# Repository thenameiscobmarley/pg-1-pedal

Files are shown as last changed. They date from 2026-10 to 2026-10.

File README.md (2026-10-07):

# PG-1 pedal

A DIY stereo audio pedal built around a **Daisy Seed3**, in a white Hammond 1590XX from Tayda. A 2.4" colour
touchscreen, four endless push-knobs, three footswitches and a chain of sound tools:

`in -> hum + hiss (with learn) -> input auto-level -> dynamic eq -> compressor -> multiband -> clarity + bass ->
saturation -> de-harsh -> stereo width -> takeback -> quiet loudness -> [bypass] -> ear + speaker safety -> out`

plus a visualizer, health checks (it tells you when something is wrong), 8 saved configs, a fair level-matched
A/B footswitch, and everything remembered over power-off.

The same core code runs on the pedal and in a **Carla / VST3 plugin** with a real-size 3D model of the pedal, so you
can try every screen and sound on a PC first.

## What's where

| Folder | |
|---|---|
| `PG-Pedal-1/01-Questions-and-Specs` | the spec |
| `PG-Pedal-1/02-Parts-and-Cart` | Tayda cart files + parts list (with the few parts Tayda doesn't sell) |
| `PG-Pedal-1/03-Drill-Template` | drill positions for drill.taydakits.com |
| `PG-Pedal-1/04-Top-Artwork` | the UV print (CMYK PDF for Tayda) and previews |
| `PG-Pedal-1/05-Wiring-and-Schematics` | **wiring-diagram.png** (every wire + both ground chains), layout drawings, WIRING.md |
| `PG-Pedal-1/06-Firmware-DaisySeed` | the firmware (`pg1/`) and its shared core (`pg1/core/`) |
| `PG-Pedal-1/10-Carla-Plugin` | the JUCE plugin with the 3D pedal |
| `PG-Pedal-1/11-Wiring-Bench` | `wiring-bench.html`: practise the wiring in a browser; a virtual pedal tells you what's wrong |
| `_Tools/pg_generate.py` | one script makes the drill table, artwork, drawings and the splash logo from the geometry at its top |
| `_Tools/tayda_upload.py` | uploads the drill + print designs to drill.taydakits.com (asks for your Tayda login) |
| `third_party/HardwareKit` | the 3D hardware UI module the plugin uses (Apache-2.0) |

## Building

Firmware (Linux):

```
git submodule update --init           # libDaisy v9.0.0 + DaisySP
cd PG-Pedal-1/06-Firmware-DaisySeed
(cd libDaisy && make -j"$(nproc)") && (cd DaisySP && make -j"$(nproc)")
cd pg1 && make -j"$(nproc)"           # build/pg1.bin (runs from the Daisy bootloader: see the firmware README)
```

Plugin: needs JUCE (https://juce.com, licensed separately).

```
cd PG-Pedal-1/10-Carla-Plugin
cmake -B build -DCMAKE_BUILD_TYPE=Release -DJUCE_PATH=/path/to/JUCE
cmake --build build -j"$(nproc)"
```

Artwork and drawings: `pip install fonttools`, then `python3 _Tools/pg_generate.py` (needs `rsvg-convert` and
ImageMagick for the PNG/PDF previews).

## Credits

- libDaisy and DaisySP by Electro-Smith (MIT), as git submodules
- Nunito font (SIL Open Font License, `_Tools/fonts/OFL.txt`)
- HardwareKit (Apache-2.0, `third_party/HardwareKit`)
- JUCE is not included; it has its own licence

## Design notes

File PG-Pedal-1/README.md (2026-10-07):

# PG-1: pg audio programmable stereo pedal (Daisy Seed3)

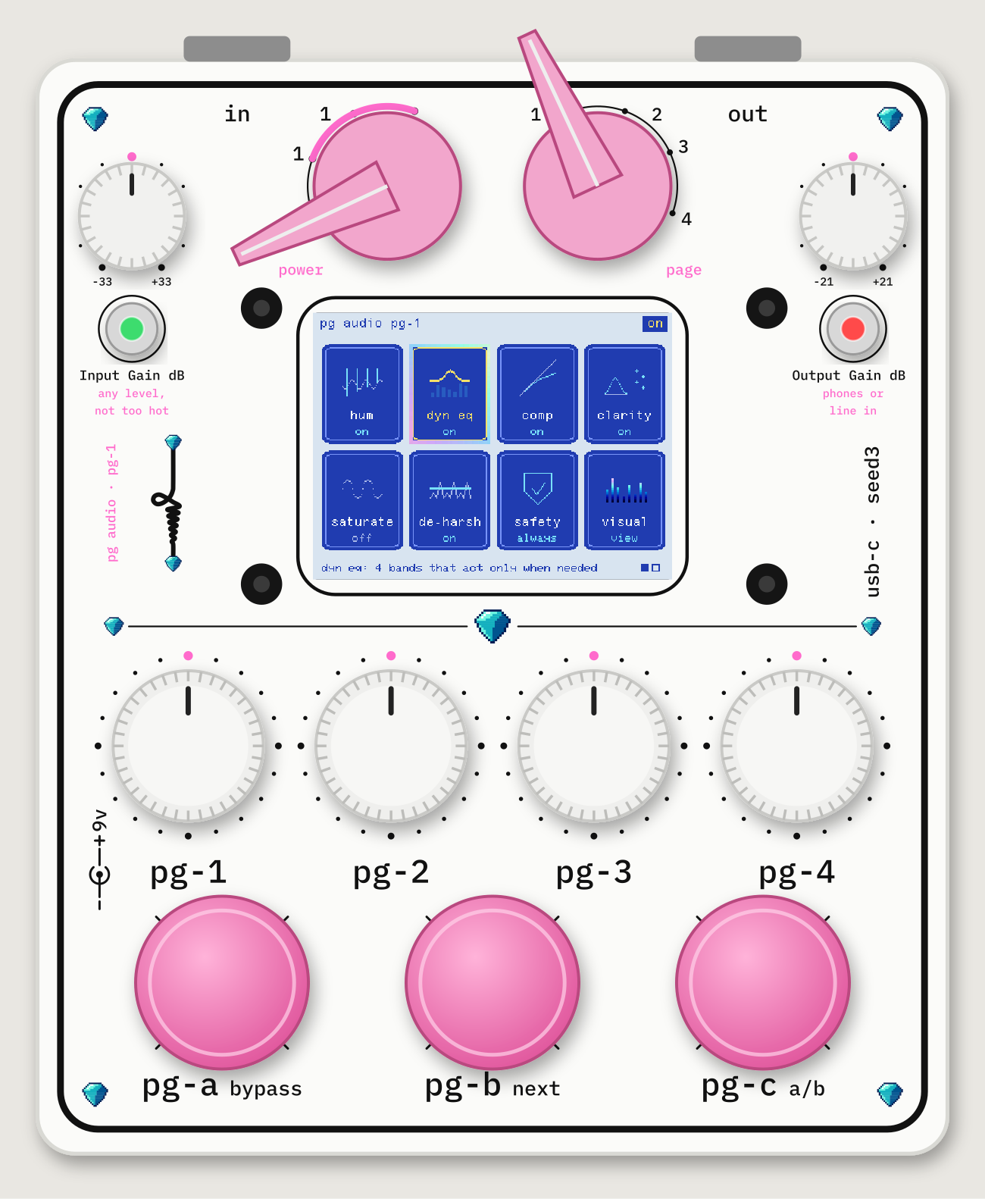
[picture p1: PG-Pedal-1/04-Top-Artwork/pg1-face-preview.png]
preview


## Order it (3 steps)
1. **Parts:** upload `02-Parts-and-Cart/tayda-cart-import.csv` on the Tayda cart page (Import → Add from file → Replace current cart).
   Buy the Seed3 (with headers), a 9V adapter and solder separately (`02-Parts-and-Cart/BOM.md`).
2. **Drilled box + printed top:** run `python3 ../_Tools/tayda_upload.py`. It logs in to your drill.taydakits.com account and creates
   the drill template (17 holes + screen window + Seed3 window) and the UV print template for you. Then check both previews on the dashboard and create the order there.
   (By hand instead: `03-Drill-Template/DRILL-ORDER.md` + `04-Top-Artwork/UV-PRINT.md`.)

## Build it
`05-Wiring-and-Schematics/WIRING.md` has one table: every wire from each part to its Seed3 socket pin. It also shows the plug-in Seed3 cartridge in the left wall and covers the first flash.
`06-Firmware-DaisySeed/pg1.bin` is ready to flash: a stereo delay with auto-leveling that uses every control.

Using it with your Fifine SC3 (line out → pedal → headset): `USING-WITH-FIFINE-SC3.md`.

## Try it on your PC first
`10-Carla-Plugin/` is the PG-1 as a VST3 for Carla (and a standalone app): a 3D pedal with the **same screen, knobs, touch and sound** as the real one, because both run the same core code. Installed at `~/.vst3/PG-1 Pedal.vst3`.

## Folders
| Folder | What's inside |
|---|---|
| 01-Questions-and-Specs | final spec + your answers |
| 02-Parts-and-Cart | Tayda import CSV, full BOM with prices |
| 03-Drill-Template | drill.taydakits.com entry sheet, CSV, 1:1 paper template |
| 04-Top-Artwork | UV print PDF, editable SVG, mockup |
| 05-Wiring-and-Schematics | wiring, interior layout, depth check, perfboard drill guide |
| 06-Firmware-DaisySeed | libDaisy project + libDaisy v9.0.0 + DaisySP |
| 07-Datasheets | Seed3, screen, encoder, footswitch, jack |
| 08-Build-Photos | for your photos |
| 09-Parts-Visualizer | Parts Bench page + 3D web model |
| 10-Carla-Plugin | the PG-1 as a VST3 for Carla + standalone app |

All drawings and the artwork are generated from one script (`../_Tools/pg_generate.py`), so the holes and the print always match.

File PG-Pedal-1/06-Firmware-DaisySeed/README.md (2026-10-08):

# PG-1 firmware

`pg1/` is a libDaisy project. The pin map lives in one block at the top of `src/main.cpp`; everything
else (screen, controls, DSP) is in `pg1/core`, the same code the Carla plugin runs.

## The tabs (in signal order)

Home page 1 has 8 tabs; page 2 (turn past the last tab, or tap the dots bottom-right) has **input**, **health**, **takeback**, **width**, **loudness**, **config**, **multiband** and **pid**.

`in -> hum -> input -> dyn eq -> comp -> multiband -> clarity -> saturate -> de-harsh -> width -> takeback -> loudness -> anti-duck -> [bypass] -> safety -> out`

**Will it fit on the Seed3?** Checked on an emulated Cortex-M7 with the firmware's own compiler flags (`_Tools/seed3-bench`:
`./build.sh && python3 seed3_load.py`, per tab: `python3 stages.py`). Worst case (every tab on, pid steering everything, clarity with
10 bands): ~5,900 instructions per sample = **~59 % of the audio time** at a typical 1 clock per instruction (~89 % if it were 1.5).
Default settings: ~51 %. The first version of these features measured 102-153 % (would not have run); fast exp/log, filters that
compute only the output they need, slower-rate detectors, a sliding-minimum limiter and skipping idle filters brought it down.
The plugin's cpu health check uses these numbers, so it warns when the pedal would.

**Anti-duck (always on, every stage):** nothing turns the whole track down because the bass got heavy.
- Every detector that can lower the whole sound (input auto-level, comp, de-harsh's comfort dip, loudness follow, the safety stage's ear meters and blast guard) listens through a steep 150 Hz high-pass, so bass doesn't count as "loud".
- The safety peak limiter splits at 120 Hz: a peak that comes from the bass is taken out of the bass alone (up to -12 dB); only what that can't fix lowers everything.
- A false "infrasonic out" mute on sudden loud bass notes is fixed (a slow wobble the limiter can leave is filtered out; that check now needs 1 s, not 0.3 s).
- A final guard compares the mids + highs coming out against going in. If they still dip while the bass is heavy, it lifts everything above 120 Hz back (at most +6 dB, before the safety limiter). Ordinary compression of loud parts is left alone, and it re-learns whenever you change a setting.
- Tested on a sudden heavy bass drop: the rest of the track used to dip 7-12 dB for a moment; now at most 0.3 dB. The *levels* view shows *bass lim* and *anti-duck* live.

| Tab | What it does | Knobs pg-1 / pg-2 / pg-3 / pg-4 |
|---|---|---|
| **input** (page 2) | Auto-level: brings any source to the same working level. Quiet ones go up (at most *boost*), hot ones down (at most *cut*). It moves slowly and holds still in silence, so it never pumps up noise. A yellow **in clip** chip shows in the title on every page when the source is hotter than the Seed3's input can take. Only turning the source down fixes that. | target / boost / cut / speed |
| **hum** | *auto / 50 / 60*: finds mains hum and notches it plus 5 harmonics, only as deep as the hum really is, and turns the top end down in quiet parts. ***learned***: set pg-1 to **learn** and push it (or tap **learn** on the screen) while **only the hum / hiss is playing**. In 3 s it learns every tone to the exact frequency (mains hum, monitor or charger whine) and the hiss level in 8 bands. Then it notches those tones all the way down and gates each band to silence whenever nothing louder than that noise plays. It tells you if music or talking spoiled the learning. Runs first, before the auto-level. | mode / hum depth / hiss cut / hiss threshold (learned: margin) |
| **dyn eq** | 4 bands, each moves when that band gets loud. | freq (hold + turn = q) / gain / thresh / range |
| **comp** | Smooth stereo compressor, soft knee, bass-safe sidechain, auto make-up, auto release. | thresh / ratio / attack / release (0 = auto) |
| **clarity** | Bass: *thump* (a short low lift on each kick), *detail* (the bass's own harmonics, so bass is heard on any speaker), *warmth* (a steady low lift). Clarity: **up to 10 bands that place themselves**. 20 detectors listen half an octave apart; where the sound bulges above its overall trend (a ringing note, a boxy spot) a band moves there and cuts, where it sags (a hollow) a band moves there and lifts. Each band glides its own frequency, width (q) and gain, so it follows the music. Bands stay between ~50 Hz and ~12 kHz. **Mode** (hold pg-1 + turn, or tap *mode*): *dynamic* (cuts and lifts), *add* (only lifts), *normalise* (stronger and slower). The graph shows each band as a dot with a bar as wide as its q (blue = lift, pink = cut). | thump (+dB per hit) / detail / clarity (most each band may cut or lift, dB; **hold pg-3 + turn = how many bands, 1-10**) / warmth (+dB lows) |
| **saturate** | Tape / tube curve, anti-aliased, level-matched. Off by default. | drive / even / tone / mix |
| **de-harsh** | After everything: finds harsh spots between 2 and 8.5 kHz and cuts just those, plus softens 3 kHz as it gets loud. | depth / sens / speed / comfort |
| **safety** | Always on, even in bypass: **only 20 Hz - 19.5 kHz can leave** (very steep filters at both ends; what's outside human hearing is removed, and if it ever reached the output anyway the pedal would mute and say so), woofer and tweeter power limits (coils stay cool), a long-term loudness cap for your ears, a blast guard for sudden jumps, a 1 ms look-ahead limiter and a hard ceiling. Broken numbers or a stuck DC level mute the output for 150 ms and reset every filter. | ceiling / ears / woofer / tweeter |
| **multiband** (page 2) | 4 bands (split at 120 Hz, 1 kHz, 6 kHz; the untouched bands add back to the original exactly). Each band holds back its own peaks, relative to its own recent level, so a boomy note, a muddy burst, a harsh hit or a sharp "s" gets tamed without touching the rest. | bass / low mids / high mids / highs (how firmly) |
| **takeback** (page 2) | Gives back what the processing took or buried, by comparing with the sound as it came in: the **punch** of hits the comp / limiter squashed, quiet **detail** (tails, room, breaths), top-end **air** that went missing, stereo **space** that shrank. Capped, so it restores rather than exaggerates. | punch / detail / air / space |
| **width** (page 2, off by default) | Wider or narrower stereo, bass kept in the middle (mono-safe), a little side air, and a guard that eases off if mono speakers would lose sound. | width / bass mono / air / guard |
| **loudness** (page 2, off by default) | At low volume ears lose bass and treble: this gives back about what they lose, more the quieter you listen (follow = quiet passages too). | listen / bass / treble / follow |
| **config** (page 2) | 8 saved configs (every sound setting + which stages are on). pg-1 picks, **push pg-1 = load**, **push pg-2 twice = save**. Theme: **pearl** (light, default) or classic **bios**. Knobs: normal / reverse. | config / save / theme / knobs |
| **visual** | Spectrum (in and out), waterfall, stereo (vectorscope + correlation + balance), levels (in / out + what each stage is taking off), **scope** (oscilloscope: the last 13 ms, triggered so a steady note stands still, auto-zoom), **bars** (31 bands with falling peak caps), **history** (in and out loudness over the last 15 s). Tap the screen for the next view. | view / fall / range / source |
| **pid** (page 2) | Listens to the processed sound and steers the settings of the groups you pick, on top of your own settings: **eq** (each band towards the target balance, ±6 dB), **comp** (threshold + ratio, towards a 12 dB peak-to-average, ±8 dB), **mband** (how firmly each band is held), **clarity** (thump / warmth + clarity, ±4 dB), **deharsh** (depth, ±6 dB), **width** (towards a correlation of 0.35, ±40 %). P reacts to how far off it is, I slowly clears what's left, D brakes fast swings; any of them can be 0.00 (all three 0.00 = no steering). In silence it holds still. Off by default (hold pg-b). The screen shows what it hears vs the target, and how far it is moving each group. | p / i / d / group (push = steer it or not; hold + turn = target tilt, dB per octave) |

The safety levels are dBFS at the pedal's output. They don't know how loud your amp is, so set them
once at a loud-but-comfortable volume: lower **ears** until it just starts easing down.

## Controls

| Control | Home | A page |
|---|---|---|
| turn a knob | move between tabs | the value in that knob's box (the boxes have the knob number in a cream chip) |
| hold a knob + turn | | fine steps (dyn eq pg-1: q) |
| push a knob | open the tab | flashes its box |
| **double-push** | | that value back to default |
| **long-push** (0.6 s) | | back to home |
| pg-a | whole-pedal bypass (safety stays on) | same |
| pg-b | next tab | dyn eq: next band. Other pages: next page |
| hold pg-b (0.6 s) | that tab's stage on / off | this page's stage on / off |
| touch | tap a tab to open it; tap "on" for bypass | tap "< home"; tap the on/off chip; tap a box = what it does; dyn eq: drag nodes, tap band chips, double-tap a node = gain 0; visual: tap = next view |
| pg-c | fair A/B: hear your untouched input at the same loudness (a cyan "a/b dry" chip shows); tap again to come back | same |
| touch d-pad (off by default) | turn it on in **config** (tap "touch d-pad", or hold pg-4 + turn), then **tap the title** to show it: arrows move between tabs, the middle opens | left / right pick a value box (yellow frame), up / down change it (hold to repeat), the middle = that knob's push (hold = home). Hides itself after 10 s |
| pg-a + pg-b held 2 s | USB flash mode | same |

## First power-up

After the logo, a short tour (4 cards, 3 s each) shows the basics: knobs, the 3 footswitches, page 2, the "!" chip. It only
ever runs once (any control skips it). The config tab's bottom line shows the model, firmware version and this pedal's ID.

## Saving

Everything (settings, the 8 configs, the learned hum / hiss) is saved to the Seed3's flash about 4 s after you stop changing
things, and comes back at power-on. The plugin keeps the same block in the DAW session.

Saves survive firmware and plugin updates: every setting is stored under a permanent name, so a new build that adds, removes
or reorders settings still loads your configs (new settings start at their defaults). When a setting's meaning changes, the
new build converts the old value. The pedal and the plugin use the same format.

## Start-up

On pitch black, the pg audio logo draws itself while slowly zooming out, "pg audio" fades in underneath, both fade away, and
the main screen fades up out of the black (about 4.5 s; any knob, switch or touch skips it). The logo is the exact curve on the
printed face (`core/PgLogo.h` is generated from `_Tools/pg_generate.py`).

## Health checks (page 2: **health**)

The pedal watches itself all the time. When something looks off, a **"! n"** chip shows in the title on every page (yellow =
warning, pink = fault; tap it to jump to the explanation), and on the home screen a one-line pop-up says what it is. The health page lists every check
with *what it thinks is wrong* and *what to try*. **sens** = relaxed / normal / **strict** (default: flags even a little weird);
**view** = now / how often since power-on.

It watches (19 checks): sound above or below hearing coming in (a quiet note: it's removed anyway), anything outside hearing reaching the output (muted), DC on the input, input clipping, one input side silent, inputs out of phase, no input,
the output limiter working hard, the ears guard acting, audio glitches (muted + reset), processor load, dropouts, a knob push stuck,
a knob turning by itself (loose wire), a footswitch stuck, the touchscreen stuck, and screen-link errors.

It **can't** see: the OUT jack wiring after the converter, the 9 V supply level, or a wire touching the box. Those are the one-time
multimeter checks in `USING-WITH-FIFINE-SC3.md`.

## Screen speed

The screen is driven over SPI at **48 MHz** ("fast", the default) with the Seed3 at 480 MHz: graphs and animations aim for
**60 fps** (the busiest pages use ~92% of the link, so expect about 55-60 fps there; the home screen and small changes are
a solid 60). A full-page change takes ~25 ms. If the picture ever shows wrong pixels or streaks (long or loose jumper
wires can do that at 48 MHz), set **config -> screen: safe** (24 MHz, 25 fps): hold pg-3 and turn, or tap it on the config
page. Keep the screen's SCK and SDI (MOSI) jumpers as short as you can. (48 MHz is above the ILI9341 datasheet's own
figure; these modules are commonly run at 40-80 MHz, and the display self-repair below re-sends everything anyway.)

## Display safety

- Every drawing call is clipped, and numbers that go bad (NaN) can't become screen coordinates, so nothing
  outside the 320 x 240 picture is ever sent.
- The panel's mode registers are re-sent every 2 s and every pixel once a minute. If static or a bad power
  moment scrambles the screen, it fixes itself. If SPI keeps failing, the panel is reset and redrawn.
- The backlight stays off until the first frame is drawn (no garbage flash at power-on). Before a reboot to flash mode the panel is put to sleep properly.
- **Display rest:** after 5 idle minutes the screen goes near-black with a small drifting "pg-1" (no static
  picture to burn in). After 20 minutes the backlight turns off. Any knob, footswitch or touch wakes it, and that first touch only wakes it (it doesn't change anything).
- Nothing sent over SPI can physically damage the ILI9341. The real risks are image retention and a
  scrambled panel, and the points above handle those.

## Memory: the Daisy bootloader

The program now runs from the Daisy bootloader. It is stored in the Seed3's 8 MB QSPI flash and copied into
480 KB of fast SRAM at power-on (same speed as before). All 8 tabs use 159 KB (33%) of it, so there is room
for a lot more. The screen picture (150 KB) lives in the 64 MB SDRAM. The old 128 KB internal flash would
have been full after one more tab: libDaisy alone takes ~80 KB of it.

The power-on wait is 2 s while the bootloader listens for USB, then the pedal starts.

## Setup (Linux)

```
# toolchain (once)
sudo pacman -S arm-none-eabi-gcc arm-none-eabi-newlib dfu-util make

# libraries are already cloned here: libDaisy (v9.0.0, adds Seed3 support) and DaisySP
cd libDaisy && make -j$(nproc) && cd ..
cd DaisySP  && make -j$(nproc) && cd ..

cd pg1
make -j$(nproc)          # builds build/pg1.bin (for the bootloader)
```

**Once:** install the Daisy bootloader. Hold BOOT, tap RESET (Seed3 is now in STM32 flash mode), then:
```
make program-boot        # writes the Daisy bootloader into the internal flash
```
**Every update:** within 2 s of power-on (or after pg-a + pg-b held 2 s, which waits forever):
```
make program-dfu         # writes build/pg1.bin to the QSPI flash through the bootloader
```
No tools? https://flash.daisy.audio can do both: "flash bootloader" first, then the program
(`../pg1.bin`).

Recovery is always possible: BOOT + RESET gets you the STM32's own flash mode, which nothing can overwrite.

Not yet confirmed: Electro-Smith's bootloader pages don't mention the Seed3. It uses the same STM32H750 and
also has an 8 MB QSPI flash, but I couldn't confirm the bootloader officially supports it. If the pedal
doesn't start after `make program-dfu`, do BOOT + RESET and `make program-boot` again, then tell me.

If the screen is upside down, set `kFlipScreen = true`. If touches land in the wrong place, change `kTouchSwapXY` / `kTouchFlipX` / `kTouchFlipY`. If a knob counts backwards, set `kReverseEncoder = true`.

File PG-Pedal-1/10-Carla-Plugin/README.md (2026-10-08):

# PG-1 Pedal (VST3 for Carla + standalone app)

Your PG-1 as a plugin: a real-size 3D pedal with the **same screen, knobs, touch gestures and sound
as the Seed3** (16 tabs over two home pages). Both run `06-Firmware-DaisySeed/pg1/core` (PgCore), so whatever you build or change
in the core shows up identically on the PC and on the pedal.

## Runs exactly like the Seed3
- The core always runs at **48 kHz in 48-sample blocks**, the same as the pedal (`main.cpp`: `SAI_48KHZ`, `SetAudioBlockSize(48)`),
  whatever rate and block size the host uses. Other host rates are resampled to 48 kHz and back; at 48 kHz samples pass through untouched.
  The plugin reports its delay to the host (96 samples at 48 kHz: one Seed3 block + the safety limiter's 1 ms look-ahead).
- The **health tab's cpu check shows the Seed3's load, not your PC's**: each tab's cost was measured on an emulated Cortex-M7 built
  with the firmware's own flags (`_Tools/seed3-bench`, table in `Source/Seed3Costs.h`), so the plugin warns exactly when the real pedal would.

## Use it in Carla
1. Build (below). The VST3 is copied to `~/.vst3/PG-1 Pedal.vst3` automatically.
2. In Carla: **Add Plugin → refresh → PG-1 Pedal**, connect your audio in and out.

## Controls (mouse)
| Do | On the pedal that's |
|---|---|
| drag a knob up/down | turn it (fast drag = big jumps, slow = fine) |
| shift-drag (or right-drag) a knob | hold it down while turning: fine (dyn eq pg-1: q) |
| click a knob / two quick clicks | push / double-push (reset to default) |
| mouse wheel on a knob | spin it |
| hold a knob click 0.6 s | long-push: back to home |
| click / hold a footswitch | pg-a bypass (safety stays on); pg-b next band / next page, hold = stage on/off |
| click / drag on the screen | touch: open tabs, drag eq nodes, tap a box = what it does, tap the on/off chip, tap the visualizer = next view |
| drag the background | look around |
| wheel on the background | zoom; double-click the background = reset view |

## Build
```
cd 10-Carla-Plugin
cmake -B build -DCMAKE_BUILD_TYPE=Release
cmake --build build -j"$(nproc)"
```
Needs `~/JUCE` and `third_party/HardwareKit` (the 3D hardware library). The standalone app is in
`build/PG1Pedal_artefacts/Release/Standalone/`.

## Changing the pedal
Edit `06-Firmware-DaisySeed/pg1/core/PgCore.cpp` (screen pages, parameters, gestures, DSP), rebuild
this plugin to try it, then rebuild the firmware (`make` in `pg1`) and flash it: same code, same result.

## The screen is the real resolution
The core draws into a 320 x 240 RGB565 framebuffer and pushes only the changed rectangles, exactly what goes
over SPI to the ILI9341. The plugin shows that buffer with no smoothing, so you see the same pixels (zoom
in with the wheel to read it, like leaning over the pedal).

## Latency
The safety stage's look-ahead limiter adds 1 ms; the plugin reports it to the host, which compensates.

## Display rest
Like the pedal: 5 idle minutes = near-black screen with a drifting mark, 20 = backlight off. Any control wakes it.

## Your settings stay
Like the pedal's flash, the plugin keeps everything (settings, the 8 configs, the learned hum / hiss) in
`~/.config/PG-1 Pedal/pedal-state.bin`: written about 4 s after you change something and when it closes, loaded when a
new PG-1 starts. A Carla project saved with its own PG-1 state still loads that state instead.

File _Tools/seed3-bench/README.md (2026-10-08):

# Seed3 load bench

Runs the pedal's real DSP core on an emulated Cortex-M7 (Unicorn) to see how much of the Seed3's time it needs.

    pip install unicorn pyelftools        # once
    ./build.sh                            # builds bench.elf with the firmware's flags (needs the Arm GNU toolchain)
    python3 seed3_load.py                 # worst case: audio load + a screen frame -> seed3-load.txt
    python3 stages.py                     # each tab's cost -> ../../PG-Pedal-1/10-Carla-Plugin/Source/Seed3Costs.h
    python3 profile.py [stage mask]       # where the time goes, by source line

The emulator counts instructions, not clock cycles (it has no timing model) and has no double-precision unit, so the maths
library's calls are costed with typical Cortex-M7 figures. Treat the result as an estimate (1.0 - 1.5 clocks per instruction);
the health tab on the real pedal measures the true load.

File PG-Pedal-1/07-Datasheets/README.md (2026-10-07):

# Datasheets

Not stored here (they belong to their makers). Get them from:

- Daisy Seed3: https://daisy.audio (Seed3 datasheet and pinout)
- Tayda parts (A-1091 footswitch, A-1121 jack, A-6331 encoder, A-8180 screen): each part's page on https://www.taydaelectronics.com
- SparkFun CAB-15455 USB-C panel cable: https://www.sparkfun.com

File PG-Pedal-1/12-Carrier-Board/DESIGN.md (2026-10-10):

# PG-1 carrier board (v3: isolated)

One board, made and fully assembled by JLCPCB (every part, the 2 jacks too) from the files in `jlcpcb/`. It hangs
from the nuts of the two 1/4" jacks on the top wall (no extra screws) and does all of the pedal's audio.

**One stereo input, one stereo output, both isolated:** nothing you plug in has a wire path into the pedal (or into
the other jack's gear through the pedal's power), not even ground. The audio crosses to the Seed3 as digital data.

```
            ISOLATED SIDE (its own power, ground IGND)                   |  PEDAL SIDE (9 V, ground GND)
in jack ─ TVS ─ 1k ─ 100 nF ─ 1M/1M ÷2 ─ TLV9062 buffer ─ pg-line stage (−33..0..+33 dB) ─ ÷3 ─► codec IN2 (fixed gain)
                                     TLV320AIC3204 codec ◄═ I2S ═╪═ ISO7741 ═╪═ Seed3 SAI2 (pins 32-35)
                                                         ◄═ I2C ═╪═ ISO1540 ═╪═ Seed3 I2C1 (pins 12, 13): set-up only
codec line out ─ 4.7k ─ [LDR to ground, lit by the leveller's LED] ─ TLV9062 follower ─ 4.7 µF ─ pg-hp stage (−21..0..+21 dB) ─ TPA6139A2 ×2 ─ 1 Ω ─ TVS ─ out jack
power: B0505S (isolated 5 V, across the barrier) ─ LP2985 3.3 V ─ codec / headphone amp; filtered 5 V ─ buffer
```

## What's hardware and what's software
- **Both levels are analog.** pg-line (input gain) and pg-hp (output gain) are centre-click dual LINEAR pots that set
  the gain of op-amp stages in the signal path: the pot sits between two end resistors in an inverting stage, so
  gain = (R_end + R_one side) / (R_end + R_other side). **Centre click = unity** ("whatever comes in goes out,
  processed"); left = less (to −33 / −21 dB), right = more (to +33 / +21 dB). The face print's dots show the dB.
- **Hardware only (no software can change it):** both levels, the isolation (ISO7741, ISO1540, B0505S and a no-copper
  strip across the board), the overvoltage clamps on both jacks, the 1 kΩ current limit on the input, the output ceiling
  (~1.1 V rms: the output chips run on 3.3 V), the headphone amp's short-circuit / thermal shutdown, the fuse,
  reverse-polarity and surge protection on 9 V.
- **The analog leveller (2026-10-09):** between the codec's line out and pg-hp. Per channel: 4.7 kΩ in series, then an
  LDR to ground (through 10 µF, so the codec's DC stays off it), then a TLV9062 follower (U16, 2 x 2 mm WSON: it fits
  under the DC jack). Each LDR is lit by its own red LED (OC1 / OC2: a 3 mm flat-top LED pressed on a 5 mm LDR in black
  heat shrink, on the lid side, the only parts you make). The two LEDs are in series from the isolated 5 V, so both
  channels get the same light; an MCP4725 DAC (U15, isolated I2C 0x60) sets their current through an NPN (Q1):
  I = (Vdac − 0.65 V) / 100 Ω, ~8 mA at most. The DAC powers up at 0 V: dark LDRs (megohms) = the sound untouched.
  The firmware (pg::AnalogLeveller) rides it 2:1 above −14 dBFS rms. Added to the routed board by add_leveller.py
  (+ place_extra.py / route_one.py for R81 / R86 and two links Freerouting gave up on).
  100 kΩ across each LDR (R81 / R86): the 10 µF charges in ~1 s; with the LDR alone (~1 MΩ dark) it took ~10 s and the
  first squeeze after power-up thumped (found by the simulation). The firmware also keeps it dark for 10 s.
- **fx loop (J22):** stays on the board but **open**: the leveller's followers drive its returns (r l, r r), so a
  bridge would short a follower's output to the codec's. Its 3v3 / gnd / scl / sda are still there for an add-on.
- **Software:** only the codec's one-time set-up (fixed gain, no auto-ranging), an add-on board's settings (if any) and the DSP. If the firmware hangs, a
  hardware watchdog resets the Seed3 in ~2 s and the codec mutes itself when the digital audio stops. If the input is
  too hot for where pg-line is, the screen's health page says "input clip": turn pg-line left.

## Checked by simulation (10-Carla-Plugin/Source/sim, the routed board's real netlist)
- Powers up to +9V 8.22, +5V 5.00, +3V3 3.30, iso 5V 5.05, iso 3V3 3.30, bias 1.65 V; ~197 mA from the 9 V.
- Input (centre click): flat 100 Hz - 20 kHz, clean up to ~2.2 V rms at the jack; pg-line -34 .. +29 dB.
- Output (centre click): 0 dB, flat, ~1.9 V rms / 115 mW into 32 ohm, ~2 V rms into a mixer, ~1 mV DC; pg-hp +-20 dB.
- **C31 / C41 are NOT fitted** (their pads stay empty): 100 pF on the input's 500 k bias divider made a 3.2 kHz
  low-pass (-13 dB at 10 kHz). Found by the simulation; radio is still kept out at the jack.

## Levels
- **In:** guitar (sees ~670 kΩ, like any pedal), a line output, a headphone output (up to ~2 V rms) or a mic (pg-line
  turned right). Mic quality is "works", not studio (the guitar-friendly input adds some hiss at full gain).
- **Out:** headphones (16-600 Ω) or a line input.
- **Pots:** dual 10k LINEAR, panel mount: Tayda **A-8618** (Alpha RD902F, 9 mm, 7.5 mm hole; no centre click, the middle = unity). (Before: Alps RK09L1240015 with a click; dropped with Mouser.) Or Bourns
  PTM902-125S-103B2. Both gangs used (left / right). Each header pin is labelled with the pot pin that goes on it: pot pin 3 (the clockwise end) on header pin 1, so turning right = more.

## Headers (male, 2.54 mm, right-angle: they point off the board's edge so the jumpers lie flat)
- **seed3 + 9v** (10, pedal side): dc +, dc − (from the panel DC jack), then vin → Seed3 39, gnd → 40, scl → 12,
  sda → 13, sck → 35, fs → 34, tx → 33, rx → 32.
- **pg-line** (6, isolated side, under the in jack): printed 3 l, 2 l, 1 l, 3 r, 2 r, 1 r = the pot pin for each header pin, left gang then right.
- **pg-hp** (6, isolated side, under the out jack): the same for pg-hp.
- **fx loop** (2 x 4 straight, isolated side): s l, r l, s r, r r, 3v3, gnd, scl, sda. Leave it open.
- **expansion** (4, pedal side, left of seed3 + 9v): 3v3, gnd, scl, sda (the Seed3's I2C) for a module in the
  expansion bay (a slot in the left wall with 4 glued jumper ends).

## The board
- **Two worlds:** the isolated side is the strip under the jacks (and the tongue above the dashed barrier line); the
  pedal side is the tongue below it. Only the three barrier parts cross the line. Each side has its own ground pour.
- **Jobs in boxes:** every part sits in its job's printed box (input, codec, fx loop, output, iso power, isolation, power),
  arrows show the signal's path, inputs on the left, output on the right (as you look at the pedal's face).
- **All parts on the top side** (with the jacks): JLCPCB assembles one side.

## Headers: soldered (the holes hold them straight first)
The 5 header footprints have **press-fit ("locking") holes**: every other hole sits 0.127 mm off the line, so a
plain 2.54 mm header strip grips by friction and stays straight and flat while you solder it. They're soldered (your
choice: the pedal gets moved and knocked around), not just pressed in.

## You solder the through-hole parts (big pins, easy)
JLCPCB fits every small part. You solder the 2 jacks (Neutrik NMJ6HFD2) and the B0505S-1WR3 power block (4 pins),
from the printed (top) side, the headers, and the leveller's 2 LED + LDR pairs (from the back). The
fx loop stays open. Leaving them off the order saves their per-part-type fees and the hand-soldering charges.

## Ordering at JLCPCB
Files in `jlcpcb/` (`python3 make_bom.py && python3 make_board.py && python3 make_jlc.py`). At https://cart.jlcpcb.com/quote:
1. "Add gerber file" -> `pg1-carrier-gerbers.zip`. Board settings as in the chat (2 layers, 1.6 mm, 5 pcs; black for looks).
2. **PCB Assembly**: Economic, **Top side**, PCBA qty: the lowest it allows, Confirm Parts Placement: Yes.
3. BOM -> `pg1-carrier-bom-jlc.csv`, CPL -> `pg1-carrier-cpl-jlc.csv`. Every part should show as matched.

## The jacks (Neutrik NMJ6HFD2: plastic nose)
- 1/4" stereo TRS. The **plastic** nose means the jack's sleeve never touches the metal box: that's what keeps the
  isolated ground isolated. Top-wall holes 11.2 mm (+ powder coat), same pins as the NMJ6HCD2 (KiCad footprint
  `Jack_6.35mm_Neutrik_NMJ6HFD2_Horizontal`), jack centre 8.14 mm above the board.
- Top wall: in -34, 9v -13 (panel DC jack, above the board), out +34 (clear of the box's corner lid-screw posts).

## Old versions
`carrier_v2.py` = the 4-jack analog board (line in, line out, no amp, phones), not isolated.

## Changed after the scenario simulations (2026-10-09, values only, no re-route)
- **R33 / R43 1M -> 470k** (C25790, preferred part): the input divider is x0.32, not x0.5; clean input up to ~3.4 V rms
  (was 2.1 V rms: a +10 dBu pre-amped source clipped).
- **R34 / R44 20k -> 4.7k**: x0.68 to the codec, not x1/3; the ADC's top 8 dB were never used (more hiss). Now
  pg-line's stage clips just before the ADC's full scale. Firmware kInGain = codec volts per jack volt = 0.1883.
- **D63 (1N4148WS, C2128) + R70 470k -> 1M**: with the power switch, off then quickly on left C73 charged and the
  headphone amp un-muted at once: a ~1 V thump. D63 empties C73 when the power goes; the jack now moves < 1 mV.
- Header holes re-centred in their pads (the press-fit offset is gone: the headers are soldered).

## Hard limits (2026-10-09, user: "if the DSP ever glitches it physically can't output that")
- **Bias centred: R6 10k -> 3.3k** (IBIAS 2.48 V, the middle of the op-amps' 5 V). Every stage swings the same both
  ways; the input buffer is clean to ~5.4 V rms at the jack.
- **Input clamp = R34 / R44 20k** (with R35 / R45 10k and the codec's 20k): whatever the pg-line op-amp does, even
  slammed rail to rail right after a long one-sided hit (the 1 uF in front of the pin remembers the hit), the codec's pin
  stays inside -0.02 .. +1.85 V (safe window -0.3 .. AVDD + 0.3 = 2.1), checked in ngspice over hits of 5-150 ms,
  +-12 / +-24 V, released or reversed, the isolated 5 V up to 5.3 V. (12k let it reach -0.42 / +2.26 V; Schottky
  clamps at the pins didn't fit.) The analog clips at about -7 dBFS of the ADC, so the Seed3 never gets an over.
- **Output ceiling**: the headphone amp runs on +-3.3 V (its own charge pump): the jack can never pass 3.0 V peak =
  2.1 V rms, whatever the DSP or a codec register does (86 mW into 50 ohm). The firmware also checks the codec's line
  out / DAC / PGA gains every second and puts them back (IsoCodec::Guard, PGA never above 20 dB).
- **The leveller can only cut** (an LDR shunt), its LED current tops out at ~11 mA (LEDs rated 20 mA).
- **Guitar**: R31 / R41 not fitted: the input is 1.46 Mohm, flat to 10 kHz (with them 595k, ~2.4 dB less sparkle).
- The 9 V jack moved to the left wall: nothing hangs over the board now (DC_ZONE empty).

## Headphone power cap (2026-10-10, user: "even if the user cranks both gains it can't destroy the headset")

R50 / R60 (the series resistors between the TPA6139A2 and the out jack) went from 1 ohm to **47 ohm** (C23182, 0603,
value change only: no re-route). The TPA6139A2 swings at most 3.0 V peak (2.12 V rms, its +-3.3 V charge pump) and
limits at 60 mA (TI datasheet). Worst case, both knobs full up, output clipping:

| load | V rms at the phones | sine | hard-clipped square |
|---|---|---|---|
| 16 ohm | 0.54 V | 18 mW | 36 mW |
| 32 ohm | 0.86 V | 23 mW | 46 mW |
| 50 ohm | 1.09 V | 24 mW | 48 mW |
| 300 ohm | 1.83 V | 11 mW | 22 mW |
| 600 ohm | 1.97 V | 6.4 mW | 13 mW |
| 10k (line in) | 2.11 V | - | - |

The most any load can take is at 47 ohm: 2.12^2 / (4 x 47) = 24 mW. Before (1 ohm) a 50 ohm headset could get 90 mW
(180 mW clipped). Cost: 47 ohm output impedance (IEC 61938 allows 120 ohm); 600 ohm phones lose 0.65 dB. A mono plug
(shorted ring) with everything cranked puts up to 85 mW (sine) / 170 mW (square) in the 0.1 W resistor: it may burn open,
the channel goes quiet, nothing else is harmed.

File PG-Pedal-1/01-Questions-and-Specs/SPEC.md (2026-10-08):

# PG-1 spec (decided 2026-10-06)

| Topic | Decision |
|---|---|
| Brain | Daisy Seed3 (STM32H750, 65MB, TAC5242 codec, USB-C), libDaisy v9+ |
| Enclosure | Tayda 1590XX **white** (A-5883), 145 × 121 × 39 mm, drilled + UV printed by Tayda |
| Controls | 4 endless push-encoders **pg-1 ... pg-4** (20 detents) |
| Footswitches | 3 soft-touch **momentary** A-1091 (pressed = on, released = off) **pg-a, pg-b, pg-c**, all programmable |
| Screen | 2.4" color **touch** TFT 240×320 ILI9341 + XPT2046 (A-8180), bolted with 4 M3 screws |
| Audio in | 1/4" **TRS stereo** straight into the Seed3 (line level, max ~1 Vrms). **Auto-leveling in firmware** (−12 to +40 dB, gated) |
| Audio out | 1/4" **TRS stereo** straight from the Seed3 (0 dBFS = 1 Vrms) |
| Power | 9V DC center-negative straight to the Seed3 VIN (reverse-protected on the Seed3) + USB-C. Screen powered from the Seed3's 3.3 V |
| USB-C | The Seed3's own USB-C, on the cartridge sticking out of the LEFT side (hold pg-a + pg-b for 2 s = flash mode; BOOT/RESET reachable too) |
| Layout | Screen at the top, then pg-1 · pg-2 · pg-3 · pg-4 in a row, then pg-a / pg-b. Jacks on the top edge, left to right: in · 9v · exp (spare) · out; USB-C on the left side |
| Look | All text lowercase in a rounded font (Nunito), everything black on white, smooth rounded border ring, one-line logo + "pg audio" |
| Mounting | Panel parts clamp with their own nuts; the screen uses 4 M3 screws. **Seed3 cartridge:** the Seed3 stands on its edge in a window in the left wall and plugs into 2 female headers on a small socket board screwed inside (swap = pull out, push in, no soldering). Every part is wired to that socket board. Nothing on the bottom edge |
| Build | **Seed3 only, no resistors, capacitors or chips**; every part wired to the Seed3 socket board |

## Answers from the question rounds
1. Size 1590XX · power: you weren't sure, so 9V jack + USB with protection · input: "anything" · USB: panel/cutout
2. Gain knob on top · screen 1.8" (later changed to 2.4" because the 1.8" can't be screwed down) · perfboard · black skirted knobs
3. Layout "screen top, knobs row" · footswitch labels pg-a/pg-b · a one-line logo + tagline "pg audio" · rounded font
4. 2.4" screen with holes · USB-C via a panel extension (no bottom-plate mods) · Seed3 + 9V adapter bought separately

5. Only the Seed3 board (no extra parts) · gain knob → pg-4 · auto-leveling · normal gear on the output · add a soldering iron · stands on end, so nothing on the bottom

8. No board/sheet: jumper wires straight onto the Seed3, Seed3 on its back, USB-C panel cable back, pinholes removed
7. Touch wired · BOOT/RESET pinholes in the top · dock super-glued to a removable plastic sheet
9. Seed3 as a cartridge in the left wall: socket board + 2 female headers, keyed by snipping pin 1; the USB-C panel cable and foam tape are gone
6. Screen higher, knobs lower · Seed3 socketed, sideways, USB-C out of the left side · bottom-plate tape mount · spare exp jack + expansion header · no USB MIDI · no headphone amp (HD 599 SE is fine)

## Limits to know
- Condenser mics need phantom power, which this pedal doesn't have. Dynamic mics are fine.
- A passive guitar plugged straight in sounds a bit duller (there's no 1 MΩ buffer). A buffered pedal in front fixes it.
- Dynamic mics work, but auto-leveling lifts some hiss with them.

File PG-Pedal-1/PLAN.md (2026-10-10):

# PG-1 plan (resume here)

Carla plugin + shared core (started 2026-10-06)
- [x] 1. Shared core: 06-Firmware-DaisySeed/pg1/core (PgCore.h/.cpp, Canvas.h) - knobs, touch, footswitch, screen, DSP; no libDaisy hardware
- [x] 2. Firmware main.cpp becomes a thin wrapper around the core; build passes
- [x] 3. Plugin project 10-Carla-Plugin (JUCE VST3 + HardwareKit), processor runs the core
- [x] 4. 3D view: shell, printed face, live screen texture, knobs, footswitches, jacks, desk
- [x] 5. Mouse: knob drag/click/wheel, footswitch press, touchscreen, camera orbit/zoom
- [x] 6. Build, install to ~/.vst3, screenshot check, docs

Dynamic EQ + BIOS/aurora UI (2026-10-06)
- [x] 7. Core rewritten: BIOS blue/grey, pearl aurora bleed (boot, tab open, page wipe, value change), 8-tab home
- [x] 8. 4-band dynamic EQ + 1024-pt FFT spectrum; core keeps its own 320x240 framebuffer, dirty-rect Blit
- [x] 9. Firmware + plugin on the new API, LCD texture NEAREST (true pixels), native frame test, docs
- [x] 10. All 8 tabs working: hum, dyn eq (+ q), comp, clarity (replaces delay), saturate, de-harsh, safety (replaces limit), visual (replaces meters); reverb + setup dropped for now

Room + safety (2026-10-07)
- [x] 11. Daisy bootloader (BOOT_SRAM): 159 KB of 480 KB; framebuffer in SDRAM
- [x] 12. Hard-edged white / cream / pearl outline animations (composited at push time, never in the picture)
- [x] 13. Display safety: clipping, NaN-proof coordinates, register refresh, repush, SPI fault reset, rest + backlight off
- [x] 14. Eq: q (hold pg-1), knob chips, live thresh meter + range bar, threshold line + range rail on the graph, help line
- [ ] 15. Try the bootloader on the real Seed3 (not confirmed for Seed3 yet)
- [x] 16. Second home page (dots bottom-right), first page-2 tab: input auto-level + in-clip warning
- [x] 17. Jacks swapped: in on the LEFT, out on the RIGHT (drill CSV, print, plugin texture, docs) - re-upload to Tayda
- [x] 18. fs-3 footswitch (right, pin D9) = fair A/B; row re-spaced to -36 / 0 / 36, y -50; usb-c label vertical, level with the socket
- [x] 19. Health checks tab (16 checks, title chip, pop-ups, explanations) + two ground chains (audio -> pin 20, main -> pin 40)
- [x] 20. Start-up logo animation (PgSplash.cpp + generated PgLogo.h)
- [x] 21. Hum learn mode (PgLearn.cpp): exact tones + 8-band hiss floor, notch + gate; plugin saves the profile
- [x] 22. Hearing range only: 8th-order 20 Hz HP + 16th-order 19.5 kHz LP; in/out detectors, mute on escape; 4 health checks
- [x] 23. Wiring diagram: two ground chains drawn step by step; screen box split around fs-3
- [x] 24. Pedal keeps settings / configs / learned profile over power-off (QSPI 7 MB, PersistentStorage; PgState.cpp)
- [x] 25. Clarity modes (dynamic / add / normalise), takeback, width, loudness, config tab (8 slots), pearl theme
- [x] 26. Polish: face (9v polarity mark, fs jobs, brand + model), firmware 1.0 on the splash, about line, first-power-up tour, page titles
- [x] 28. Wiring bench: 11-Wiring-Bench/wiring-bench.html (artifact https://claude.ai/artifact/67aSXRn4dnsirR5RoWpt1i), built from bench-template.html + the diagram
- [x] 29. Multiband dynamics (LR4 split 120 / 1k / 6k, per-band adaptive compressors)
- [x] 30. Public repo (made by _Tools/export_repo.py: scrubbed, brand 'pg audio', checks for personal info before finishing)
- [x] 31. Version-proof saves (format 2): settings/tabs stored by permanent name (PgState.cpp kRestKeys/kTabKeys), per-setting versions + Migrate(), format 1 still loads; state block 4 KB
- [x] 32. Touch d-pad mode (config, off by default; tap the title to show; no new parts - a physical d-pad didn't fit the 1590XX)
- [x] 33. Screen link 6 MHz -> 48 MHz (PLL1Q 192 MHz / 4, pins high speed, 480 MHz boost), UI paced at 60 fps, live numbers 15/s, config screen fast/safe
- [x] 35. Fixes: false 'infrasonic out' mute on loud sudden bass (output checks now need a sustained leak: 0.3 s / 0.1 s, detector 5 Hz); plugin keeps its state in ~/.config/PG-1 Pedal (configs survive reloading the plugin)
- [x] 36. Seed3 cartridge: stands on its edge in a 19 x 52 window in the left wall, plugs into a socket board (2 female headers, 2 M3 screws), keyed by snipping pin 1; USB-C panel cable + foam tape removed; drill/print/drawings/BOM/3D model updated
- [x] 37. PID tab (auto-adjust: steers eq / comp / mband / clarity / deharsh / width with user P, I, D; safe ranges; holds in silence) + visualizer scope, bars, history
- [x] 38. Clarity: up to 10 self-placing bands (own freq / q / gain, cut or lift, 20 detectors, detrended); anti-duck everywhere (bass-free detectors, bass-first safety limiter, false infrasonic mute fixed, final duck guard): onset dips 7-12 dB -> <= 0.3 dB
- [x] 39. Seed3 load checked on an emulated Cortex-M7 (_Tools/seed3-bench): was 102-153 % worst case, optimised to ~59 % (defaults ~51 %); plugin runs the core at 48 kHz / 48-sample blocks and reports the Seed3 load
- [ ] 40. (decide) carrier PCB: line/instrument input buffers, headphone amp, ESD/over-voltage protection, pin headers (PCBWay/JLCPCB assembly)
## v2 redesign (decided 2026-10-08, in progress) - resume here
Decisions from the user (question rounds):
- Carrier PCB, made + assembled by PCBWay from files we generate (Tayda doesn't make custom PCBs). Hangs from the top-wall jack nuts
  (PCB-mount 1/4" TRS jacks: Neutrik NMJ6HCD2, fitted by JLCPCB): no extra screws.
- Top edge jacks (all 1/4" TRS): line-in, line-out, headphones, no-amp, + 9V. The exp jack is dropped.
- no-amp = the processed sound at the same loudness that came in (unity gain), through a clean buffer that can drive a headset.
- Headphone amp: very low noise, drives 50 ohm now and 200 ohm later, max +12 dB over line (~4 V rms) -> needs more than a 9 V single
  supply (plan: charge-pump -9 V, filtered, OPA1622-class amp).
- Two small knobs LEFT of the screen: top = headphone volume (analog, silent .. +12 dB), below = line-out level (analog).
  They need the left wall free -> the Seed3 cartridge moves to the right wall.
- Footswitches renamed pg-a, pg-b, pg-c (every control starts with "pg-", from one naming rule); pink footswitch caps;
  the 4 knobs stay white knurled aluminium.
- Plain monospace, terminal-like lowercase font for some text (my choice where); keep the diamonds, don't overdo shapes / black ink,
  pink accents allowed if they don't look out of place.
- Screen: fancier, more spacious, touch-smart; tabs can have more than 4 settings: swipe the 4 boxes sideways as a page, with page dots
  (knobs always work the boxes you see).
Steps:
- [x] a. parts: A-6980 10k log dual pots, A-8567 14 mm white ripple knobs, Neutrik NMJ6HCD2 jacks (on the carrier board), A-2599 pink KN2310 caps (fit PBS-24)
- [x] b. layout: Seed3 window on the right wall (side E - CHECK in Tayda's preview), pg-hp / pg-line pots left of the screen, 5 top-edge holes; face print with IBM Plex Mono small words + pink accents (not uploaded to Tayda yet)
- [x] c. firmware/UI: names from one rule (ui::KnobName / FootName), 2nd settings page (swipe the boxes, tap the dots, slide animation), drag a box up/down to change it, rounded boxes / tiles / strip (more polish possible)
- [x] d. carrier PCB (budget version): circuit (12-Carrier-Board/DESIGN.md, carrier.py), board made by make_board.py
        (KiCad 10 + Freerouting: all parts on the bottom, fully routed, 0 DRC errors), PCBWay files in 12-Carrier-Board/pcbway/
        (Gerbers zip, BOM, CPL); ~$55-80 for 2 assembled boards. Next: user orders (jacks: send to PCBWay or fit later)
- [x] g. AUDIT + FIX before ordering (2026-10-08):
        DONE: JLCPCB CPL rewritten (make_jlc.py: from the board, Gerber coordinates, THT parts = centre of pins,
        rotation fixes from jlc_rotations.csv = JLCKicadTools table; BOM one line per LCSC part -> no "matched twice").
        Jack = NMJ6HFD2 official drawing: pins 4.35/10.7/17.05 mm from panel (was 16.7: fixed JACK_T), axis 8.29 mm.
        Hammond 1590XX drawing: corner lid-screw posts at +-51/+-63 -> jacks moved to +-34, 9v to -13 (pg_generate
        SIDE_B + plugin sideB), board top corners notched (POST_X 45, POST_Y 57). Passives -> 0402 (JLC basic).
        B0505S datasheet: body sits to ONE side of pins -> footprint courtyard both sides, U3 at x 21.
        Flat-only zone under the DC jack (DC_ZONE). Checked OK: AMS1117, PESD15VL2BT, SMAJ12A, LP2985, ISO7741,
        ISO1540, AIC3204, TPA6139A2, OPA1652 pinouts; encoder M7 (7.2 hole), screen holes/window, pots RK09L (M7, snap
        off the lug, female jumpers fit its pins).
        LAST ROUTE: 0 unconnected, isolation OK, but 2 courtyard overlaps: pot headers J20/J19 (row y 44.5) touch the
        jack courtyards (jacks moved in + JACK_T 17.05). Fix idea: header rows at y 44.2 and copper-edge clearance 0.3
        (make_board.py: m_CopperEdgeClearance + write_project min_copper_edge_clearance), then re-route.
        NEXT: check DRC (0.127 rules in .kicad_pro) + check_isolation.py; python3 make_bom.py && python3 make_jlc.py;
        Tayda upload (drill + UV: holes MOVED) via _Tools/tayda_upload.py with the saved ids; rebuild plugin;
        export_repo.py (PG_PY = venv with fonttools) + push; tell user: re-upload all 3 JLC files, Standard + Top side,
        Confirm Parts Placement yes, send screenshot of JLC placement preview to check rotations.
        MODULE BAY + ANALOG FX (user: "Connector + one analog effect", bay in the LEFT wall, filter + VCA) DONE in
        code: MCP4461 quad digipot U13 (0x2C, C638707; datasheet pins checked) = per side attenuator + rheostat into
        10 nF C0G (C22400107) low-pass, TLV9062 VSSOP buffer U15 (C398356), between codec LO and pg-hp. J21
        "expansion" 4-pin RA header (3v3 gnd scl sda, C32713263) left of J10 (J10 moved to x 3.5). Board: "analog fx"
        box right of iso power, output box only upper, codec narrower, isolation title bottom-right. Firmware
        AnalogFx (isoaudio.*): Init = unity/open (+ NV EEPROM), SetLevel / SetCutoff; builds. pg_generate: side C
        "expansion bay" 4.0 x 11.9 slot at Y 17 (Tayda CSV + drill SVG). Docs updated (DESIGN, WIRING).
        DONE 17:20: routed 100 %, check_isolation OK, DRC only 3 courtyard-MARGIN overlaps (J21/J10, J19/J2, J20/J1:
        real plastic gaps ~0.7 mm, accepted); jlcpcb/ files remade (38 kinds, 107 parts, all with LCSC codes); Tayda
        drill + UV templates updated; plugin rebuilt; repo exported (id regex fixed: no false hit on coordinates) +
        pushed. NEXT: user re-uploads the 3 JLC files and orders; Mouser pots.
        COST CUT (user: $50 max before shipping, must stay isolated + quiet + safe): analog fx REMOVED (firmware
        driver kept for an add-on); J22 "fx loop" 2x4 vertical header (LO -> FXR, jumper caps; iso 3v3/gnd/scl/sda)
        for add-on boards; PSM712 (basic C32677) for D2/D61/D62; C30/C40 -> 100nF 0402 basic; THT parts (J1 J2 J10
        J19 J20 J21 J22 U3) first skipped, then user said NO soldering: all fitted again (J22 = C32713277). Re-route + DRC, make_jlc, tell user (cheap shipping: Global Standard Direct Line, watch tariff).
        COST CUT 2 (user: ~$50 total incl. shipping, slight IEM hiss OK): OPA1652 x3 -> TLV9062IDR (C398355, same
        pinout, RRIO, CMOS input); LP2985 x2 -> XC6206P332MR (basic C5446, SOT-23: 1 GND 2 OUT 3 IN; bypass caps
        C5/C13 removed); THT parts SKIPPED again (user solders 8: jacks, headers, B0505S). Estimate ~$50 + $8.47.
        IL300 through-hole redesign was costed and dropped (~$65-70, hissier, may not fit).
- [x] f. v3 carrier = ISOLATED CODEC (decided 2026-10-08, replaces the 4-jack analog board; resume here).
        DONE: carrier.py netlist (87 parts, barrier check), PG1:DCDC_SIP4_B0505S footprint, firmware (src/isoaudio.*:
        codec + ADS1015 drivers, SAI2 + I2C1, pins moved, touch polled, auto-ranging + too-hot mute, health checks
        C_HOT / C_CODEC; builds), face print (in / 9v / out, pg-line = input gain -12..+24), WIRING.md v3 note,
        plugin 3D model (3 holes, black plastic jack noses; NOT rebuilt yet). make_board.py adapted (two domains,
        barrier keepout, per-domain pours, groups / flow arrows); placement run in progress.
        CHANGED (user wants safety analog, not software): pg-hp is now a REAL analog pot in the isolated output
        (codec LOL/LOR -> 4.7 uF -> pot -> TPA6139A2 x-2 -> jack; J19 6-pin header on the iso side under the in jack);
        firmware: IWDG watchdog (2 s), codec DAC auto-mute on DC, fixed unity digital output gain.
        CHANGED AGAIN (user): NO auto-ranging. Both knobs analog: inverting OPA1652 stages with centre-detent dual 10k
        LINEAR pots (Alps RK09L1240015, Mouser): pg-line -33..0..+33 dB (220R ends), pg-hp -21..0..+21 dB (1k ends);
        centre click = unity. ADS1015 + mic path removed; J20 (pg-line) + J19 (pg-hp) 6-pin headers on the iso side
        under the in / out jacks. Firmware: fixed gains (kInGain/kOutGain), no knob reading. Face: pink centre dot = unity.
        Board: groups have fixed areas (make_board.py GROUPS), barrier at y 29.5, all parts top side.
        DONE 2026-10-08: routed 100 %, DRC clean at JLCPCB limits (5 mil), check_isolation.py OK; jlcpcb/ files made;
        Tayda drill + UV templates uploaded; plugin rebuilt. NEXT: user orders (JLCPCB Standard, Top side) + Mouser pots.
        TODO: finish layout + route + DRC, make_jlc.py / make_bom.py for the new parts, DESIGN.md rewrite, Tayda
        upload (drill + UV), plugin rebuild, export + push, memory.
        - jacks: ONE stereo IN (left) + ONE stereo OUT (right), both isolated, Neutrik NMJ6HFD2 (plastic nose, C368491),
          plus the 9v panel jack. Top wall: in / 9v / out. Face print, drill, 3D model follow.
        - iso side: TLV320AIC3204 (C24109, QFN-32) does mic preamp (0..47.5 dB) / line / hot-amp input (2nd attenuated
          input path + clamps), headphone (16-600 ohm) or line output; own power: B0505S (C512048) -> LDO 3.3 V.
        - barrier: ISO7741 (C571196: BCLK, WCLK, DIN -> codec; DOUT <- codec) + ISO1540 (C179739, I2C).
        - pedal side: 5 V LDO for the B0505S, 3.3 V for the isolators, ADS1015-type I2C ADC reads the 2 pots
          (pg-hp = output level, pg-line = input gain; no audio through the pots).
        - Seed3 pins: SAI2 32 SD B (rx), 33 SD A (tx), 34 FS, 35 SCK; I2C1 12 SCL / 13 SDA; LCD_DC -> 37, LCD_RESET ->
          pin 1 (D0), T_DO -> 36, T_IRQ dropped (touch polled). Seed's own codec (16-19) unused.
        - firmware: SAI2 + codec init over I2C, auto-ranging input + safety (clip -> range switch + mute + warning),
          output level from pg-hp, input gain from pg-line.
        - board: groups in printed boxes + flow arrows (make_board.py GROUPS/FLOW, already written), small text,
          logo on the back corner, all parts on top, inputs left. Then JLCPCB files (make_jlc.py), Standard/Economic top side.
- [~] e. plugin 3D model done (Seed3 right, 5 jacks, small knobs, pink caps); docs + BOM/budget for the carrier board still to do

- [ ] 34. (after hardware test) SPI DMA so rendering overlaps sending: solid 60 on graph pages
- [ ] 27. Try it all on the real Seed3 (bootloader, flash saving, CPU load) and re-upload drill + print to Tayda
- [x] 41. Rounded aurora: pearl edge + outline animations follow the tiles' rounded corners (EdgeInset in PgCore.cpp;
      Outline.rad: tabs 6, param boxes 4, band chips 3, boot/tour square). Page open/close move is now LIQUID
      (Outline.kind 1 + LiquidField SDF: melt + drips, falling drops, gooey neck, springy settle; kWipeMs 800).
      Native frame test: scratchpad liq/t.cpp. Plugin + firmware rebuilt.
- [~] 42. BOARD SIMULATOR in the plugin (user chose FULL TRANSIENT). STATUS 2026-10-09:
      a. DONE: 12-Carrier-Board/board_export.py -> Source/sim/BoardData.h (real copper: islands, tracks, vias).
      b. IN PROGRESS: Source/sim/BoardSim.{h,cpp} (not in CMake yet). Netlist from BoardData + wiring (DefaultWiring =
         WIRING.md incl. pots pin3->header1). Slow solver = smooth models + Newton (numeric central-diff Jacobian,
         line search with uniform step scaling, pseudo-cap per node, chip enables read from step-start voltages Ven).
         Steady state WORKS and is fast (~1 ms per 30 ms tick): +9V 8.22, +5V 5.00, +3V3 3.30, ISO5V 5.05,
         ISO3V3 3.30, IBIAS 1.65, 197 mA, HP_ON 0.5 s unmute. PROBLEM: power-up from 0 V is slow (~15 s compute):
         operatingPoint() (pseudo-transient continuation) oscillates g 2 <-> 0.2. Ideas: gentler g schedule
         (x0.5, fail x3), or start from a hand-built guess (rails at nominal). Native tests: scratchpad simt/
         d2.cpp (timeline), d3.cpp (tick timing), t.cpp (gain + wrong-wiring cases). Debug env vars NDEBUG*.
         Then: fault check for op-amps should use rail proximity of V (not PWL st); fast audio islands untested
         since the slow-solver rewrite; then plugin integration (Seed3Runner hooks runInput/runOutput around
         core.Process, small-knob params, slow thread), board view, wiring editor.
      a. _Tools/board_export.py (pcbnew): 12-Carrier-Board -> 10-Carla-Plugin/Source/BoardData.h (parts, pads, nets,
         track/via geometry, copper islands per net from KiCad connectivity = opens/shorts from the REAL copper).
      b. Source/sim/: MNA engine (dense LU, trapezoidal companions, Newton for diodes / op-amp rails), auto-partitioned:
         power + slow nodes (rails, IBIAS) at ~2 kHz, audio islands (input + output analog per channel) at 48 kHz.
         Models: R, C, diode/TVS/PSM712, PTC (I^2t heating), AMS1117/XC6206 (dropout, current limit), B0505S
         (isolated, own ground), TLV9062 (GBW pole, rails, output R), TPA6139A2 (x-2, charge pump), codec ADC/DAC
         (needs power + I2C config; DAC = DSP output), ISO7741/ISO1540 (pass only if both sides powered), jacks, pots.
      c. Wiring: external jumpers (J10 <-> Seed3 pins, pots <-> J19/J20, DC jack, fx-loop bridges) as an editable map,
         default = WIRING.md; wrong wiring -> the sim shows it (no sound, wrong level, smoke).
      d. Board view (2D, in the plugin window): real copper, current-flow dots on traces, part heat, fault list.
      e. Audio: plugin audio goes jack -> simulated input stage -> codec ADC -> core DSP -> DAC -> simulated output.
- [x] 43. UI (finding things + navigation): home footer = what the focused tab is for (ui::kTabWhat); pg-b = "next": settings page 2 first, then the next tab; title shows 1/2 / 2/2.
- [x] 44. BUG FOUND (while modelling the pots): pot pin 3 = clockwise end, so "1 l" on header pin 1 made the knobs work
      BACKWARDS (right = less). Silk relabelled on the routed board (3 l, 2 l, 1 l, 3 r, 2 r, 1 r; make_board HEADER_PINS
      too), gerbers / renders / JLC files regenerated (no copper change), docs updated. User must re-upload the gerbers zip.
- [x] 45. Press-fit ("locking") header holes on J10 J19 J20 J21 J22: each other HOLE offset 0.127 mm (pad copper kept in
      place via pad offset, DRC clean), so header strips jam in without solder (+ hot glue). Gerbers regenerated.
      Backup of the unstaggered board: 12-Carrier-Board/build/pg1-carrier.before-lock.kicad_pcb.
- [x] 46. 2026-10-09 (buy day): silk labels with part names + U3 "PIN 1" (regen_outputs.py, no re-route); headers
      to be SOLDERED (press-fit holes still solder fine). AC analysis added to BoardSim (acResponse): found the
      C31/C41 3.2 kHz low-pass -> DNP (make_jlc / make_bom / BoardSim kNotFitted). Firmware kInGain 0.118 -> 0.0895
      (codec's 20k input loads the divider). Plugin face texture was stale (export only rebuilt the copy) ->
      pg_generate.py now writes 10-Carla-Plugin/assets/face-print.png; plugin rebuilt. Wrong-wiring battery:
      scratchpad simt/ww.cpp; bench: simt/ac.cpp.
- [x] 47. 2026-10-09: UI back to square edges, aurora 3 px in the strong middle of the pearl palette, liquid page move
      reverted (straight slide, kWipeMs 420, settings slide 150 ms). BUILD-GUIDE.md written (current wiring; WIRING.md
      had stale bits: Seed3 window is RIGHT wall, key with pin 16 not pin 1, no audio ground chain, no exp jack).
- [x] 48. 2026-10-09 face redesign: gain pots under the jacks (x +-48, y 52; "Input Gain dB / any level, not too hot",
      "Output Gain dB / phones or line in"), PAGE SELECTOR (A-8626 1P8T + pink A-6623 chicken head at (8, 50), print 1..8 +
      "page"): it picks the SETTINGS PAGE of whatever tab is open (closest page it has), NOT the tab (user's correction).
      Core: Core::PageSelector(pos) / OpenPage(); firmware: PCF8574 on the Seed I2C (expansion header J21), position k ->
      P(k-1), common -> GND. Logo + name sideways left of the screen, all diamonds pink. Plugin: draggable gain knobs and
      chicken head (click / drag / wheel). Tayda drill + UV re-uploaded (17 holes).
- [x] 49. Analog leveller ON THE CARRIER BOARD (user: "why a breadboard?", 2026-10-09): codec LO -> 4.7k (R80/R85) ->
      LDR || 100k (R81/R86) -> 10 uF (C80/C85) to IGND; TLV9062 WSON-8 2x2 (U16, under the DC jack) followers -> FXR;
      OC1/OC2 = home-made vactrols (3 mm flat-top LED A-8041 + LDR A-7629 in black heat shrink) on the LID side, pins
      under the DC jack (clip flush); LEDs in series from ISO5V_RAW, NPN Q1 + 100R, MCP4725 U15 (iso I2C 0x60).
      J22 stays OPEN now (sim flags bridges). Added to the routed board by add_leveller.py (+ place_extra.py,
      route_one.py), old tracks untouched; DRC clean (3 accepted courtyard overlaps). Sim: dark 0.04 dB loss,
      1.3 mA -12 dB, 7.8 mA -21 dB, DC at the jack < 5 mV. Firmware: pg::AnalogLeveller, V = 0.65 + 0.1 x mA, dark 10 s.
      JLC: +2 extended parts (C144198, C2058009) ~ +$6 fees + ~$5 parts. Tayda cart 21 lines (breadboard parts dropped).
- [ ] 50. Board simulator in the plugin (board view + wiring editor), fast power-up: see 42.
- [x] 51. 2026-10-09 evening: power switch = A-8233 (RS16 2P4T) + 2nd pink chicken head at face (-47, 2), "0 / 1",
      in the dc + wire (pos 1 off, 2-4 on); logo/name shrunk into y 17-33; Tayda re-uploaded (18 holes), cart 22 lines.
      Header holes re-centred (no press-fit offset), "pg-line"/"pg-hp" silk -> "in gain knob"/"out gain knob".
      Scenario sims (scratchpad simt/scen*.cpp) found 3 things, all value-only fixes + one new part:
      R33/R43 1M->470k (input clean to 3.4 V rms), R34/R44 20k->4.7k (ADC range used; kInGain 0.1883),
      D63 1N4148WS + R70 1M (quick off/on thump 1.1 V -> 2 mV). Sim: Newton stall tolerance 1e-8 -> 1e-11 (1e-8 let a
      0.25 V false DC through at 250 ohm; 1e-14 too slow). Tried R6 3.3k (bias 2.48 V): solver can't settle it -> kept 10k.
      make_jlc now checks every footprint against the routed board. Plugin: power knob (click = off: silence, dark).
- [x] 52. 2026-10-09 night: hard limits. Bias centred (R6 3.3k; the sim's start-up search now scales its pretend
      capacitors per node, which is what made this solvable), R34/R44 12k = the input clamp (codec pin +0.02..+1.98 V
      for any input; analog clips at -4 dBFS), R31/R41 DNP (1.46 Mohm for guitars), output ceiling 3.0 V peak (TPA rails),
      firmware IsoCodec::Guard (codec gains re-checked every second, PGA <= 20 dB), kInGain 0.1152.
      Face: measured the RS16 (45 deg clicks, 16 mm body) and the chicken heads: pink 32 mm can't work on a 4-click
      switch (sweeps over the screen) -> both switches A-8233 with black A-6741 (23.4 x 16.5) at (-16, 51.5) power and
      (16.4, 51.5) page 1..4; check_knob_sweeps proves 5.4 mm clearance over the whole travel. 9 V jack -> LEFT wall
      (side C, y -34) at the user's request. Tayda re-uploaded; cart 21 lines.
- [x] 53. Input clamp settled: ngspice (scratchpad spice/chain.cir: the isolated path, behavioural op-amps with rails)
      showed a long one-sided hit swings the codec pin past its window with R34 12k (-0.42 / +2.26 V: the 1 uF in front
      of the pin remembers the hit). Schottky clamps at the pins (BAS40W-04) didn't fit even with a local re-route.
      -> R34 / R44 20k: worst over 5-150 ms +-12/+-24 V hits, released or reversed, 5 V up to 5.3 V: -0.02 .. +1.85 V.
      kInGain 0.0807. The board simulator mis-solves sustained +-12 V DC at the input (output side goes to nonsense);
      ngspice shows the real output untouched (< 20 mV) - a known limit of our simulator, not the board.
- [x] 54. 2026-10-10: no Mouser. JLCPCB fits only U3 (B0505S, ~$8 with fees for the 2 boards = JLC's minimum PCBA qty,
      one design); the 2 Neutrik jacks from Amazon (B00FV23QH6), soldered by the user; gain pots Tayda A-8618.
      PINK chicken heads back (A-6623, 32 x 19.5): power (-14, 56) "0" at 205 deg, page (14, 54) pages 1-4 from 125 deg;
      1.8 mm apart at the closest along their whole travel, every label on the face, pointers up to 6 mm past the top
      edge (above the face; the jack plugs are below it). Tayda re-uploaded; cart 22 lines $56.69.
- [x] 55. 2026-10-10: knobs level (both y 56, x +-14; power "0" 205 deg, page 1 at 115 deg, 4.0 mm clear), thin arcs
      along each dial's travel on the print, labels kept under the border. LDR A-5800 out of stock -> A-7629 (LXD5528A,
      560 nm). XYG PCF8574 board out of stock -> any PCF8574 board (NOYITO / DEVMO / Comimark). Tayda re-uploaded.
- [x] 56. 2026-10-10: border pushed out (ART - 2 mm) so the gain dot rings clear it; check_corner_posts() audits every
      body behind the face against the 4 lid-screw posts (tightest: gain pots 0.8 mm, pins pointing down). Leveller light
      pairs made OPTIONAL (out of the cart: A-7629 / A-8041 / A-4918; pads stay). Comimark PCF8574 3-pack OK. Cart 19 lines.
- [x] 57. 2026-10-10: leveller light pairs back in the cart. Level lights: one 2-leg red/green LED (A-1076) per side in a
      chrome bezel (A-661, 5.7 mm hole, nut) at (+-48, 37) under the gain knobs (only spot with room: the right one is
      1.7 mm from the Seed3 block), driven by PCF8574 P4/P5, P6/P7 with 330R pull-ups. Firmware: P_LEV_ON / P_LIGHTS on
      the input tab's page 2 + GraphLeveller live view; plugin simulates both and lights its 3D LEDs. Full point-to-point
      wiring drawing (_Tools/pg_wiring.py -> wiring-diagram.svg/png/pdf + WIRE-LIST.md, 92 wires). Fixed: ground chain
      and J10 gnd both claimed socket 40 (chain now spliced onto that jumper); guide said JLC fits the jacks (it doesn't).
- [x] 58. 2026-10-10: Minecraft-style pixel gems (deep metallic sea blue CMYK, white glints left unprinted) replace
      every diamond; divider line full width both sides. UV PDF now has 2 layers: CMYK + RDG_GLOSS (copy of everything,
      Separation /RDG_GLOSS) -> Tayda template saved with gloss Varnish, no white. Docs dated / de-staled (8-way,
      exp jack, free pins). 3D wiring (_Tools/pg_wiring3d.py -> wiring-3d.pdf, 7 pages); flat drawing names the far end
      in words. Headphones: 2.1 V rms ceiling -> 600 ohm gets 7.5 mW.
- [x] 59. 2026-10-10: headphone power cap: R50/R60 1 -> 47 ohm (C23182, value only, JLC BOM regenerated, BoardData.h
      re-exported): any load gets <= 24 mW (48 mW clipped) with both knobs full up; 600 ohm still 1.97 V rms. Power dial:
      "0", then a pink ON arc over clicks 2-4 ("1" on 2 and 3; all three wired on). Wiring pictures
      (_Tools/pg_wiring_pics.py -> wiring-pictures.pdf, 10 pages: each part drawn as seen when soldering, RS16 lug layout
      from its datasheet, every wire to its exact lug, steps in words) replace the 3D pages.
- [x] 60. 2026-10-10: wiring pictures redone (user: still horrible): shaded parts (metal cans, ivory switch with moulded
      numbers, PCB headers with spacer bars, dupont ends), wires routed in lanes with rounded corners and never over
      parts, bare links on the power switch bent round the rim outside lugs 1 / 5. No order placed yet (47R is in the
      JLC files they'll upload).

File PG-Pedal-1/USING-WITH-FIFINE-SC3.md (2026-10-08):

# Using PG-1 with a Fifine SC3

```
SC3 LINE OUT (3.5 mm) ──[ground loop isolator]──[3.5 mm → 1/4" TRS stereo cable]──► pedal IN
pedal OUT ──[1/4" → 3.5 mm adapter]──► your headset
```

## Input: use the SC3's LINE OUT
- LINE OUT is a fixed, clean stereo level, the best match for the pedal. Auto-leveling handles the rest.
- The SC3 headphone/headset output also works. Set the SC3 volume to about half, because a full-volume headphone output can clip the Seed3 input (max about 1 V RMS).
- Cable: **3.5 mm male → 1/4" (6.35 mm) male, TRS stereo**. A mono (TS) cable loses the right channel.

## Output: straight to the headset
- **The Seed3 has no headphone amp.** Its outputs are line level (0 dBFS = 1 V rms); Electro-Smith's datasheet adds a headphone amp
  chip (TPA6110A2, its "Figure 3.9") for headphones. A sensitive gaming headset may still get loud enough straight from the line out,
  so treat it as "test it". If it's too quiet or thin, the fix is that amp chip (it's what the planned carrier board would add).
- **The pedal has no volume knob of its own.** The safety tab caps the level (peak *ceiling*, long-term *ears*), and the input auto-level keeps it steady,
  but how loud that is in your ears depends on the headset. Hold the headset near your ears (not on) the first time.
- **The auto-level undoes the SC3 volume knob** (it brings any level back to its target). So set loudness with the **input** tab's
  **target** (pg-1, -30 to -10 dB). Or switch the input tab off (hold pg-b on it) and use the SC3 volume as usual.
- **Headset with a mic on one plug (4-contact TRRS)**: a plain 1/4" TRS adapter can leave the headphone ground unconnected, which sounds thin, hollow or one-sided.
  Use the headset's separate headphone plug if it has one, or a TRRS splitter (headphone + mic) and plug in the headphone branch.
- If it's too quiet or distorts: tell me. The fix is either a tiny headphone amp (one chip, like Electro-Smith's design)
  or sending the pedal OUT into the SC3's **LINE IN** so you keep listening on the SC3.
  If you try LINE IN, start with the SC3 volume low: if the SC3 also sends LINE IN back out of LINE OUT, it will loop and howl.

## Protecting the SC3 and the PC
A **3.5 mm ground loop isolator** (~$10) between the SC3 and the pedal IN. It's two small audio transformers in a plug:
sound passes through as a magnetic field, and **no wire connects the two sides**. No DC voltage, no 9V, no ground current can
reach the SC3 (and the PC behind it) from the pedal, whatever happens inside the pedal. It also stops ground-loop hum.

Before the first connection, with a multimeter (DC volts) and the pedal powered:
1. **IN jack:** tip to sleeve, ring to sleeve. Write down what you read (expect about 0 V, maybe up to ~1.5 V if the Seed3 input is DC-biased).
   With the isolator in place this can't reach the SC3 either way. **Anything near 9 V = a wiring mistake: stop.**
2. **OUT jack:** tip to sleeve, ring to sleeve: should be about 0 V (below 0.05 V) before a headset goes on.
3. **9V jack:** sleeve lug to the enclosure (bare metal, e.g. a scraped screw hole): must NOT beep / must read open.

Also:
- Use only a **9 V, center-negative, regulated** pedal adapter (a Boss PSA-style one). Not 12 V, not 18 V, not an unregulated wall wart.
- When the pedal's USB-C is plugged into the PC (flashing), unplug the audio cable from the SC3. Two ground paths to the same PC
  only cause hum, not damage, but there's no reason to have both.

## Before plugging in the headset the first time
With the pedal powered, measure DC volts between the OUT jack's tip and sleeve. It should be about 0 V. If it isn't, don't plug the headset in; tell me.

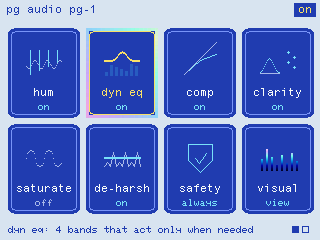
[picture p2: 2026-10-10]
PG-Pedal-1/04-Top-Artwork/screen-home.png

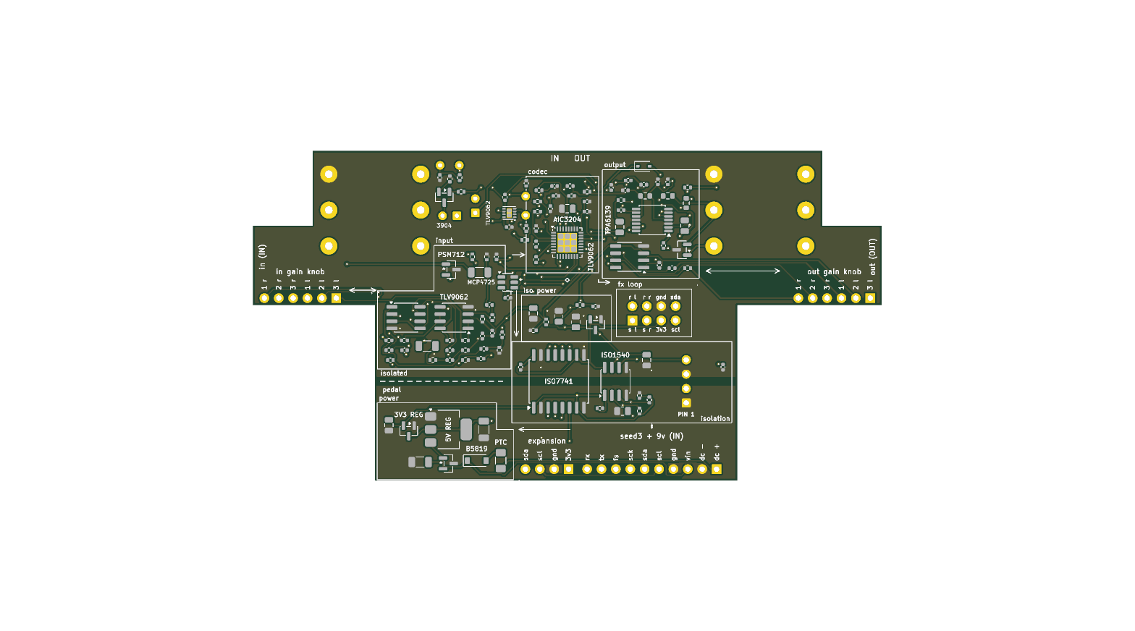
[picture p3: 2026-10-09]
PG-Pedal-1/12-Carrier-Board/jlcpcb/pg1-carrier-top.png

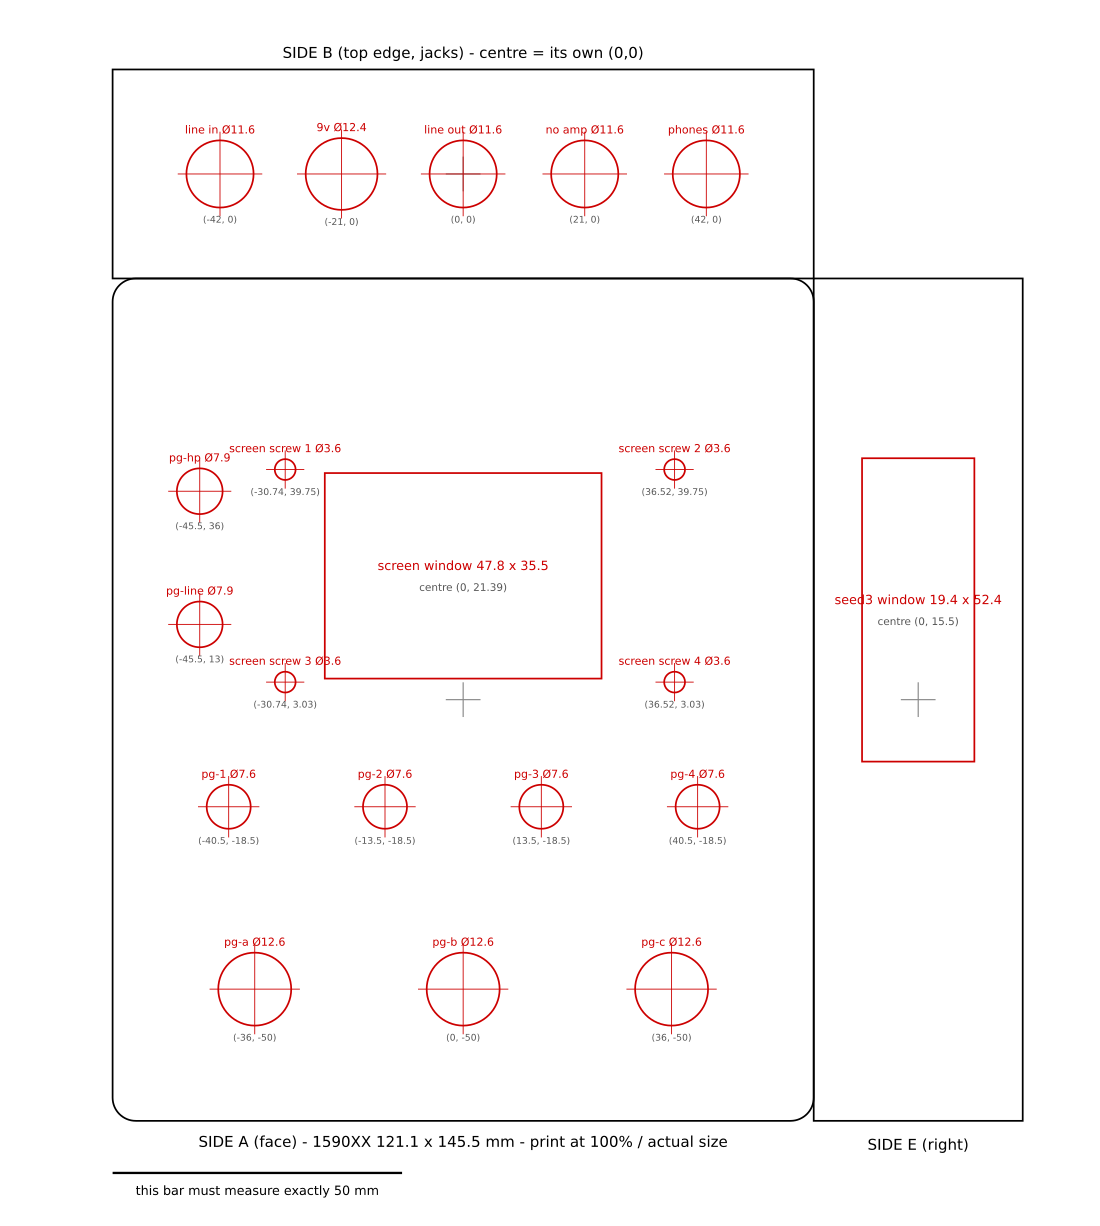
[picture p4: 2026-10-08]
PG-Pedal-1/03-Drill-Template/pg1-drill-template-1to1.png

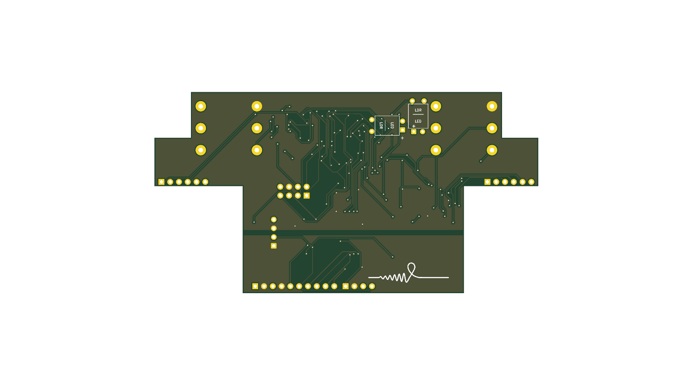
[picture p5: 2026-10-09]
PG-Pedal-1/12-Carrier-Board/pcbway/pg1-carrier-bottom.png

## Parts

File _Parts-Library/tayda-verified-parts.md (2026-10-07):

# Tayda parts checked for Daisy pedals (2026-10-06)

| SKU | Part | Hole (+0.4 powder coat) |
|---|---|---|
| A-5883 | 1590XX white enclosure | — |
| A-6331 | Alpha RE111F encoder 20 detents + push, D shaft, M7 | 7.6 |
| A-1091 | Soft-touch momentary footswitch SPST-NO PBS24B4, M12 (2300+ stock) | 12.6 |
| A-8663 | Same switch, long PCB lugs (low stock) | 12.6 |
| A-1121 | 6.35mm TRS enclosed jack, 3/8"-32 | 9.9 |
| A-2237 | 2.1mm DC jack, enclosed | 12.4 |
| A-1920 | Alpha 100KA dual pot, solder lugs, M7 | 7.9 |
| A-8180 | 2.4" ILI9341 SPI TFT with 4 M3 holes (MSP2402) | M3 → 3.6 |
| A-7402 | 1.8" ST7735 TFT (no mounting holes!) | — |
| A-2850 | Knurled aluminium knob white 20 mm, 6 mm set screw (fits encoders) | — |
| A-8463 / A-4559 | Davies 1900H black knob, D shaft / set screw | — |
| A-8500 / A-8506 | nylon M3 standoff 5 mm / 20 mm | — |
| A-6397 / A-6393 | black M3x20 / M3x8 socket screws | — |

Seed3 socket: 2x A-1310 (20-pin female). Not at Tayda: Daisy Seed3, VHB tape, plastic sheet, a panel-mount USB-C with data (rectangular: SparkFun CAB-15455, 2x M3 @ 18 mm; round: Adafruit #6069), 9V adapters (out of stock).
Tayda's quick-order CSV format is `sku,qty`. Drilling/UV printing is ordered on drill.taydakits.com (holes + rectangles, max 40 each).

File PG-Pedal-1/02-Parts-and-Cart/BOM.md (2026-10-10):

# PG-1 parts

## Tayda cart upload
- **Cart page → Import → Add from file:** `tayda-cart-import.csv` → **Replace current cart**
- (Quick Order page instead: `tayda-cart.csv`)

You should end up with **26 lines**, exact quantities. The Seed3 is a **cartridge**: it plugs into a socket in the left wall (a glued block of jumper ends). The soldered socket board (way 2 in WIRING.md) is a later upgrade: its parts aren't in the cart.

| SKU | Qty | Each | Line | Part | Used for |
|---|---:|---:|---:|---|---|
| A-5883 | 1 | $12.99 | $12.99 | 1590XX Aluminum Diecast Enclosure WHITE | the box (drilled + printed via drill.taydakits.com) |
| A-8180 | 1 | $7.20 | $7.20 | 2.4in SPI touch TFT 240x320 ILI9341 + XPT2046, 4 M3 holes | color touchscreen |
| A-6331 | 4 | $1.59 | $6.36 | Rotary encoder 20 detents + push switch, D shaft (Alpha RE111F) | pg-1, pg-2, pg-3, pg-4 |
| A-2850 | 4 | $1.29 | $5.16 | Knurled aluminium knob, white, 20 mm, 6 mm set screw | 4 knobs (your pick) |
| A-1091 | 3 | $1.97 | $5.91 | Soft-touch momentary footswitch SPST-NO (PBS24B4) | pg-a, pg-b, pg-c (your pick) |
| A-8618 | 2 | $1.49 | $2.98 | 10K linear DUAL pot, 9 mm, 6 mm D shaft, 7.5 mm hole (Alpha RD902F) | pg-line (input gain) and pg-hp (output gain): no centre click, the middle of their turn = unity |
| A-8567 | 2 | $0.69 | $1.38 | White ripple knob 14 mm | the two small knobs |
| A-2599 | 3 | $1.20 | $3.60 | KN2310 pink aluminium footswitch cap 23 mm (for PBS-24) | pink caps on pg-a, pg-b, pg-c |
| A-2237 | 1 | $0.13 | $0.13 | DC power jack 2.1mm enclosed (12mm) | 9V in |
| A-3482 | 2 | $2.30 | $4.60 | Jumper wires female/female 200mm, pack of 40 | 34 for the Seed3 pins (their ends form the glued socket) + screen GND, 12 for the 2 pots to the carrier board, spares |
| A-8500 | 4 | $0.02 | $0.08 | Nylon standoff M3 x 5mm | screen spacers |
| A-6395 | 4 | $0.11 | $0.44 | M3 x 12mm black socket screw | screen screws through the face |
| A-1247 | 4 | $0.02 | $0.08 | M3 nut | screen nuts |
| A-8519 | 3 | $0.11 | $0.33 | AWG22 stranded wire BLACK 1ft | the ground chain between parts |
| A-7409 | 1 | $0.49 | $0.49 | Black cable ties 3x100mm (100pcs) | tidy the wire bundles |
| A-199 | 1 | $0.17 | $0.17 | 40 pin 2.54mm right-angle single-row male pin header | carrier board: snap into 10 + 6 + 6 + 4 (J10, J20, J19, J21) |
| A-198 | 1 | $0.21 | $0.21 | 2x40 pin 2.54mm double-row male pin header strip | carrier board: snap off a 2 x 4 (fx loop J22) |
| A-6623 | 2 | $0.49 | $0.98 | Chicken head knob, PINK, 32 x 19.5 mm, set screw (1.5 mm key) | on the power switch and the page selector |
| A-8233 | 2 | $1.09 | $2.18 | Mini rotary switch 2 pole 4 position RS16 (9 mm hole, 6 mm spline shaft, 16 V 0.3 A, 45 degree clicks) | the power switch (0 = off, 1 = on) and the page selector (pages 1-4) |
| A-7629 | 4 | $0.25 | $1.00 | LDR 10-15k (5 mm, 560 nm, LXD5528A) | analog leveller: the light sensors, OC1 / OC2 on the board's lid side (2 spare) |
| A-8041 | 4 | $0.04 | $0.16 | LED 3 mm red, flat top (3.85 mm head) | analog leveller: one pressed on each LDR (2 spare) |
| A-4918 | 1 | $0.14 | $0.14 | Black heat shrink 6 mm, 20 cm | analog leveller: a 15 mm light-tight sleeve over each LED + LDR pair |
| A-1076 | 3 | $0.04 | $0.12 | Bi-color LED red/green 3 mm, 2 legs (KENTO 3ARG4HWC) | the 2 level lights under the gain knobs (1 spare) |
| A-661 | 2 | $0.08 | $0.16 | 3 mm chrome bezel LED holder with nut (5.7 mm hole) | holds each level light in the face: no glue |
| A-7116 | 2 | $0.03 | $0.06 | Plastic insert for the 3 mm chrome bezel | grips the LED inside the bezel |
| A-2325 | 10 | $0.015 | $0.15 | 330 ohm 1/4 W 1% metal film resistor | level lights: one from 3.3 V to each of the PCF8574's P4-P7 (6 spare) |
| | | | **$57.06** | **Tayda subtotal** | |

The drilled box + UV print are ordered on drill.taydakits.com, not in this cart: drill service $4.50 (up to 40 holes) + face UV print $3.50.

**Budget ($150 total):** see the table at the top of `AMAZON-LIST.md`.

## Breadboard test first (no soldering): `tayda-cart-benchtest.csv`
Add these to the same Tayda order (one shipping fee). With them the Seed3, screen, knobs, footswitches and jacks all run on the desk
before anything is drilled or soldered: see `05-Wiring-and-Schematics/BENCH-TEST.md`.

| SKU | Qty | Each | Line | Part | Used for |
|---|---:|---:|---:|---|---|
| A-2372 | 1 | $2.49 | $2.49 | 830-point solderless breadboard | the Seed3 + encoders plug into it |
| A-3478 | 1 | $0.90 | $0.90 | Jumper wires female/male 200mm, pack of 40 | screen pins → breadboard |
| A-3480 | 1 | $1.11 | $1.11 | Jumper wires male/male 200mm, pack of 40 | breadboard row to row |
| A-5498 | 2 | $1.50 | $3.00 | Alligator clip to male jumper, 10 lines | clip onto jack and footswitch lugs |
| | | | **$7.50** | | |

## Not sold by Tayda

Shopping list with Amazon search words: `AMAZON-LIST.md`.

| Item | ~Price | Notes |
|---|---|---|
| Daisy **Seed3** **with headers** (its male pins already soldered on: they plug into the sockets) | ~$30 | daisy.audio or a dealer. A spare one just plugs in. |
| 9V **center-negative** pedal adapter, ≥300 mA | $10-20 | Boss PSA-style or a pedal power supply |
| 3.5 mm → 1/4" **TRS** stereo cable (male-male) | ~$8 | SC3 line out → pedal IN |
| **3.5 mm ground loop isolator** (audio transformer type) | ~$10 | between the SC3 and pedal IN: no wire connection, so nothing from the pedal can reach the SC3 / PC |
| **Powered** desktop speakers with a 3.5 mm aux input (e.g. Creative Pebble, USB-powered) | ~$25 | cheap, safe first listening test; plain unpowered speakers won't work |
| 1/4" TRS male → 3.5 mm TRS female adapter | ~$5 | pedal OUT → the speakers' aux cable |
| (optional) 1/4" TRS → 2× 1/4" TS "insert" Y-cable | ~$8 | pedal OUT → a mixer's two line inputs (left + right) |
| **Hot glue gun, high-temp, with a narrow nozzle + sticks** (e.g. a dual-temp mini gun) | ~$10-20 | glues the jumper-end socket block into the window (way 1), and a dab on the screen's plugs |

## Tools
Wire strippers, flush cutters, multimeter, a 3 mm drill bit + cheap hand drill or pin vise (4 board holes), wrenches 10-14 mm (or adjustable), 1.5 mm hex key (knobs), 2.5 mm hex key (M3 screws).

## Carrier board: JLCPCB fits these too (no Mouser)
The 2 Neutrik NMJ6HFD2 jacks (J1, J2, C368491) and the B0505S-1WR3 (U3, C512048) are in the JLCPCB files: JLCPCB
solders them on (hand-soldering fee ~$3.50 + their parts ~$16.55 + 2 extended-part fees $6 for 2 boards).
Headers come from Tayda (A-199 + A-198). The fx loop stays open (the leveller drives it).

## Amazon (Prime): small ready-made boards, pins already soldered
| Qty | Part | For |
|---|---|---|
| 1 | **PCF8574 I/O expansion board** (I2C, 3.3 V ok; any brand: VCC / GND / SDA / SCL + P0-P7 pins, e.g. NOYITO B07D57NH9Q, DEVMO B09L4RLHX8, Comimark B07X3KWQZ7) | reads the 4-way page selector, plugs onto the expansion header |

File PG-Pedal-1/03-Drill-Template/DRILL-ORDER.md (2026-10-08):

# Ordering the drilled enclosure (drill.taydakits.com)

**Easiest:** `python3 _Tools/tayda_upload.py --drill-id 12345 --uv-id 23456`
updates your existing templates. By hand, type these in (mm from the **center of each side**, +X right, +Y up).
Diameters **already include Tayda's +0.4 mm powder-coat allowance**.

## Holes (15)
| # | Side | Diameter | X | Y | What |
|---|---|---|---|---|---|
| 1 | A (Face) | 7.6 | -40.5 | -18.5 | pg-1 |
| 2 | A (Face) | 7.6 | -13.5 | -18.5 | pg-2 |
| 3 | A (Face) | 7.6 | 13.5 | -18.5 | pg-3 |
| 4 | A (Face) | 7.6 | 40.5 | -18.5 | pg-4 |
| 5 | A (Face) | 12.6 | -36 | -50 | pg-a |
| 6 | A (Face) | 12.6 | 0 | -50 | pg-b |
| 7 | A (Face) | 12.6 | 36 | -50 | pg-c |
| 8 | A (Face) | 3.6 | -30.74 | 39.75 | screen screw 1 |
| 9 | A (Face) | 3.6 | 36.52 | 39.75 | screen screw 2 |
| 10 | A (Face) | 3.6 | -30.74 | 3.03 | screen screw 3 |
| 11 | A (Face) | 3.6 | 36.52 | 3.03 | screen screw 4 |
| 12 | B (Top) | 9.9 | -40 | 0 | in |
| 13 | B (Top) | 12.4 | -13 | 0 | 9v |
| 14 | B (Top) | 9.9 | 13 | 0 | exp |
| 15 | B (Top) | 9.9 | 40 | 0 | out |

## Shapes (2 rectangles)
| Side | Type | Center X | Center Y | Width | Height | What |
|---|---|---|---|---|---|---|
| A (Face) | Rectangle | 0 | 21.39 | 47.8 | 35.5 | screen window |
| C (Left) | Rectangle | 0 | 15.5 | 19.4 | 52.4 | seed3 window |

**Check the preview:** side B (top) is drawn above the face, and **"in" must sit above the LEFT half**.
Side C (left) is drawn to the left of the face. The tall Seed3 window  sits level with the "usb-c · seed3" label written up the left edge of the face.
It is centred on the wall's middle, so the X direction doesn't matter. Width 19.4 = across the wall, height 52.4 = along it.

Sizes: encoder M7 → 7.2 + 0.4; footswitch M12 → 12.2 + 0.4; TRS jack 3/8" → 9.5 + 0.4; DC jack → 12.0 + 0.4; M3 → 3.2 + 0.4;
screen window = the lit area minus 0.8 mm per side (no black edge); Seed3 window 19 × 52 (+0.4) for the Seed3 cartridge (18 × 51) (the socket is glued in, no screws).

`pg1-drill-template-1to1.pdf`: print at 100% (the bar must measure 50 mm) to sanity-check with real parts.

## How every part mounts (all plain holes, nothing screws into the box)
Every hole Tayda drills is a smooth clearance hole: no part ever gets turned to screw into the box. Each part is pushed
through from inside and held by **its own nut** on the outside (only the nut turns).
| Part | Hole | Held by |
|---|---|---|
| pg-1..pg-4 encoders (A-6331, RE111F-41**B3**: threaded M7 collar) | 7.6 mm | washer + M7 nut on the face |
| pg-hp / pg-line pots (A-6980, threaded M7 collar) | 7.9 mm | washer + nut on the face (both come with the pot) |
| pg-a..pg-c footswitches (A-1091, M12 thread) | 12.6 mm | one nut inside (sets the height), one on the face |
| 4 audio jacks (Neutrik NMJ6HCD2, fitted on the carrier board by JLCPCB) | 11.8 mm | nut + washer outside the top wall: the 4 nuts also hold the board |
| 9V jack (A-2237) | 12.4 mm | its nut outside |
| screen | 4 x 3.6 mm + window | **M3x12 screw from the face -> 5 mm nylon spacer -> screen board -> M3 nut behind it** (the nut holds it; the hole has no thread) |

- **Anti-rotation tab:** the pots (and maybe the encoders) have a small metal tab sticking up beside the collar, meant for a
  tiny second hole. There isn't one: bend the tab flat or snip it off with flush cutters before mounting, so the part sits flat.
  The nut alone holds it fine.
- **Carrier board:** lower it in from the open back (lid off) about 1 cm away from the top wall, then slide it straight toward
  the wall so the 4 jack collars go through their holes, and put the nuts on. Nothing is twisted.
- If the encoders arrive without nuts: they're M7 x 0.75 (same as most pedal pots).

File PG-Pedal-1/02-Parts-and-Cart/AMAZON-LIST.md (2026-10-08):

# PG-1 shopping list for a $150 budget

## The whole budget

| What | Where | ~$ |
|---|---|---:|
| Parts cart (`tayda-cart-import.csv`, 13 lines) | Tayda | 42.82 |
| Drilling ($4.50) + face UV print ($3.50) | drill.taydakits.com | 8.00 |
| Tayda shipping (shown at checkout, depends on speed) | Tayda | ~8 |
| Daisy **Seed3** with headers + shipping | electro-smith.com | ~36 |
| Breadboard test parts (`tayda-cart-benchtest.csv`, same Tayda order) | Tayda | 7.50 |
| 9V pedal power supply | Amazon | ~10 |
| Ground loop isolator | Amazon | ~10 |
| 3.5 mm → 1/4" TRS stereo cable | Amazon | ~8 |
| 1/4" → 3.5 mm stereo adapter | Amazon | ~5 |
| Mini glue gun + sticks | dollar store / Walmart | ~3 |
| v2 extras: small pots, knobs, PCB jacks, pink caps (in the Tayda cart) | Tayda | ~+10 |
| Carrier board, 2 assembled (budget version, `12-Carrier-Board`) | PCBWay | ~55-80 |
| **Total** | | **~$200-230** (v2 with the carrier board; ~$148 without it) |
| *Later: a good soldering iron + multimeter (your pick)* | | *(not in the total)* |

To save more:
- **Skip the flux pen** (not in the total above). The solder already has flux inside its core; the pen only makes it a bit easier.
- **Already have a 9V center-negative pedal supply?** Then skip it (-$10).
- **Shipping:** choose the slowest, cheapest option at Tayda and Electrosmith.

## 1. The brain (not from Amazon)
- [ ] **Daisy Seed3, with headers** (~$30 + shipping): buy from **electro-smith.com** (Electrosmith, the maker).
  On Amazon it's often an old version (Seed rev 4/5/7) or resold. Make sure it says **Seed3** and **with headers**.

## 2. Amazon: type the search words, pick one with good reviews
- [ ] **9V power supply**: search `9V DC pedal power supply center negative` (~$10). Must say **center negative**, 2.1 mm plug, 300 mA or more.
- [ ] **Ground loop isolator** (keeps the pedal electrically apart from the SC3 / PC): search `3.5mm ground loop noise isolator` (~$10).
- [ ] **3.5 mm to 1/4" stereo cable**: search `3.5mm to 1/4 TRS stereo cable male to male` (~$8). Must say **TRS / stereo**.
- [ ] **1/4" to 3.5 mm adapter** (pedal OUT → headset): search `1/4 male to 3.5mm female stereo adapter` (~$5).

## 3. Dollar store / Walmart (cheaper than Amazon for these)
- [ ] **Mini hot glue gun + mini glue sticks** (~$3).
- [ ] Any clear glasses to wear while soldering (your own glasses count).

## 4. Nice to have, if money is left
- [ ] **Flux pen**: search `MG Chemicals 8341 no clean flux pen` (~$10).
- [ ] **Solder** (when you get the iron): search `Kester 44 63/37 rosin core solder 0.8mm` (~$12).
- [ ] Powered speakers for a first test, e.g. Creative Pebble (~$25).

Tools you probably have at home: a small adjustable wrench (jack and footswitch nuts), a hair dryer.
The knob set screws need a 1.5 mm hex key and the M3 screws a 2.5 mm one: check a drawer, or buy a cheap metric hex key set later.

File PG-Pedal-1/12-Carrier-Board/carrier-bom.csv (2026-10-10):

Item # | Designator | Qty | Manufacturer | Mfg Part # | Description / Value | Package/Footprint | Type | Your Instructions / Notes
1 | J10 | 1 | any |  | seed3 + 9v | PinHeader_1x10_P2.54mm_Horizontal | THT | 2.54 mm male header, any brand: please fit and solder
2 | J21 | 1 | any |  | expansion | PinHeader_1x04_P2.54mm_Horizontal | THT | 2.54 mm male header, any brand: please fit and solder
3 | F1 | 1 | Littelfuse | 1206L030/24NR | PTC 300mA | Fuse_1206_3216Metric | SMD
4 | D1 | 1 |  | B5819W | B5819W | D_SOD-123 | SMD
5 | D2,D61,D62 | 3 | ProTek Devices | PSM712-LF-T7 | PSM712 | SOT-23 | SMD
6 | C1,C2 | 2 |  | CL31A226KAHNNNE | ceramic capacitor 22uF 25V X7R 1206, 25 V or more | C_1206_3216Metric | SMD
7 | U1 | 1 | AMS | AMS1117-5.0 | AMS1117-5.0 | SOT-223-3_TabPin2 | SMD
8 | U2,U7 | 2 | Torex | XC6206P332MR-G | XC6206P332MR | SOT-23 | SMD
9 | C3,C14,C50,C60 | 4 |  | CL21A475KAQNNNE | ceramic capacitor 4.7uF X7R 0805, 25 V or more | C_0805_2012Metric | SMD
10 | R3,R4,R9,R10,R80,R85 | 6 | any |  | resistor 4.7k 1% 0402 | R_0402_1005Metric | SMD | any brand with the same value and package
11 | U3 | 1 | Mornsun | B0505S-1WR3 | B0505S-1WR3 | DCDC_SIP4_B0505S | THT | 2.54 mm male header, any brand: please fit and solder
12 | C7,C8,C16,C17,C18 | 5 |  | CL21A106KAYNNNE | ceramic capacitor 10uF 25V X7R 0805, 25 V or more | C_0805_2012Metric | SMD
13 | U4 | 1 | Texas Instruments | ISO7741DWR | ISO7741 | SOIC-16W_7.5x10.3mm_P1.27mm | SMD
14 | C9,C10,C11,C12,C20,C22,C24,C25,C26,C27,C28,C30,C40,C83,C82 | 15 | any |  | ceramic capacitor 100nF X7R 0402, 25 V or more | C_0402_1005Metric | SMD | any brand with the same value and package
15 | U5 | 1 | Texas Instruments | ISO1540DR | ISO1540 | SOIC-8_3.9x4.9mm_P1.27mm | SMD
16 | C15,C19,C21,C23,C32,C42,C51,C61,C70,C71,C72,C73 | 12 | any |  | ceramic capacitor 1uF X7R 0402, 25 V or more | C_0402_1005Metric | SMD | any brand with the same value and package
17 | R5 | 1 | any |  | resistor 10 1% 0402 | R_0402_1005Metric | SMD | any brand with the same value and package
18 | R6 | 1 | any |  | resistor 3.3k 1% 0402 | R_0402_1005Metric | SMD | any brand with the same value and package
19 | R7,R8,R35,R45 | 4 | any |  | resistor 10k 1% 0402 | R_0402_1005Metric | SMD | any brand with the same value and package
20 | U9 | 1 | Texas Instruments | TLV320AIC3204IRHBR | TLV320AIC3204 | Texas_RHB0032E_VQFN-32-1EP_5x5mm_P0.5mm_EP3.45x3.45mm | SMD
21 | R11,R12,R13,R14 | 4 | any |  | resistor 33 1% 0402 | R_0402_1005Metric | SMD | any brand with the same value and package
22 | U8,U11,U12 | 3 | Texas Instruments | TLV9062IDR | TLV9062 | SOIC-8_3.9x4.9mm_P1.27mm | SMD
23 | J20 | 1 | any |  | pg-line | PinHeader_1x06_P2.54mm_Horizontal | THT | 2.54 mm male header, any brand: please fit and solder
24 | R30,R40 | 2 | any |  | resistor 1k 1% 1206 | R_1206_3216Metric | SMD | any brand with the same value and package
25 | R32,R42 | 2 | any |  | resistor 1M 1% 0402 | R_0402_1005Metric | SMD | any brand with the same value and package
26 | R33,R43 | 2 | any |  | resistor 470k 1% 0402 | R_0402_1005Metric | SMD | any brand with the same value and package
27 | R34,R44 | 2 | any |  | resistor 20k 1% 0402 | R_0402_1005Metric | SMD | any brand with the same value and package
28 | R36,R37,R46,R47 | 4 | any |  | resistor 220 1% 0402 | R_0402_1005Metric | SMD | any brand with the same value and package
29 | C33,C43,C52,C62 | 4 | any |  | ceramic capacitor 100pF C0G 0402, 25 V or more | C_0402_1005Metric | SMD | any brand with the same value and package
30 | R51,R52,R61,R62,R82 | 5 | any |  | resistor 1k 1% 0402 | R_0402_1005Metric | SMD | any brand with the same value and package
31 | R50,R60 | 2 | any |  | resistor 1 1% 0603 | R_0603_1608Metric | SMD | any brand with the same value and package
32 | J22 | 1 | any |  | fx loop | PinHeader_2x04_P2.54mm_Vertical | THT | 2.54 mm male header, any brand: please fit and solder
33 | C80,C85 | 2 |  | CL05A106MQ5NUNC | ceramic capacitor 10uF X7R 0402, 25 V or more | C_0402_1005Metric | SMD
34 | R81,R86 | 2 | any |  | resistor 100k 1% 0402 | R_0402_1005Metric | SMD | any brand with the same value and package
35 | OC1,OC2 | 2 | any |  | LED+LDR | OPTO_PAIR_LED3_LDR5 | SMD | any brand with the same value and package
36 | U16 | 1 |  | TLV9062IDSGR | TLV9062 | Texas_DSG0008A_WSON-8-1EP_2x2mm_P0.5mm_EP0.9x1.6mm | SMD
37 | U15 | 1 |  | MCP4725A0T-E/CH | MCP4725 | SOT-23-6 | SMD
38 | Q1 | 1 |  | MMBT3904 | MMBT3904 | SOT-23 | SMD
39 | R83 | 1 | any |  | resistor 100 1% 0402 | R_0402_1005Metric | SMD | any brand with the same value and package
40 | J19 | 1 | any |  | pg-hp | PinHeader_1x06_P2.54mm_Horizontal | THT | 2.54 mm male header, any brand: please fit and solder
41 | U10 | 1 | Texas Instruments | TPA6139A2PWR | TPA6139A2 | TSSOP-14_4.4x5mm_P0.65mm | SMD
42 | R70 | 1 | any |  | resistor 1M 1% 0603 | R_0603_1608Metric | SMD | any brand with the same value and package
43 | D63 | 1 |  | 1N4148WS | 1N4148WS | D_SOD-323 | SMD
44 | J1,J2 | 2 | Neutrik | NMJ6HFD2 | 6.35 mm stereo PCB jack | Jack_6.35mm_Neutrik_NMJ6HFD2_Horizontal | THT | please fit and solder

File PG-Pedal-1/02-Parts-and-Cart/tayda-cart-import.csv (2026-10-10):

sku | qty | buy_request_dont_change_this_column_values
A-5883 | 1
A-8180 | 1
A-6331 | 4
A-2850 | 4
A-1091 | 3
A-8567 | 2
A-2599 | 3
A-2237 | 1
A-3482 | 2
A-8500 | 4
A-6395 | 4
A-1247 | 4
A-8519 | 3
A-7409 | 1
A-199 | 1
A-198 | 1
A-8233 | 2
A-6623 | 2
A-8618 | 2
A-7629 | 4
A-8041 | 4
A-4918 | 1
A-1076 | 3
A-661 | 2
A-7116 | 2
A-2325 | 10

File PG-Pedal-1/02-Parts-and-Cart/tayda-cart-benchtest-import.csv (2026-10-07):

sku | qty | buy_request_dont_change_this_column_values
A-2372 | 1
A-3478 | 1
A-3480 | 1
A-5498 | 2

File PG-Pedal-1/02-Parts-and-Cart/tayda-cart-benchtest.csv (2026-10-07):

sku | qty
A-2372 | 1
A-3478 | 1
A-3480 | 1
A-5498 | 2

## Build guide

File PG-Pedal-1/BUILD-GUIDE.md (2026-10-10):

# PG-1 build guide (2026-10-10, carrier board v3)

This is the one to follow. It replaces the jack / 9 V / pot / "free pins" parts of `05-Wiring-and-Schematics/WIRING.md`,
which were written before the carrier board existed. Pin numbers here come straight from the firmware
(`06-Firmware-DaisySeed/pg1/src/main.cpp`) and the routed board, and the board itself was checked in simulation.

---

## 0. What to order (today)

| Where | What |
|---|---|
| **JLCPCB** | the carrier board: upload `12-Carrier-Board/jlcpcb/` (gerbers zip, BOM csv, CPL csv). PCB qty 5, PCBA qty 2, Economic, Top side, Confirm Parts Placement yes. JLCPCB also solders on the **B0505S** (no Mouser). The 2 jacks come from Amazon and **you** solder them (section 2). In their placement preview check pin 1 of U3 (B0505S), U15, U16, Q1 and the band of D63. |
| **Tayda** (`02-Parts-and-Cart/tayda-cart-import.csv`, 26 lines) | box, screen, encoders, knobs, footswitches + pink caps, 9 V jack, the **2 gain pots (A-8618)**, 2 packs female/female jumpers, screen screws / spacers / nuts, black wire, cable ties, the 2 header strips, the 2 rotary switches (power, page) + 2 pink chicken heads, the leveller's LEDs + light sensors + heat shrink, the 2 level lights + chrome bezels + 330 ohm resistors |
| **drill.taydakits.com** | the drill + UV print job (templates already uploaded). On the UV template tick **CMYK** and **RDG Gloss** (finish: **Varnish**), leave **RDG White** unticked |
| **Amazon** | a PCF8574 I/O board (page selector + level lights): Comimark 3-pack B07X3KWQZ7 (or any with VCC / GND / SDA / SCL + P0-P7 pins); the 2 Neutrik NMJ6HFD2 jacks (B00FV23QH6) |
| **Seed3** | Daisy Seed3 **with headers** |
| **Tools** | soldering iron kit, **0.8 mm rosin-core solder** (right size for all of this), flush **wire cutters**, wire strippers, multimeter, hot glue gun, a little heat-shrink |

## 1. When the parts arrive: check

- **Carrier board**: every small part is already on it. Two pads in the input box are **empty on purpose** (C31, C41:
  leaving them off keeps the treble). The chips have their names printed next to them.
- Count: 2 pots, 2 header strips, 2 Neutrik jacks, the carrier boards with the B0505S already on, 4 encoders + knobs, 3 footswitches + caps, screen, 9 V jack.

## 2. Solder the carrier board (big through-hole pins only)

Work on the **printed side up** (the side with the labels): every part goes in from that side and is soldered on the back.
Iron on the pad + pin together 2 s, feed solder, a small shiny cone. Snip the leftover leg with the flush cutters.

1. **Headers** (lowest first, so the board lies flat):
   - snap the right-angle strip (A-199) into **10 + 6 + 6 + 4** pins, snap a **2 x 4** off the double strip (A-198).
   - 10 = **seed3 + 9v**, 6 = **pg-line**, 6 = **pg-hp**, 4 = **expansion**, 2 x 4 straight = **fx loop**.
   - the right-angle pins point **off the board edge** (the printed pin names sit beside them). The holes grip the pins,
     so they stay straight while you solder: one end pin first, check it sits flat, then the rest.
2. The **B0505S** comes already soldered by JLCPCB. Check its pin-1 mark (a dot or "1" on its case) sits at the
   square pad marked "PIN 1"; if not, stop and tell me (backwards it feeds power into its output).
3. The **2 Neutrik jacks** (Amazon): from the printed side into **J1 (in)** and **J2 (out)**, noses pointing off the top
   edge. They only fit one way. Press them flat, solder every pin, and fill the big mounting tabs well: the jacks are
   what hold the board up in the box.

Check with the multimeter (beep mode): no beep between the header's **3v3** and **gnd** pins, and none between
**vin** and **gnd** on the seed3 + 9v header.

## 3. The box

The box comes drilled and printed from Tayda. Fit in this order (more elbow room):
1. Screen: `M3 x 12 screw -> face -> 5 mm spacer -> screen -> M3 nut` (x 4), its 14-pin header end to the right.
2. Encoders (snap off their little anti-rotation tab), footswitches, the 9 V jack, the 2 pots (snap off their tab too).
3. The carrier board hangs from its 2 jacks: push the jack noses through the top wall's in / out holes and screw the
   Neutrik nuts on from outside. Nothing else holds it.

## 4. Wires: carrier board -> Seed3 (the seed3 + 9v header, 10 female/female jumpers)

The Seed3 socket is the jumper-end block in the **RIGHT wall** window (section 7). Each header pin is printed on the board.

| header pin | goes to |
|---|---|
| dc + | the 9 V jack's **sleeve** lug (+) (centre-negative jack: find the lugs with the multimeter, adapter plugged in) |
| dc - | the 9 V jack's **centre pin** lug (-) |
| vin | Seed3 pin **39** |
| gnd | Seed3 pin **40** |
| scl | Seed3 pin **12** |
| sda | Seed3 pin **13** |
| sck | Seed3 pin **35** |
| fs | Seed3 pin **34** |
| tx | Seed3 pin **33** |
| rx | Seed3 pin **32** |

(The two 9 V wires are soldered on the jack's lugs and end in a female jumper on the header.)

## 5. The two gain pots (pg-line = Input Gain, pg-hp = Output Gain)

They sit **under the jacks** now: Input Gain under "in" (top left), Output Gain under "out" (top right). Right behind
them is the carrier board, only ~9 mm away, so **solder short wires to the pot pins** (not jumper plugs) and bend
them flat; each wire ends in a female jumper that goes on the header right next to it.

Each pot (Tayda **A-8618**, Alpha dual 10k linear: no centre click, the middle of its turn is unity) is a **dual**
pot: 2 rows of 3 pins (front gang + back gang). The header pins are printed with the **pot pin
that goes there**: `3 l, 2 l, 1 l, 3 r, 2 r, 1 r` ("l" = the front gang, "r" = the back gang).

Find the pot's pins 1 and 3 with the multimeter (ohms), knob turned fully LEFT:
- the middle pin of each row is **2** (the wiper).
- of the two outer pins, the one with **~0 ohm to the middle pin** (when turned fully left) is **pin 1**; the other is **pin 3**.
  (Turn it right: pin 1 to middle goes up to ~10k. That's the check.)

- Mount each gain pot with its **pins pointing down** (toward the screen): that way they clear the box's corner screw posts (0.8 mm).
- **Input Gain** pot (under "in") -> the **pg-line** header (also under "in").
- **Output Gain** pot (under "out") -> the **pg-hp** header (also under "out").

## 6. The fx loop and the expansion port

- **fx loop** (2 x 4): **leave it empty, no jumpers.** The analog leveller on the board (6c) drives the returns now;
  a bridge from s to r would short its output to the codec's. (The sound works with nothing on it.)
- **expansion** (4 pins: 3v3, gnd, scl, sda): 4 jumpers to the **expansion bay** slot in the LEFT wall. Push their
  female ends into the slot from inside until flush, hot glue them on the inside (warm the wall with a hair dryer
  first). Note which colour is which pin. Modules plug onto them from outside later.

## 6b. The page selector (pink chicken head, top right of the two, 4 clicks)

Whatever tab is open, the selector picks its **settings page**: position 1 = page 1, 2 = page 2... A tab with fewer
pages just shows its last one. Without the selector fitted, swiping / pg-b still change pages.

- **Switch (A-8233)**: 2 poles x 4 positions (45 degree clicks). Only pole A is used. Find pole A's **common** with the
  multimeter (beep mode): turn it fully **left** (position 1), the common beeps to exactly one outer lug: that's lug 1;
  one click right, lug 2 beeps; then 3, 4. (Pole B: leave it empty.)
- **PCF8574 board** (Amazon, pins on): solder 5 wires to the switch: lug 1 -> **P0**, lug 2 -> **P1**, lug 3 -> **P2**,
  lug 4 -> **P3** (female jumper ends on the PCF8574 side), common -> **GND**: the GND pin already has the carrier's
  jumper on it, so solder the common's wire on the board's **underside**, on the GND pin's joint. Bend them flat.
- PCF8574 input header -> the carrier's **expansion** header: VCC -> 3v3, GND -> gnd, SDA -> sda, SCL -> scl.
  (If it has a second, pass-through header, run the 4 wires to the left-wall expansion bay from there.)
- Velcro the PCF8574 to the inside of the lid. The firmware finds it by itself (any address).
- **Mounting** (both switches the same): snap off the little locating tab on the switch's front with pliers, through
  the 9 mm hole, turn the body so position 1 lines up with the "1" dot, tighten the nut (2 mm nut + washer: up to 4 mm
  of panel). Turn it fully left, put the **pink chicken head** (A-6623) on pointing at "1" and tighten its set screw
  (1.5 mm hex key) onto the shaft.

## 6b2. The power switch (pink chicken head, top left of the two: 0 = off, 1 = on)

The same switch (A-8233) in the **+ wire** from the 9 V jack: position 1 = off ("0"), any other position = on ("1": the
other two clicks are on too). Off, the pedal draws nothing. The Seed3 runs from the 9 V through the carrier board's
vin wire, no USB needed; USB-C is only for flashing, and plugging it in while on is fine.

- **The 9 V jack is in the LEFT side wall, low** (between the pg-1 knob and the pg-a footswitch, inside: 3 mm clear of
  both). Plug faces left.
- **Find the lugs** (beep mode): 2 **commons** (one per pole) and 8 outer lugs. Turn it fully **left** (position 1):
  the outer lug that beeps to each common is that pole's position 1: **leave both position-1 lugs empty**.
- **Wiring** (black wire from the cart, solder; ~15 cm from the jack up to the switch):
  - the 9 V jack's **+ lug** (the sleeve lug: the jack is centre-negative) -> both commons, joined;
  - all six other outer lugs (positions 2, 3, 4 of both poles) joined with bare offcuts -> a wire to the carrier
    board's **dc +** pin;
  - the jack's **centre (-) lug** -> **dc -**, straight.
- Mount it like the page selector, with position 1 at the "0" dot and the chicken head pointing at "0".
- Check before closing the box: at 0 -> no beep between the jack's + lug and dc +; at 1 -> beep.

## 6c. The analog leveller (its 2 light pairs)

What it does: the DSP measures what's leaving and, above about -14 dBFS, lights two small LEDs a little (2:1); each
LED shines on a light sensor (LDR) that gently pulls its channel's level down **in the analog path**, before pg-hp:
the classic smooth "opto" leveller. LEDs dark = the sound passes untouched (that's also how it powers up).

JLCPCB fits everything except the two **light pairs**, OC1 (left channel) and OC2 (right), which you make:
each is one **3 mm flat-top red LED** (A-8041) + one **LDR** (A-7629) + **15 mm of the black 6 mm heat shrink**.

They sit on the **back** of the board (the lid side, plain except for their two printed outlines "LED / LDR"), next to
the "in" jack. Each outline has 4 holes: 2 at the LED end (the square one marked **+**), 2 at the LDR end.

1. **LED**: the **long leg is +** (also: the flat spot on its rim is -). Bend both legs 90 degrees, 1 mm from the
   body, so the LED lies flat along the outline with its flat top toward the LDR end. Long leg into the **+** (square)
   hole. Push it in from the back until it lies on the board.
2. **LDR**: either way round. Bend both legs 90 degrees, 1 mm from its body, so its face (the squiggly side) stands
   up and faces the LED. Legs into the 2 LDR holes from the back.
3. Slide the LED and LDR together until the LED's flat top **touches** the LDR's face. Slip the 15 mm heat shrink over
   both (it covers the whole pair), shrink it with a hair dryer (or the side of the iron's barrel, not the tip).
4. Turn the board over and solder the 4 pins on the printed side, then **snip the legs flush** (they sit under the
   9 V jack's old spot; it's in the left wall now, so nothing is above them, but flush is tidy).
5. Same for the other pair.

Check before soldering the next one: multimeter on ohms across the LDR's two pins: sealed in the dark it reads
**hundreds of kOhm or more**. If it reads low, light gets in: add a second layer of heat shrink.

## 6d. The 2 level lights (under the gain knobs)

Each is a **2-leg red/green LED** (A-1076) in a **chrome bezel** (A-661): green = signal, red = close to clipping, off =
silence. The in light is under Input Gain, the out light under Output Gain. They run from the PCF8574 board's spare
pins (P4-P7), so they need no Seed3 pins.

1. Push the plastic insert (A-7116) into the bezel, the LED into the insert from behind. Bezel through its 5.7 mm hole,
   nut on from inside. **No glue**: the nut holds it.
2. The **right (out) light has the Seed3 socket block 1.7 mm behind it**: bend its legs flat sideways straight away,
   toward the top of the box, before you wire them.
3. Solder a wire to each leg (heat shrink each joint), female jumper end on the other end:
   in light -> **P4** and **P5**; out light -> **P6** and **P7** (either leg on either pin).
4. **330 ohm pull-ups**: on the PCF8574 board's underside solder one 330 ohm from each of **P4, P5, P6, P7** to a
   **VCC** pin's joint (join the 4 VCC ends together first).
5. Power up: each light should be green with signal. Red with signal = swap that light's 2 wires (or set
   `kSwapLightColours = true` in `main.cpp` for both).

On the screen: open the **input** tab, page 2 (page selector to 2): **leveller** on / off, **lights** on / off, and the
leveller's live view: what it cuts now, the last 5 seconds of it against the output level, and the 2 lights.

Every wire, three ways (all from the same list, so they always agree):
- `05-Wiring-and-Schematics/wiring-pictures.pdf`: START HERE. One page per job; every part drawn the way it looks
  from where you solder (the switches' moulded lug numbers 1-8 / A / B, the encoder's row of 3 and row of 2, the pot's
  2 rows), each wire running to its exact lug, and numbered steps in words ("RIGHT pin of the row of 3").
- `wiring-diagram.pdf`: flat, every lug of every part; each wire end says where its other end goes.
- `WIRE-LIST.md`: the tick list.

## 7. The Seed3 socket (RIGHT wall window) and the controls

Build the socket block exactly as `05-Wiring-and-Schematics/WIRING.md` "The socket, way 1" says (jumper ends on the
Seed3's pins, hot-glued into a 2 x 20 block, pushed into the window from inside). Two changes since that was written:
- the window is in the **RIGHT** wall (USB-C still toward the footswitches).
- **key it with pin 16, not pin 1** (pin 1 now drives the screen's RESET). Pin 16 is the Seed3's own audio input, unused
  now: snip pin 16 off the Seed3 and block socket place 16 with hot glue.

Wire list for the controls (other end of each socket jumper):

| part | Seed3 pin |
|---|---|
| pg-1 encoder A / B / push | 2 / 3 / 4 |
| pg-2 encoder A / B / push | 5 / 6 / 7 |
| pg-3 encoder A / B / push | 14 / 15 / 22 |
| pg-4 encoder A / B / push | 26 / 27 / 28 |
| pg-a / pg-b / pg-c footswitch (one lug) | 24 / 25 / 10 |
| screen 1 VCC | 38 |
| screen 3 CS / 4 RESET / 5 DC | 8 / 1 / 37 |
| screen 6 SDI / 7 SCK / 8 LED | 11 / 9 / 23 |
| screen 10 T_CLK / 11 T_CS / 12 T_DIN / 13 T_DO | 29 / 30 / 31 / 36 |
| screen 9 SDO, 14 T_IRQ | leave empty |
| carrier board (section 4) | 12, 13, 32, 33, 34, 35, 39, 40 |

Unused Seed3 pins: 16-21 (its own audio: not used, the carrier board does the audio).

**Ground**: one chain of black wire, part to part: each encoder's middle pin C + its 2nd push pin -> each
footswitch's other lug -> screen pin 2 (GND) -> **spliced onto the gnd jumper** (the one from the carrier's gnd pin to
socket place 40), about 3 cm from the socket: strip 5 mm off that jumper's middle, wrap the chain's end round it,
solder, cover with heat shrink. (A socket place only holds one jumper end, so the chain can't have its own.) (The old "audio chain" to pin 20 is gone: the
jacks' sleeves are on the carrier board's isolated ground and must **not** be connected to anything else.)

## 7b. Headphones: safe with every knob full up

- Hot source (a preamp, a cranked phone): turn **Input Gain** down until it's clean; if the headphones then need
  more, turn **Output Gain** up (up to +21 dB). That's the intended way to use it.
- The output can never go past **2.1 V rms** (the headphone chip's own supply), and the **47 ohm** in each output line
  caps what any headphones can get at about **24 mW** (48 mW if you drive it into hard clipping), whatever their
  impedance, even with both knobs full up and the DSP glitching. 600 ohm headphones still get 1.97 V (loud).
- Use **stereo (TRS) plugs** in the out jack. A mono plug shorts the right side: cranked, its 47 ohm runs hot and
  may burn open (the right channel goes quiet; nothing else is harmed).
- Your ears are the weaker part: start with Output Gain low.

## 8. First power-up

1. **Seed3 out**, carrier board wired. Plug in the 9 V adapter. Multimeter DC volts:
   - expansion header: **3v3 to gnd = 3.3 V**
   - fx loop header: **3v3 to gnd = 3.3 V** (the isolated side). Nothing plugged onto the fx loop.
   - nothing warm. If anything is wrong, unplug and tell me what you measured.
2. Unplug, put the Seed3 in, flash the firmware (USB-C on the right side, `06-Firmware-DaisySeed/README.md`).
3. Power up: the screen starts, the **health** tab should say "all ok".
4. Before the expensive headphones: DC volts across the OUT jack (tip to sleeve) with a cable plugged in: about **0 V**
   (the simulation says ~1 mV). Then plug in at low volume, pg-hp at the middle of its turn (the dot).

## What the simulation checked (so you know what to expect)
The whole routed board in the board simulator (10-Carla-Plugin/Source/sim, every part on its real copper), and the
isolated audio path again in ngspice (the standard circuit simulator) for the worst cases.

- **Power**: from the 9 V jack alone (no USB-C needed: the Seed3 runs off the carrier's vin wire); ~200 mA; isolation
  intact. **Power switch** off = 0 mA; off and straight back on with headphones in: the jack moves under 3 mV.
- **Hard limits (physics, not software):**
  - **Input clamp**: whatever comes in and wherever the in gain knob is, the codec's input pin stays inside its safe
    window (ngspice: -0.02 .. +1.85 V for +-12 / +-24 V hits of 5-150 ms; its limit is -0.3 .. +2.1 V). The analog
    stage clips before the converter does, so the Seed3 never receives anything past full scale.
  - **Output ceiling**: the headphone amp runs on +-3.3 V: the jack can never pass 3.0 V peak (2.1 V rms) whatever the
    firmware does: at most 86 mW into your 50 ohm headset, 132 mW into 32 ohm. The firmware also re-checks the codec's
    own gains every second and puts them back.
  - **The leveller only ever cuts** (it can't add gain); its LEDs top out at ~11 mA (rated 20 mA).
- **Guitar**: the input is 1.46 Mohm, flat to 10 kHz: pickups keep their sparkle (595k before: ~2.4 dB duller).
- **What you can plug in** (in gain knob position for a healthy level; "hiss" = how far below the music the noise is):

  | source | in gain knob | result |
  |---|---|---|
  | dynamic mic straight in (2 mV) | full right | quiet (-44 dBFS): use a mic preamp, or let the input tab add gain |
  | condenser / quiet source (10 mV) | full right | -30 dBFS, hiss 63 dB down |
  | passive guitar | ~95% | clean, hiss 81 dB down |
  | phone / laptop headphone out | ~95% | clean, hiss 84 dB down |
  | consumer line (-10 dBV) | ~95% | clean, hiss 82 dB down |
  | pro line (+4 dBu) | ~75% | clean, hiss 81 dB down |
  | pre-amped / hot (+10 dBu) | ~60% | clean, hiss 82 dB down |
  | cranked headphone amp (3 V rms) | ~50% | clean |
  | very hot (+20 dBu, 7.8 V rms) | any | clips (clean up to 4.8 V rms); nothing breaks |

  Never plug a power amp's **speaker** output in: it would push amps into the input clamp.
- **The analog leveller**: dark = untouched (its 0.39 dB is made up in the firmware); -12 dB at 1.3 mA, -21 dB at
  7.8 mA (the firmware's limit); both channels the same; no click (under 5 mV). Dark for the first 10 s after power-up.
- **Wrong wiring**: swapped data / clock / I2C wires or a missing Seed3 ground just mean no sound (nothing breaks);
  jumpers left on the fx loop are flagged; a reversed 9 V is blocked by D1; a short trips the fuse. **The one wiring
  mistake that can damage parts is 9 V landing on a signal pin**: check the vin wire goes to pin 39.

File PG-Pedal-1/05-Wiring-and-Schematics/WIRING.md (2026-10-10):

# PG-1 wiring (Seed3 cartridge, no extra parts)

> **2026-10-10: OUT OF DATE except the socket-block steps.** Wire from `wiring-diagram.pdf` (every part, lug and wire),
> `wiring-pictures.pdf` (every part drawn as it looks, each wire to its exact lug) and `WIRE-LIST.md`, with `../BUILD-GUIDE.md`. The pin lists
> below predate the carrier board: there is no exp jack any more, no Seed3 pin is free, and there is no audio chain.

> **v3 (isolated carrier board, `12-Carrier-Board`):** the board hangs from the 2 audio jacks (in, out) and does all
> the audio, isolated. The Seed3's own audio pins (16-19) are no longer used. Wires that changed:
> - **carrier board "seed3 + 9v" header** (10 pins): dc + / dc − = the 2 wires from the 9V jack; then jumpers to the
>   Seed3: vin → 39, gnd → 40, scl → 12, sda → 13, sck → 35, fs → 34, tx → 33, rx → 32.
> - **pg-line** and **pg-hp** headers (6 pins each, on the board under the in / out jacks): each header pin is
>   labelled with the POT pin that goes on it: 3 l, 2 l, 1 l, 3 r, 2 r, 1 r (pot pin 3 = its clockwise end, on the
>   header's square pin 1, so turning right = more). Left gang, then right gang. Both pots are centre-click dual 10k LINEAR
>   (e.g. Alps RK09L1240015): analog gain controls, centre = unity.
> - **expansion** header (4 pins, on the board left of "seed3 + 9v"): 3v3, gnd, scl, sda → 4 female jumper ends glued
>   in a row into the expansion bay slot in the LEFT wall (side C). A plug-in module (button, switch, fader...) talks to
>   the Seed3 over that I2C bus (same bus as the seed3 + 9v header's scl / sda).
> - **fx loop** (2 x 4 header on the board, isolated side): **leave it open** - the analog leveller on the board drives its returns (BUILD-GUIDE.md 6c).
> - **headers on the carrier board: solder them** (BUILD-GUIDE.md 2). Their holes are staggered, so a strip grips by
>   friction and stays straight while you solder.
> - **screen**: RESET → 1 (D0), DC → 37 (D30); touch T_DO → 36 (D29); T_IRQ is not used (leave it empty).
> - The IN / OUT / 9V rows in the table below are replaced by the carrier board.

Every part connects to the Daisy Seed3's socket with one wire per pin. There are no resistors, capacitors or chips.
The Seed3 has internal pull-ups for the encoders and switches, its own power regulators, and a reverse-protected VIN (per its datasheet).

**Wiring diagram:** `wiring-diagram.png` (or `.pdf` to print): every wire, in colour.

## How the Seed3 sits: a plug-in cartridge in the left wall

The Seed3 stands on its long edge in a 19 x 52 mm window in the **left side**, parts side facing out, and plugs into a
**socket** inside the window. From outside you can reach USB-C, BOOT and RESET, and swapping a Seed3 is
pull out, push in: **no soldering on the Seed3, ever**. `seed-socket-board.png` shows which socket position is which pin, seen from inside.

### The socket, way 1 (build it like this now): a glued block of jumper ends, no soldering at the socket

The female end of every jumper wire is a small plastic shell exactly 2.54 mm wide, the same as the Seed3's pin spacing.
20 of them side by side make a socket row, so the jumper ends themselves are the socket.

```
 outside | wall |  inside the box
 Seed3   |      |
 ▓▓▓▓▓▓  |      |
 ══════  |      |
 ||||||  ┃[■■■■■]━━━━━━ wire to the part (soldered on the big lugs there, or plugged onto the screen)
  pins   ┃[■■■■■]━━━━━━   ← 2 rows of 20 jumper ends, hot-glued into one block, sitting in the window
         ┃      |
```

**Build the block on the table, not inside the box** (so the glue gun never has to reach into anything):

1. (Optional key) snip pin 1 off the Seed3, see "Key it" below.
2. Lay the Seed3 on a soft cloth, parts side down, pins up.
3. Push a jumper end onto every **used** pin, using `seed-socket-board.png` for the places (34 of them). The unused places (1, 21, 34, 35, 36, 37)
   can stay empty: the glue bridges the gaps. If you keyed it, put a spare jumper end on place 1 and fill it with a dab of glue.
   A few at a time works well: push 3 on, label each wire with a tape flag (its pin number), tack them to their neighbours with a small dab of glue, then the next 3.
   Keep glue on the **backs and sides** of the plastic ends only, never in the front where the pins go.
4. When they're all on, do one full pass: a line of glue in the gap between the two rows and along the outside of each row, so it's one solid block. Let it cool 10 minutes.
5. Pull the Seed3 off. You now have a 2 x 20 socket block with 40 labelled wires.
6. Fit it: take the lid off the pedal and lay it face down: the inside is an open tray, so the left wall is right in front of you.
   Push the block into the window **from inside** (wires trailing into the box) until its front is level with the outside of the wall.
   Plug the Seed3 in from outside to check it lines up, and leave it in.
7. Warm the wall around the window with a hair dryer (cold aluminium makes hot glue let go), then run one bead all the way around where the block meets the
   **inside** of the wall. The nozzle only has to touch the wall from the open back: nothing to thread. That bead overlaps the wall like a lip, so pulling a Seed3 out can't pull the block with it.
   Extra solid (optional): a thin bead around the outside edge of the window too, then the wall is clamped from both sides.
8. Then wire each jumper's other end to its part (wire list below): cut and soldered on the part's big lug, or plugged straight onto the screen's pins.
   Tip: fit the block before the screen and the pg-1 knob go in, for more elbow room.

**Another way to fit it (glue on the outside):** wire everything first with the block loose, then push it into the window from inside until the jumper ends stick
about halfway out of the wall, Seed3 plugged in so it stays square, and glue around it on the **outside** of the wall (plus a bead inside if you can reach).
The Seed3 then sticks out ~14 mm instead of ~7 mm.

Swapping later: unplug 9 V and USB, pull straight out, push the new one in until it stops. If the block ever loosens, re-glue it the same way.

### The socket, way 2 (optional upgrade later): a soldered socket board

Stronger, but it needs its own mounting (the box has no screw holes for it now, so you'd drill 4 by hand). Swap the glued block for this whenever you're happy soldering small joints.
The jumpers move over: cut off their Seed3 ends and solder them to the long header legs instead.

- **Socket board:** one whole A-1192 double-sided prototyping board (30 x 70 mm, a grid of 24 x 10 holes). **No cutting.**
  Every hole has its own tinned ring on both sides, and nothing joins the holes, so neighbouring pins can't short through the board.
  (Don't use a board with copper strips or joined pads: those would short Seed3 pins together.)
- **Where things go** (count from the long edge that will face the pedal's face, see `seed-socket-board.png`):
  - socket rows in the **2nd and 8th row** of holes, leaving 2 empty columns at each end;
- **Building it:**
  1. Plug the 4 header pieces onto the Seed3 (2 per row, ends touching), then push their legs through the board from the side **without** the printed letters,
     into the rows above. Turn it over: the long legs stick out ~9 mm.
  2. Solder each leg to its ring, right at the board (iron on the ring and leg for 2 s, feed solder, a small shiny cone). Corner legs first, check it's straight, then the rest. Pull the Seed3 out.
     The sockets are now held by the board, so they stay put when a Seed3 is pulled out.
  3. Each wire: slide a 6 mm piece of heat shrink onto the wire first. Strip 3 mm, tin it, hold it along the **end half** of its leg and touch the iron.
     Let it cool, slide the heat shrink down over the joint and shrink it by holding the iron's barrel (not the tip) near it. Now no joint can touch its neighbour.
     Work along the row in order, and test each leg against its neighbours with the multimeter's beep mode when the row is done.
- **Wires:** each wire is soldered to the end of its header leg on the back of the socket board (same pin number as the Seed3 pin).
  The screen ends still just plug on. **The back is a mirror image**: use `seed-socket-board.png`, not the Seed3's own pinout.

### Both ways
- **Which way round:** USB-C points toward the footswitches, the parts side faces out, and pins 1-20 are the row nearer the face.
- **Key it so it can't go in backwards:** snip pin 1 (D0, not used) off the Seed3 and block socket place 1 (way 1: hot glue in that jumper end; way 2: glue a snipped resistor leg in).
  Every wrong way round is then blocked. (Backwards would put 9 V on the wrong pins.) Do the same to a spare Seed3.
- **Swapping:** unplug the 9 V and USB first, pull it straight out (don't rock it hard), push the new one fully home,
  then flash the firmware onto it over USB (`06-Firmware-DaisySeed/README.md`). The saved settings are on the Seed3, so a new one starts at defaults.
- It sticks out ~8.5 mm. Don't step on that side, and give it a little room on your desk or pedalboard.
- **BOOT / RESET** are on the outside now, but you'll rarely need them: holding pg-a + pg-b for 2 s does the flash mode.
- **Grounds** (the bottom of `wiring-diagram.png` shows both chains step by step): daisy-chain them, as **two separate chains** of black wire, part to part:
  - **audio chain** (quiet): IN jack sleeve → OUT jack sleeve → the jumper in socket place **20 (AGND)** (the exp jack sleeve joins it once the exp jack is used).
  - **main chain** (everything else): 9V jack − lug → each encoder's C + 2nd push pin → each footswitch's 2nd lug → screen GND → the jumper in socket place **40 (DGND)**.
  - The Seed3 joins the two inside itself. Keeping them apart outside means the screen's and switches' ground current never flows
    through the audio sleeves (less hiss and whine).
  - Don't close a chain into a loop, and don't connect the two chains to each other anywhere else.
  - Each joint has to be solid: if one link breaks, everything after it loses ground. The **health** tab notices most of those
    (a knob that jitters or reads stuck, hum, a silent input side) and says which part.

Screen: `M3×12 black screw → face → 5 mm spacer → screen → M3 nut` (×4). The screen's 14-pin header end goes to the right.

## Wire list

Jumper wires come in mixed colours, so stick a small label or a dot of tape-flag on each one. The black AWG22 wire is only for the ground chain.

| From | Socket place (= Seed3 pin) |
|---|---|
| **IN jack** tip (left) | 16 (AUDIO IN L) |
| IN jack ring (right) | 17 (AUDIO IN R) |
| IN jack sleeve | audio chain → 20 |
| **OUT jack** tip (left) | 18 (AUDIO OUT L) |
| OUT jack ring (right) | 19 (AUDIO OUT R) |
| OUT jack sleeve | audio chain → 20 |
| **9V jack** + lug (sleeve) | 39 (VIN) |
| 9V jack − lug (center pin) | main chain → 40 |
| **pg-1** encoder A / B / push | 2 (D1) / 3 (D2) / 4 (D3) |
| **pg-2** encoder A / B / push | 5 (D4) / 6 (D5) / 7 (D6) |
| **pg-3** encoder A / B / push | 14 (D13) / 15 (D14) / 22 (D15) |
| **pg-4** encoder A / B / push | 26 (D19) / 27 (D20) / 28 (D21) |
| each encoder: middle pin C + 2nd push pin | main chain → 40 |
| **pg-a** lug / other lug | 24 (D17) / main chain |
| **pg-b** lug / other lug | 25 (D18) / main chain |
| **pg-c** lug / other lug | 10 (D9) / main chain |
| **screen** 1 VCC | 38 (3V3 digital) |
| screen 2 GND | main chain → 40 |
| screen 3 CS | 8 (D7) |
| screen 4 RESET | 1 (D0) — v3 (was 13) |
| screen 5 DC | 37 (D30) — v3 (was 12) |
| screen 6 SDI (MOSI) | 11 (D10) |
| screen 7 SCK | 9 (D8) |
| screen 8 LED | 23 (D16) |
| screen 9 SDO | leave empty |
| screen 10 T_CLK / 11 T_CS / 12 T_DIN / 13 T_DO (touch) | 29 (D22) / 30 (D23) / 31 (D24) / 36 (D29) — v3; 14 T_IRQ empty |

Seed3 pin numbers: right-side up with USB-C at the bottom, **pins 1-20 run up the right side** (pin 1 next to USB-C) and **pins 21-40 run down the left side** (pin 40 next to USB-C).
**On the socket board's back it's mirrored:** seen from inside the box (face up, USB-C end on your left), **pins 1-20 are the top row from left to right** and **pins 40-21 the bottom row from left to right**. Pin 1 and pin 40 are the ones at the USB-C end.
See `07-Datasheets/Seed3-Pinout.pdf`.

## Expansion port (for later, no new holes needed)
Free Seed3 pins for later: pin 34 (D27), 36 (D29), 37 (D30). (Pin 10 / D9 is pg-c, pin 35 / D28 is the exp jack.) Their jumpers (way 1) or header legs (way 2) are already there, so nothing ever needs soldering on the Seed3. Anything you add later (LEDs, a sensor, MIDI, a 2nd screen) plugs in there.

**exp jack** (top edge, installed now but not wired): to use it later for an expression pedal, wire **sleeve → ground**, **ring → 3.3 V through a 1 kΩ resistor**, **tip → D28 (pin 35, an analog pin)**,
then it's the pin 35 jumper plus a firmware change. Keep the 1 kΩ: a mono cable shorts ring to sleeve.

- **Encoders**: 3 pins on one side are A, C, B (C in the middle). The 2 pins on the other side are the push switch.
- **Footswitches (A-1091, soft-touch, normally open)**: 2 solder eyelets on the side. One goes to the Seed3 pin, the other to the ground chain. It's pressed = on, released = off; latching is done in firmware.
- **Knobs (A-2850)**: slide on and tighten the set screw against the flat side of the shaft. No need to line anything up, because the encoders turn endlessly.
  If a knob counts backwards, set `kReverseEncoder = true` in the firmware.
- **Jacks and the 9V jack**: find the tip/ring/sleeve and +/− lugs with a multimeter before soldering (beep test with a cable or adapter plugged in).
- **Snap off the little anti-rotation tab** on each encoder; the holes are round. Every part clamps with its own nut.
- Screen wires: about 20 cm, so the plate can come off. If the picture ever glitches, tell me and I'll slow the screen link down in firmware.

## What "no extra parts" means for sound
- **Line level, PC audio, synths, mixers**: ideal.
- **Auto-leveling** happens in the firmware. Quiet sources are brought up and loud ones down to a steady level, and a gate keeps hiss from being pumped up during silence.
- **Guitar or bass plugged in directly** will sound a bit duller and quieter. The Seed3 input isn't the 1 MΩ high-impedance input a passive pickup wants (Electro-Smith adds a buffer chip for that).
  If you play guitar into it a lot, put any buffered pedal (most tuners) in front, or ask me and I'll add a 1-chip buffer later.
- **Dynamic mics** work through a 1/4" adapter, but they are very quiet, so auto-leveling brings up some hiss with them. Condenser mics (phantom power) won't work.
- **Before connecting the output to expensive gear the first time**, set a multimeter to DC volts and measure OUT tip-to-sleeve with the pedal on.
  It should read about 0 V. If it shows more than about 0.1 V, tell me and I'll add a blocking capacitor.

## Flashing
Plug USB-C into the left side. **First time:** take the bottom plate off, hold **BOOT**, tap **RESET** (or flash the Seed3 on your desk before installing it), then flash `06-Firmware-DaisySeed/pg1.bin` at https://flash.daisy.audio
(or run `make program-dfu`). After that, **holding pg-a + pg-b for 2 seconds** puts it into flash mode over the same USB-C, with the box closed.

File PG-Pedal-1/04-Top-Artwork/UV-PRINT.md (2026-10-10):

# Top artwork (UV print)

- **Upload this file:** `pg1-face-uv-print.pdf`. It is exactly 117 × 141 mm (Tayda's 1590XX side A artboard), vector only,
  CMYK with **black = 0/0/0/100**, the accent **pink = 0/58/20/0** (the top dot of each knob ring, the small labels) and the
  **gems** (pixel-art diamonds in 4 deep sea blues, from light 58/4/12/0 to the outline 100/78/35/50), in a layer named
  **CMYK**. A second layer, **RDG_GLOSS**, is a copy of everything in the RDG_GLOSS spot colour: Tayda prints it last as
  clear gloss, so the whole print is shiny and the gems' white glints (left unprinted) shine too. No RDG_WHITE layer
  (the box is white already). (In a PDF viewer the gloss layer shows as a grey-blue tint over everything: that's normal.)
  All text is converted to outlines, so no fonts are needed. Checked against Tayda's UV guide V2 (Apr 2026): artwork stays ≥2 mm inside the artboard,
  ≥3 mm from every hole and 2 mm from the screen window (their face tolerance is ±0.5 mm), and no objects overlap.
- Optional double-check: Tayda's PDF Analyzer (linked in their UV guide, login pdfman / pdfman).
- Look: white enclosure, black print with a few pink accents (matching the pink footswitch caps); smooth rounded ring around the edge;
  all-lowercase rounded font (Nunito, SIL OFL) for the control names and the plain monospace IBM Plex Mono (SIL OFL) for the small words.
  Labels are pg-1 / pg-2 / pg-3 / pg-4 under the encoders (20 dots each = 20 detents),
  pg-a / pg-b with rings, jack labels "out / 9v / usb-c / in" plus "trs l+r", and the one-line logo with "pg audio" under it.
- `pg1-face-preview.png` is a mockup with knobs, switches and the screen. `pg1-face-artwork.svg` is the editable vector version.

On drill.taydakits.com → **New UV print template**:
1. Enclosure **1590XX**, side **A (Face)**, upload `pg1-face-uv-print.pdf`.
2. Tick **"My Design has a CMYK Color"** and **"My Design has RDG Gloss Spot Colors"** (choose **Varnish**: the shiny
   one). Leave **"My Design has RDG White Spot Color"** unticked (the box is already white).
3. Attach it to the same job as the `pg-1` drill template so the print lines up with the holes.

To change any text or position, edit `../../_Tools/pg_generate.py` and run it again. It rebuilds the
drill table, artwork and drawings from the same numbers, so the holes and the print can't drift apart:

```
pip install fonttools
python3 ../../_Tools/pg_generate.py
```

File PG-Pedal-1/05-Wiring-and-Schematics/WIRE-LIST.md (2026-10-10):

# PG-1 wire list

Generated by `_Tools/pg_wiring.py` with `wiring-diagram.png` (the same numbers). Tick each one off as you go.

| # | from | to | colour | how |
|---|---|---|---|---|
| 1 | 9V DC jack: **+ sleeve** | power switch: **A com** | pwr | 9 V + into the switch (solder) |
| 2 | power switch: **A com** | power switch: **B com** | pwr | join both commons (short bare offcut) |
| 3 | power switch: **A2** | carrier J10: **dc +** | pwr | ON lugs -> dc + (join A2-A4 and B2-B4 with bare offcuts first) |
| 4 | power switch: **A2** | power switch: **A3** | pwr | join (bare offcut) |
| 5 | power switch: **A3** | power switch: **A4** | pwr | join (bare offcut) |
| 6 | power switch: **A4** | power switch: **B2** | pwr | join (bare offcut) |
| 7 | power switch: **B2** | power switch: **B3** | pwr | join (bare offcut) |
| 8 | power switch: **B3** | power switch: **B4** | pwr | join (bare offcut) |
| 9 | 9V DC jack: **- centre** | carrier J10: **dc -** | gnd | 9 V - straight to the board (female end on the header) |
| 10 | carrier J10: **vin** | Seed3 socket 39 | pwr | jumper: Seed3 power (9 V, protected) |
| 11 | carrier J10: **gnd** | Seed3 socket 40 | gnd | jumper: Seed3 ground (the ground chain is spliced onto this wire) |
| 12 | carrier J10: **scl** | Seed3 socket 12 | i2c | jumper: I2C clock |
| 13 | carrier J10: **sda** | Seed3 socket 13 | i2c | jumper: I2C data |
| 14 | carrier J10: **sck** | Seed3 socket 35 | sai | jumper: audio bit clock |
| 15 | carrier J10: **fs** | Seed3 socket 34 | sai | jumper: audio frame clock |
| 16 | carrier J10: **tx** | Seed3 socket 33 | sai | jumper: audio Seed3 -> board |
| 17 | carrier J10: **rx** | Seed3 socket 32 | sai | jumper: audio board -> Seed3 |
| 18 | Input Gain pot: **1 l** | carrier pg-line: **1 l** | pot | short wire, soldered on the pot |
| 19 | Input Gain pot: **2 l** | carrier pg-line: **2 l** | pot | short wire, soldered on the pot |
| 20 | Input Gain pot: **3 l** | carrier pg-line: **3 l** | pot | short wire, soldered on the pot |
| 21 | Input Gain pot: **1 r** | carrier pg-line: **1 r** | pot | short wire, soldered on the pot |
| 22 | Input Gain pot: **2 r** | carrier pg-line: **2 r** | pot | short wire, soldered on the pot |
| 23 | Input Gain pot: **3 r** | carrier pg-line: **3 r** | pot | short wire, soldered on the pot |
| 24 | Output Gain pot: **1 l** | carrier pg-hp: **1 l** | pot | short wire, soldered on the pot |
| 25 | Output Gain pot: **2 l** | carrier pg-hp: **2 l** | pot | short wire, soldered on the pot |
| 26 | Output Gain pot: **3 l** | carrier pg-hp: **3 l** | pot | short wire, soldered on the pot |
| 27 | Output Gain pot: **1 r** | carrier pg-hp: **1 r** | pot | short wire, soldered on the pot |
| 28 | Output Gain pot: **2 r** | carrier pg-hp: **2 r** | pot | short wire, soldered on the pot |
| 29 | Output Gain pot: **3 r** | carrier pg-hp: **3 r** | pot | short wire, soldered on the pot |
| 30 | PCF8574 board: **VCC** | carrier expansion: **3v3** | pwr | jumper (3.3 V) |
| 31 | PCF8574 board: **GND** | carrier expansion: **gnd** | gnd | jumper |
| 32 | PCF8574 board: **SDA** | carrier expansion: **sda** | i2c | jumper |
| 33 | PCF8574 board: **SCL** | carrier expansion: **scl** | i2c | jumper |
| 34 | PCF8574 board: **VCC** | expansion bay: **3v3** | pwr | jumper, its far end glued in the bay |
| 35 | PCF8574 board: **GND** | expansion bay: **gnd** | gnd | jumper, its far end glued in the bay |
| 36 | PCF8574 board: **SDA** | expansion bay: **sda** | i2c | jumper, its far end glued in the bay |
| 37 | PCF8574 board: **SCL** | expansion bay: **scl** | i2c | jumper, its far end glued in the bay |
| 38 | page switch: **A1** | PCF8574 board: **P0** | sw | position 1 (find with beep mode) |
| 39 | page switch: **A2** | PCF8574 board: **P1** | sw | position 2 |
| 40 | page switch: **A3** | PCF8574 board: **P2** | sw | position 3 |
| 41 | page switch: **A4** | PCF8574 board: **P3** | sw | position 4 |
| 42 | page switch: **A com** | PCF8574 board: **GND** | gnd | pole A common: solder it on the UNDERSIDE of the PCF board, on the GND pin's solder joint |
| 43 | in level light: **leg 1** | PCF8574 board: **P4** | led | in light (swap its 2 legs, or set kSwapLightColours, if the colours are backwards) |
| 44 | in level light: **leg 2** | PCF8574 board: **P5** | led | in light |
| 45 | out level light: **leg 1** | PCF8574 board: **P6** | led | out light |
| 46 | out level light: **leg 2** | PCF8574 board: **P7** | led | out light |
| 47 | 4 x 330 ohm: **a1** | PCF8574 board: **P4** | led | 330 ohm pull-up: solder its leg on the PCF board's underside, on P4's joint |
| 48 | 4 x 330 ohm: **a2** | PCF8574 board: **P5** | led | 330 ohm pull-up |
| 49 | 4 x 330 ohm: **a3** | PCF8574 board: **P6** | led | 330 ohm pull-up |
| 50 | 4 x 330 ohm: **a4** | PCF8574 board: **P7** | led | 330 ohm pull-up |
| 51 | 4 x 330 ohm: **b1** | PCF8574 board: **VCC** | pwr | the 4 resistors' other ends joined -> underside of a VCC pin's joint |
| 52 | 4 x 330 ohm: **b1** | 4 x 330 ohm: **b2** | pwr | join |
| 53 | 4 x 330 ohm: **b2** | 4 x 330 ohm: **b3** | pwr | join |
| 54 | 4 x 330 ohm: **b3** | 4 x 330 ohm: **b4** | pwr | join |
| 55 | screen A-8180: **1 VCC** | Seed3 socket 38 | pwr | jumper: 3.3 V |
| 56 | screen A-8180: **3 CS** | Seed3 socket 8 | lcd | jumper |
| 57 | screen A-8180: **4 RST** | Seed3 socket 1 | lcd | jumper |
| 58 | screen A-8180: **5 DC** | Seed3 socket 37 | lcd | jumper |
| 59 | screen A-8180: **6 SDI** | Seed3 socket 11 | lcd | jumper |
| 60 | screen A-8180: **7 SCK** | Seed3 socket 9 | lcd | jumper |
| 61 | screen A-8180: **8 LED** | Seed3 socket 23 | lcd | jumper: backlight |
| 62 | screen A-8180: **10 TCLK** | Seed3 socket 29 | lcd | jumper: touch |
| 63 | screen A-8180: **11 TCS** | Seed3 socket 30 | lcd | jumper: touch |
| 64 | screen A-8180: **12 TDIN** | Seed3 socket 31 | lcd | jumper: touch |
| 65 | screen A-8180: **13 TDO** | Seed3 socket 36 | lcd | jumper: touch |
| 66 | pg-1 encoder: **A** | Seed3 socket 2 | enc | jumper |
| 67 | pg-1 encoder: **B** | Seed3 socket 3 | enc | jumper |
| 68 | pg-1 encoder: **push** | Seed3 socket 4 | enc | jumper |
| 69 | pg-2 encoder: **A** | Seed3 socket 5 | enc | jumper |
| 70 | pg-2 encoder: **B** | Seed3 socket 6 | enc | jumper |
| 71 | pg-2 encoder: **push** | Seed3 socket 7 | enc | jumper |
| 72 | pg-3 encoder: **A** | Seed3 socket 14 | enc | jumper |
| 73 | pg-3 encoder: **B** | Seed3 socket 15 | enc | jumper |
| 74 | pg-3 encoder: **push** | Seed3 socket 22 | enc | jumper |
| 75 | pg-4 encoder: **A** | Seed3 socket 26 | enc | jumper |
| 76 | pg-4 encoder: **B** | Seed3 socket 27 | enc | jumper |
| 77 | pg-4 encoder: **push** | Seed3 socket 28 | enc | jumper |
| 78 | pg-a footswitch: **lug 1** | Seed3 socket 24 | sw | jumper |
| 79 | pg-b footswitch: **lug 1** | Seed3 socket 25 | sw | jumper |
| 80 | pg-c footswitch: **lug 1** | Seed3 socket 10 | sw | jumper |
| 81 | pg-1 encoder: **C** | pg-1 encoder: **push 2** | gnd | ground chain |
| 82 | pg-1 encoder: **push 2** | pg-2 encoder: **C** | gnd | ground chain |
| 83 | pg-2 encoder: **C** | pg-2 encoder: **push 2** | gnd | ground chain |
| 84 | pg-2 encoder: **push 2** | pg-3 encoder: **C** | gnd | ground chain |
| 85 | pg-3 encoder: **C** | pg-3 encoder: **push 2** | gnd | ground chain |
| 86 | pg-3 encoder: **push 2** | pg-4 encoder: **C** | gnd | ground chain |
| 87 | pg-4 encoder: **C** | pg-4 encoder: **push 2** | gnd | ground chain |
| 88 | pg-4 encoder: **push 2** | pg-a footswitch: **lug 2** | gnd | ground chain |
| 89 | pg-a footswitch: **lug 2** | pg-b footswitch: **lug 2** | gnd | ground chain |
| 90 | pg-b footswitch: **lug 2** | pg-c footswitch: **lug 2** | gnd | ground chain |
| 91 | pg-c footswitch: **lug 2** | screen A-8180: **2 GND** | gnd | ground chain (screen GND: cut a jumper, solder its cut end in the chain) |
| 92 | screen A-8180: **2 GND** | Seed3 socket 40 | gnd | chain's end: SPLICED onto the j10.gnd -> seed.40 jumper, 3 cm from the socket (strip 5 mm, wrap, solder, heat shrink). A socket place holds one jumper only |

Leave empty: 9V DC jack: **switch** (not used), power switch: **A1** (OFF position: empty), power switch: **B1** (OFF position: empty), screen A-8180: **9 SDO** (empty), screen A-8180: **14 TIRQ** (empty).

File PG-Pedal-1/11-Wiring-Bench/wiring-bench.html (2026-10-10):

# PG-1 Wiring Bench Wire the pedal here first. Tap a terminal on a part, then the Seed3 pin or ground chain it goes to. Tap a wire to remove it.

0 of 49 wired Show where it goes Check as I go Wire it for me Clear Power up

Pick a terminal on any part to start (the dots on the cards).

left audioright audio encodersscreen footswitchespower ground chain

## Your PG-1

pg audio pg-1off

Not powered yet.

Wire it, then press Power up.

### Try the controls

The pedal reports what it notices here.

Reference: the wiring diagram

PG-1 wiring diagram: every part's wires to the Seed3 pins, and the two ground chains

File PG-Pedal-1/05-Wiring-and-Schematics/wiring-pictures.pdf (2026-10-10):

# PG-1 wiring 1/10: Power: 9V jack -> power switch -> carrier board -> Seed3

+ (red) goes into BOTH commons, A and B. Lugs 2 3 4 and 6 7 8 are all ON: link them with bare offcuts (the short silver links, bent round
the OUTSIDE so they never touch lug 1 or 5) and run ONE red wire from them to 'dc +'. Lugs 1 and 5 = OFF: leave them empty.

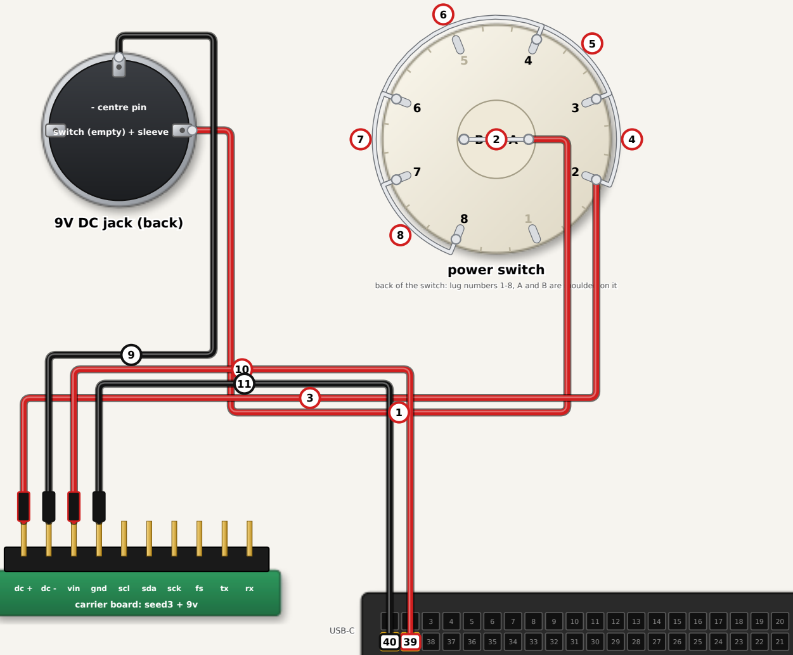
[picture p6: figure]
9V DC jack (back); - centre pin; switch (empty) + sleeve; power switch; carrier board: seed3 + 9v; vin; gnd; scl; sda; sck; USB-C

back of the switch: lug numbers 1-8, A and B are moulded on it

Seed3 socket: the jumper-end block in the right wall, from INSIDE (USB-C end on your left)

## Steps (the number is on the wire)

1 9V jack: the SLEEVE lug, on the side: + -> power switch: common A (the inner lug by the moulded 'A')
9 V + into the switch (solder)

### 2 power switch: common A (the inner lug by the moulded

'A') -> power switch: common B (the inner lug by the moulded 'B')
join both commons (short bare offcut)

### 3 power switch: lug 2 (pole A, position 2) -> carrier

'seed3 + 9v' header: 'dc +' (1st from the left)
ON lugs -> dc + (join A2-A4 and B2-B4 with bare offcuts first)

### 4 power switch: lug 2 (pole A, position 2) -> power

switch: lug 3 (pole A, position 3)
join (bare offcut)

### 5 power switch: lug 3 (pole A, position 3) -> power

switch: lug 4 (pole A, position 4)
join (bare offcut)

### 6 power switch: lug 4 (pole A, position 4) -> power

switch: lug 6 (pole B, position 2)
join (bare offcut)

### 7 power switch: lug 6 (pole B, position 2) -> power

switch: lug 7 (pole B, position 3)
join (bare offcut)

### 8 power switch: lug 7 (pole B, position 3) -> power

switch: lug 8 (pole B, position 4)
join (bare offcut)
9 9V jack: the CENTRE-PIN lug, the middle one: - (centre negative) -> carrier 'seed3 + 9v' header: 'dc -' (2nd from the left)
9 V - straight to the board (female end on the header)

### 10 carrier 'seed3 + 9v' header: 'vin' (3rd from the left)

-> Seed3 socket place 39 (bottom row)
jumper: Seed3 power (9 V, protected)

### 11 carrier 'seed3 + 9v' header: 'gnd' (4th from the left)

-> Seed3 socket place 40 (bottom row)
jumper: Seed3 ground (the ground chain is spliced onto this wire)

# PG-1 wiring 2/10: Carrier board -> Seed3: the 6 signal jumpers

Plug these onto the board's header BEFORE the board goes in the box (the names are printed on the board). Their other ends go into the Seed3 socket places shown.

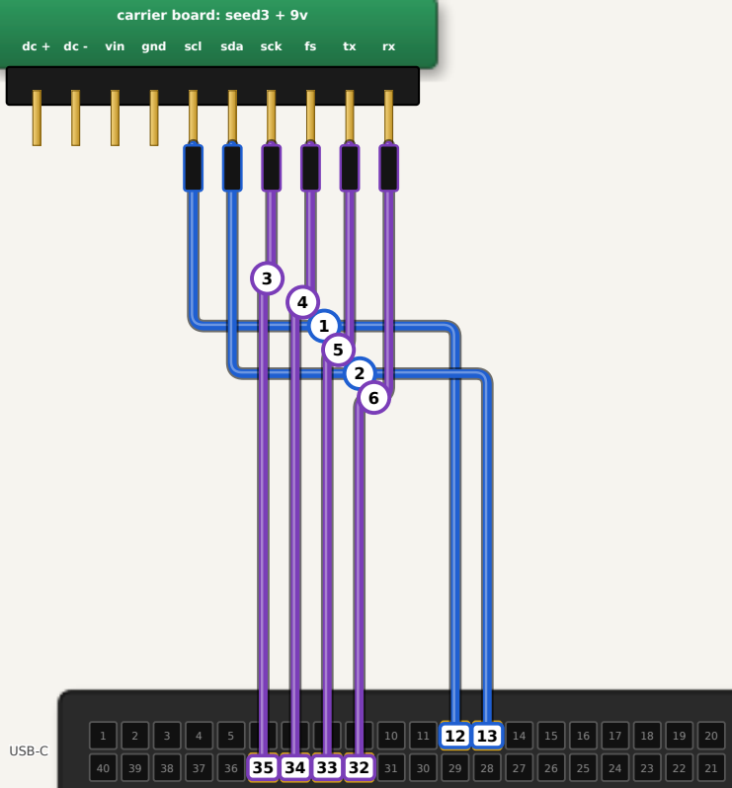
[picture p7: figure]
carrier board: seed3 + 9v; vin; gnd; scl; sda; sck; USB-C

Seed3 socket: the jumper-end block in the right wall, from INSIDE (USB-C end on your left)

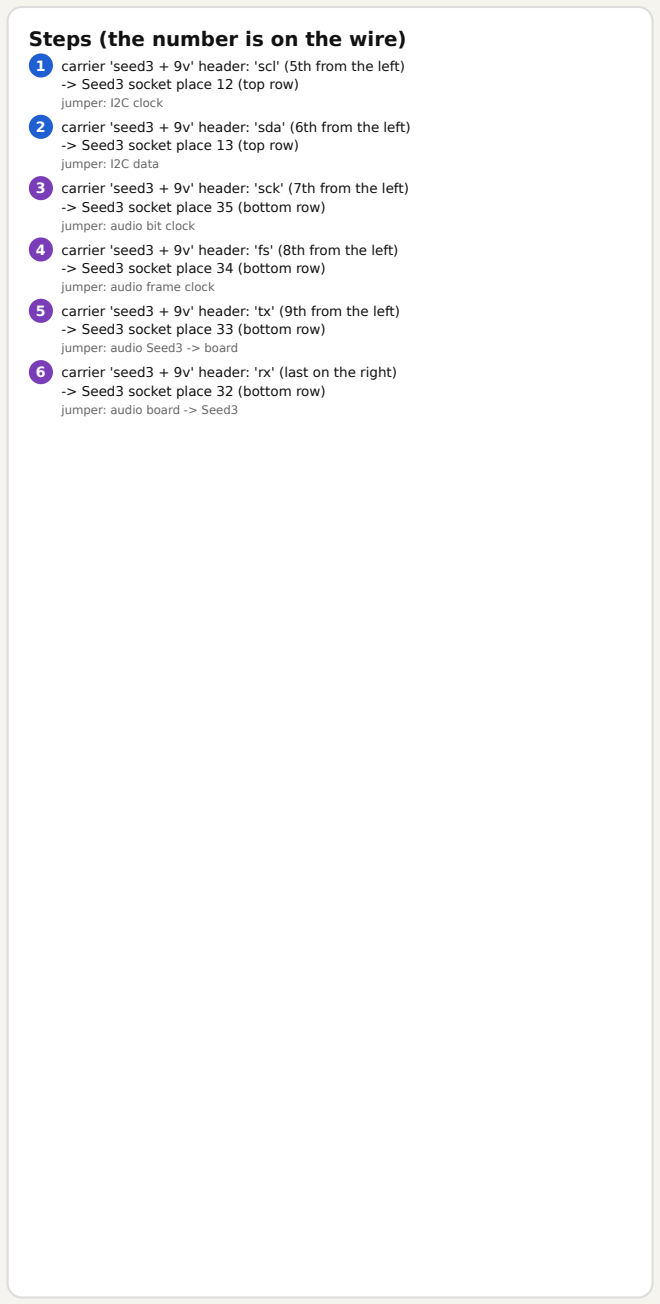
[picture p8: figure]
Steps (the number is on the wire); -> Seed3 socket place 12 (top row) jumper: I2C clock; -> Seed3 socket place 13 (top row) jumper: I2C data; -> Seed3 socket place 35 (bottom row) jumper: audio bit clock; -> Seed3 socket place 34 (bottom row) jumper: audio frame clock; -> Seed3 socket place 33 (bottom row) jumper: audio Seed3 -> board; -> Seed3 socket place 32 (bottom row) jumper: audio board -> Seed3

### 1 carrier 'seed3 + 9v' header: 'scl' (5th from the left)

### 2 carrier 'seed3 + 9v' header: 'sda' (6th from the left)

### 3 carrier 'seed3 + 9v' header: 'sck' (7th from the left)

### 4 carrier 'seed3 + 9v' header: 'fs' (8th from the left)

### 5 carrier 'seed3 + 9v' header: 'tx' (9th from the left)

### 6 carrier 'seed3 + 9v' header: 'rx' (last on the right)

# PG-1 wiring 3/10: The gain pots -> their headers on the carrier board

Short wires soldered on each pot, a female jumper end on the header. The pot's row nearer the PANEL is 'l', the row nearer YOU is 'r'. The
header names are printed on the board.

## Input Gain

back of the pot

## Output Gain

back of the pot

## Steps (the number is on the wire)

### 1 Input Gain: pin 1 l (RIGHT pin of the row nearer the

PANEL) -> carrier 'in gain knob' header: '1 l' (3rd from the left)

### 2 Input Gain: pin 2 l (MIDDLE pin of the row nearer the

PANEL) -> carrier 'in gain knob' header: '2 l' (2nd from the left)

### 3 Input Gain: pin 3 l (LEFT pin of the row nearer the

PANEL) -> carrier 'in gain knob' header: '3 l' (1st from the left)

### 4 Input Gain: pin 1 r (RIGHT pin of the row nearer YOU)

-> carrier 'in gain knob' header: '1 r' (last on the right)

### 5 Input Gain: pin 2 r (MIDDLE pin of the row nearer YOU)

-> carrier 'in gain knob' header: '2 r' (5th from the left)

### 6 Input Gain: pin 3 r (LEFT pin of the row nearer YOU)

-> carrier 'in gain knob' header: '3 r' (4th from the left)

### 7 Output Gain: pin 1 l (RIGHT pin of the row nearer the

PANEL) -> carrier 'out gain knob' header: '1 l' (3rd from the left)

### 8 Output Gain: pin 2 l (MIDDLE pin of the row nearer the

PANEL) -> carrier 'out gain knob' header: '2 l' (2nd from the left)

### 9 Output Gain: pin 3 l (LEFT pin of the row nearer the

PANEL) -> carrier 'out gain knob' header: '3 l' (1st from the left)

### 10 Output Gain: pin 1 r (RIGHT pin of the row nearer YOU)

-> carrier 'out gain knob' header: '1 r' (last on the right)

### 11 Output Gain: pin 2 r (MIDDLE pin of the row nearer YOU)

-> carrier 'out gain knob' header: '2 r' (5th from the left)

### 12 Output Gain: pin 3 r (LEFT pin of the row nearer YOU)

-> carrier 'out gain knob' header: '3 r' (4th from the left)

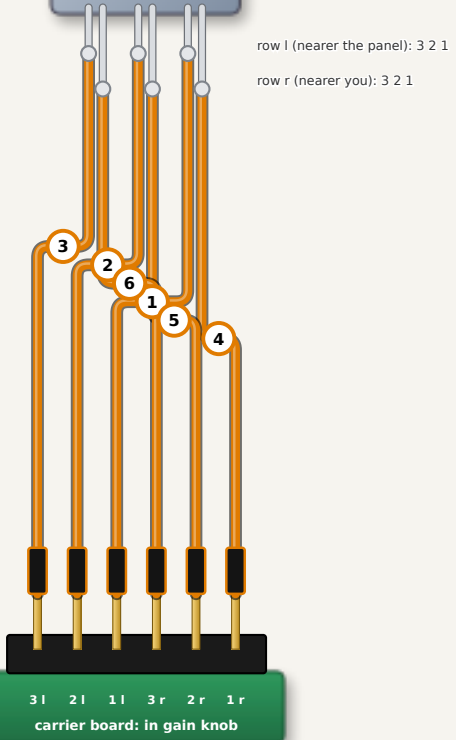
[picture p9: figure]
row l (nearer the panel): 3 2 1; row r (nearer you): 3 2 1; carrier board: in gain knob
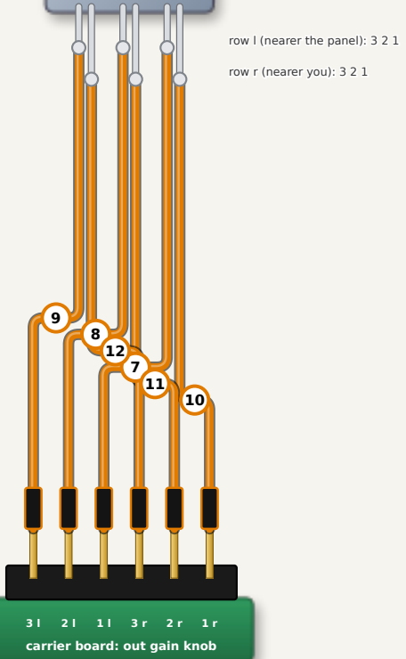
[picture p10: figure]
row l (nearer the panel): 3 2 1; row r (nearer you): 3 2 1; carrier board: out gain knob

# PG-1 wiring 4/10: Screen -> Seed3

Read the names printed beside the screen's pins. 'SDO(MISO)' and 'T_IRQ' stay empty; 'GND' is on the ground-chain page. screen module, back

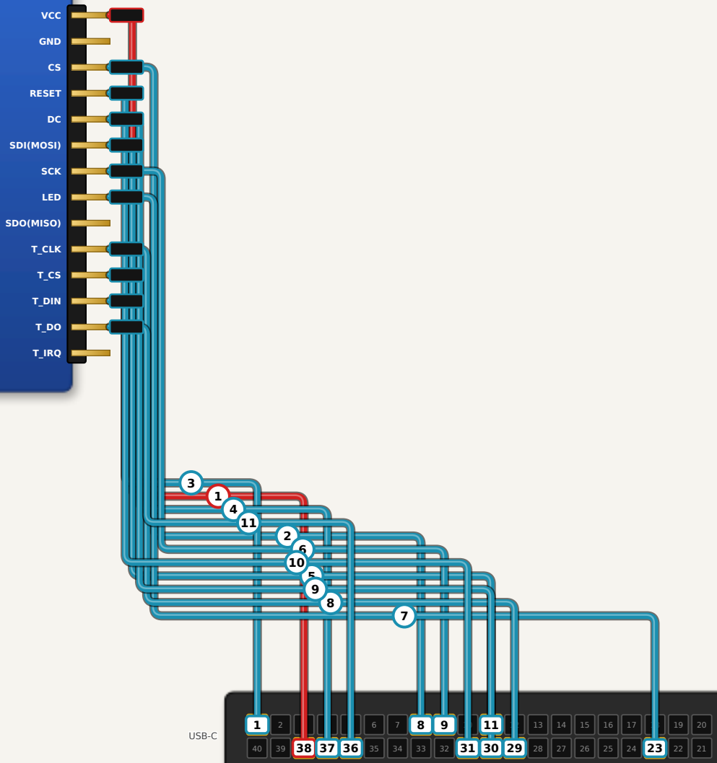
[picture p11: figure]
VCC; GND; RESET; SDI(MOSI); SCK; LED; SDO(MISO); T_CLK; T_DIN; T_IRQ; USB-C

Seed3 socket: the jumper-end block in the right wall, from INSIDE (USB-C end on your left)

## Steps (the number is on the wire)

### 1 screen: the pin printed 'VCC' (pin 1) -> Seed3 socket

place 38 (bottom row)
jumper: 3.3 V

### 2 screen: the pin printed 'CS' (pin 3) -> Seed3 socket

place 8 (top row)

### 3 screen: the pin printed 'RESET' (pin 4) -> Seed3

socket place 1 (top row)

### 4 screen: the pin printed 'DC' (pin 5) -> Seed3 socket

place 37 (bottom row)

### 5 screen: the pin printed 'SDI(MOSI)' (pin 6) -> Seed3

socket place 11 (top row)

### 6 screen: the pin printed 'SCK' (pin 7) -> Seed3 socket

place 9 (top row)

### 7 screen: the pin printed 'LED' (pin 8) -> Seed3 socket

place 23 (bottom row)
jumper: backlight

### 8 screen: the pin printed 'T_CLK' (pin 10) -> Seed3

socket place 29 (bottom row)
jumper: touch

### 9 screen: the pin printed 'T_CS' (pin 11) -> Seed3

socket place 30 (bottom row)
jumper: touch

### 10 screen: the pin printed 'T_DIN' (pin 12) -> Seed3

socket place 31 (bottom row)
jumper: touch

### 11 screen: the pin printed 'T_DO' (pin 13) -> Seed3

socket place 36 (bottom row)
jumper: touch

# PG-1 wiring 5/10: The 4 encoders -> Seed3

On the back of each encoder: a row of 3 pins and a row of 2. C and 'push 2' are on the ground-chain page. If a knob turns the wrong way, flip 'knobs' in the config tab: no rewiring.

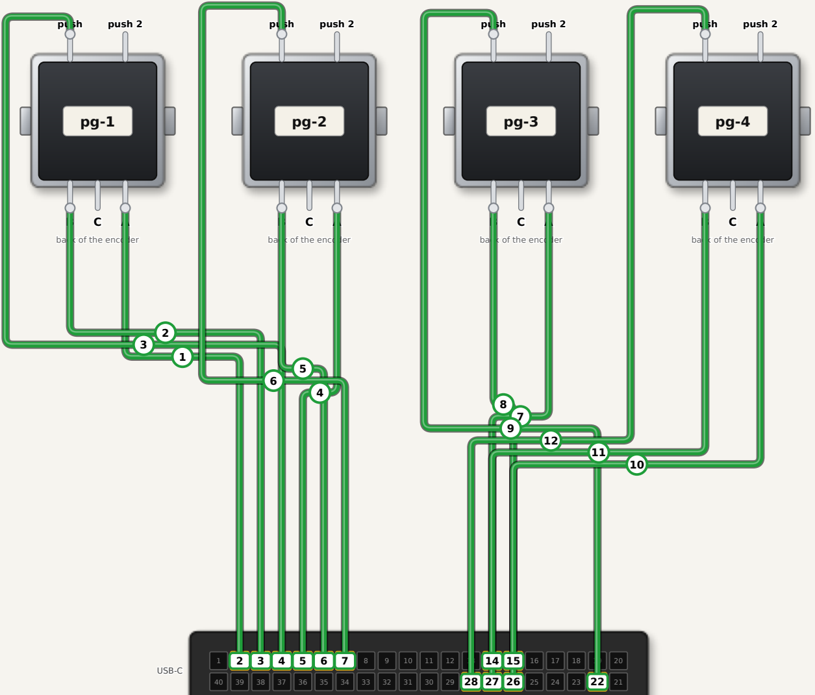
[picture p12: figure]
push; push 2; back of the encoder; USB-C

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

## Steps (the number is on the wire)

### 1 pg-1 encoder: RIGHT pin of the row of 3 (A) -> Seed3

socket place 2 (top row)

### 2 pg-1 encoder: LEFT pin of the row of 3 (B) -> Seed3

socket place 3 (top row)

### 3 pg-1 encoder: LEFT pin of the 2 (push) -> Seed3

socket place 4 (top row)

### 4 pg-2 encoder: RIGHT pin of the row of 3 (A) -> Seed3

socket place 5 (top row)

### 5 pg-2 encoder: LEFT pin of the row of 3 (B) -> Seed3

socket place 6 (top row)

### 6 pg-2 encoder: LEFT pin of the 2 (push) -> Seed3

socket place 7 (top row)

### 7 pg-3 encoder: RIGHT pin of the row of 3 (A) -> Seed3

socket place 14 (top row)

### 8 pg-3 encoder: LEFT pin of the row of 3 (B) -> Seed3

socket place 15 (top row)

### 9 pg-3 encoder: LEFT pin of the 2 (push) -> Seed3

socket place 22 (bottom row)

### 10 pg-4 encoder: RIGHT pin of the row of 3 (A) -> Seed3

socket place 26 (bottom row)

### 11 pg-4 encoder: LEFT pin of the row of 3 (B) -> Seed3

socket place 27 (bottom row)

### 12 pg-4 encoder: LEFT pin of the 2 (push) -> Seed3

socket place 28 (bottom row)

# PG-1 wiring 6/10: The 3 footswitches -> Seed3

Either lug of each footswitch goes to its Seed3 place; the other lug is on the ground-chain page.

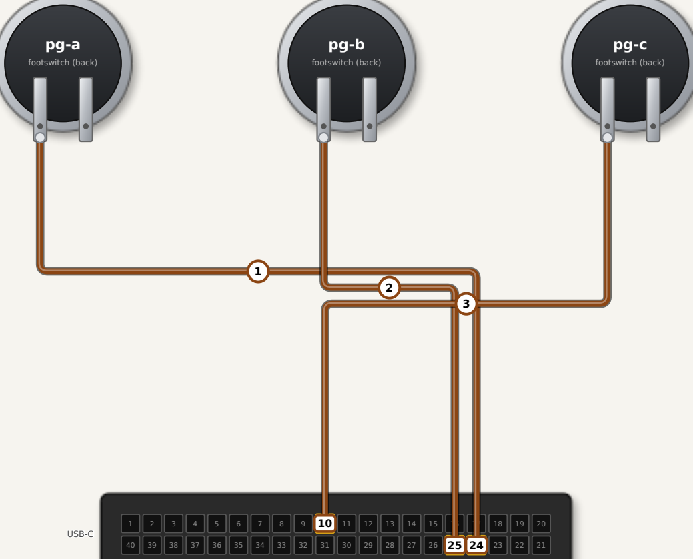
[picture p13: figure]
footswitch (back); USB-C

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

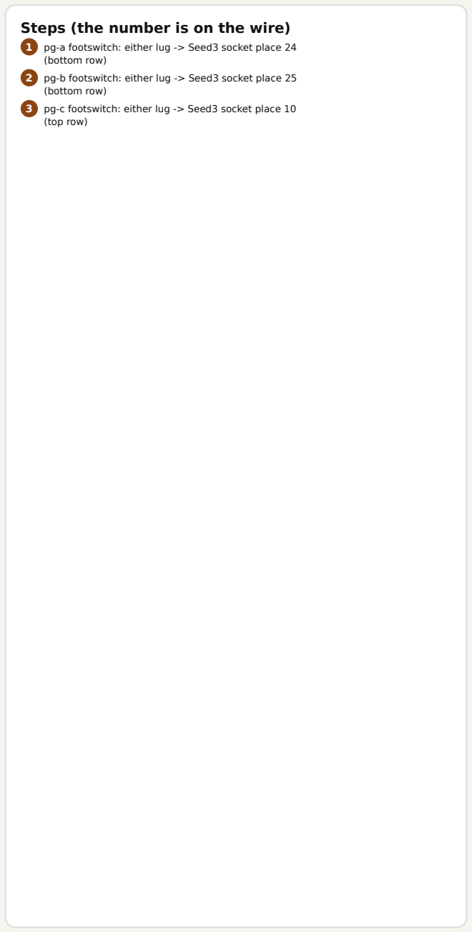
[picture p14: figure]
Steps (the number is on the wire); (bottom row); (top row)

### 1 pg-a footswitch: either lug -> Seed3 socket place 24

### 2 pg-b footswitch: either lug -> Seed3 socket place 25

### 3 pg-c footswitch: either lug -> Seed3 socket place 10

# PG-1 wiring 7/10: The ground chain (black wire, part to part)

One black wire from each lug to the next, in step order. The last one (from the screen's GND) is SPLICED onto the jumper that runs from the board's 'gnd' to Seed3 place 40, about 3 cm from the socket: strip 5 mm, wrap, solder, heat shrink (a socket place only holds one jumper end).

pg-1

### B C A

push push 2

back of the encoder

pg-2

### B C A

push push 2

back of the encoder

pg-3

### B C A

push push 2

back of the encoder

pg-4

### B C A

push push 2

back of the encoder

## pg-a

footswitch (back)

## pg-b

footswitch (back)

## pg-c

footswitch (back)

### screen module, back

VCC
GND
CS
RESET
DC
SDI(MOSI)
SCK
LED
SDO(MISO)
T_CLK
T_CS
T_DIN
T_DO
T_IRQ

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

1 | 2
| 39

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
USB-C
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
## Steps (the number is on the wire)

### 1 pg-1 encoder: MIDDLE pin of the row of 3 (C) -> pg-1

encoder: RIGHT pin of the 2 (push 2)

### 2 pg-1 encoder: RIGHT pin of the 2 (push 2) -> pg-2

encoder: MIDDLE pin of the row of 3 (C)

### 3 pg-2 encoder: MIDDLE pin of the row of 3 (C) -> pg-2

encoder: RIGHT pin of the 2 (push 2)

### 4 pg-2 encoder: RIGHT pin of the 2 (push 2) -> pg-3

encoder: MIDDLE pin of the row of 3 (C)

### 5 pg-3 encoder: MIDDLE pin of the row of 3 (C) -> pg-3

encoder: RIGHT pin of the 2 (push 2)

### 6 pg-3 encoder: RIGHT pin of the 2 (push 2) -> pg-4

encoder: MIDDLE pin of the row of 3 (C)

### 7 pg-4 encoder: MIDDLE pin of the row of 3 (C) -> pg-4

encoder: RIGHT pin of the 2 (push 2)

### 8 pg-4 encoder: RIGHT pin of the 2 (push 2) -> pg-a

footswitch: the other lug

### 9 pg-a footswitch: the other lug -> pg-b footswitch:

the other lug

### 10 pg-b footswitch: the other lug -> pg-c footswitch:

the other lug

### 11 pg-c footswitch: the other lug -> screen: the pin

printed 'GND' (pin 2)
ground chain (screen GND: cut a jumper, solder its cut
end in the chain)

### 12 screen: the pin printed 'GND' (pin 2) -> Seed3 socket

place 40 (bottom row)
chain's end: SPLICED onto the j10.gnd -> seed.40
jumper, 3 cm from the socket (strip 5 mm, wrap, solder, heat shrink). A socket place holds one jumper only

# PG-1 wiring 8/10: PCF8574 board -> carrier board and the expansion bay

The 4 input pins go to the board's 'expansion' header; the 4 pass-through pins go to the bay in the left wall. The PCF8574 board sits on the
inside of the lid (velcro).

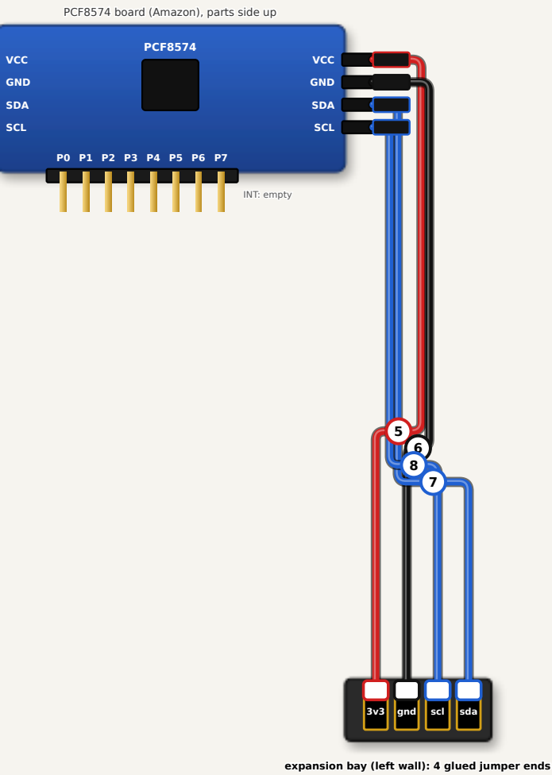
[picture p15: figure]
PCF8574; PCF8574 board (Amazon), parts side up; VCC; GND; SDA; SCL; INT: empty; 3v3 gnd; scl; sda
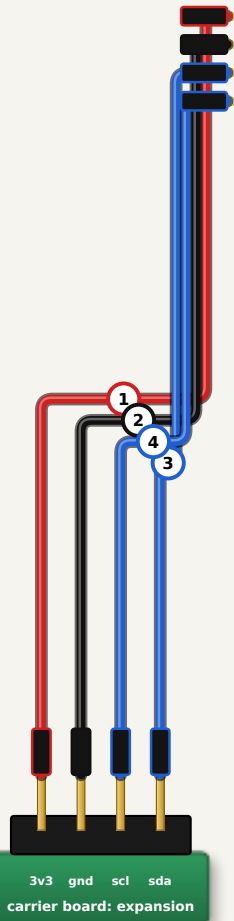
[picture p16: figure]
carrier board: expansion; 3v3 gnd; scl; sda

expansion bay (left wall): 4 glued jumper ends

## Steps (the number is on the wire)

### 1 PCF8574: 'VCC' on the INPUT pins (left end) ->

carrier 'expansion' header: '3v3' (1st from the left)
jumper (3.3 V)

### 2 PCF8574: 'GND' on the INPUT pins (left end) ->

carrier 'expansion' header: 'gnd' (2nd from the left)

### 3 PCF8574: 'SDA' on the INPUT pins (left end) ->

carrier 'expansion' header: 'sda' (last on the right)

### 4 PCF8574: 'SCL' on the INPUT pins (left end) ->

carrier 'expansion' header: 'scl' (3rd from the left)

### 5 PCF8574: 'VCC' on the PASS-THROUGH pins (right end) ->

expansion bay: the '3v3' jumper end
jumper, its far end glued in the bay

### 6 PCF8574: 'GND' on the PASS-THROUGH pins (right end) ->

expansion bay: the 'gnd' jumper end
jumper, its far end glued in the bay

### 7 PCF8574: 'SDA' on the PASS-THROUGH pins (right end) ->

expansion bay: the 'sda' jumper end
jumper, its far end glued in the bay

### 8 PCF8574: 'SCL' on the PASS-THROUGH pins (right end) ->

expansion bay: the 'scl' jumper end
jumper, its far end glued in the bay

# PG-1 wiring 9/10: Page switch -> PCF8574 board

Pole A only: lugs 1 2 3 4 and common A. Pole B (5 6 7 8 and B) stays empty. Common A goes to GND; that pin already has the carrier's jumper on it, so solder this one on the PCF board's UNDERSIDE, on GND's joint.

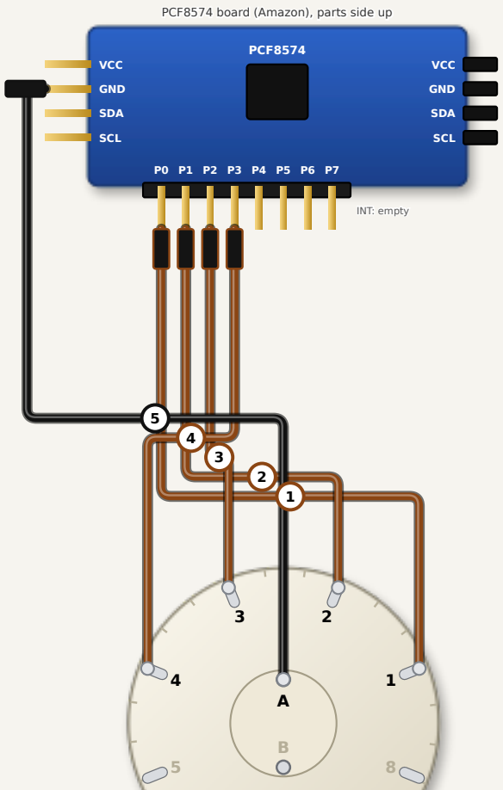
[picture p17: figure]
PCF8574; PCF8574 board (Amazon), parts side up; VCC; GND; SDA; SCL; INT: empty

## page switch

back of the switch: lug numbers 1-8, A and B are moulded on it; drawn turned (it fits any way round)

6 7

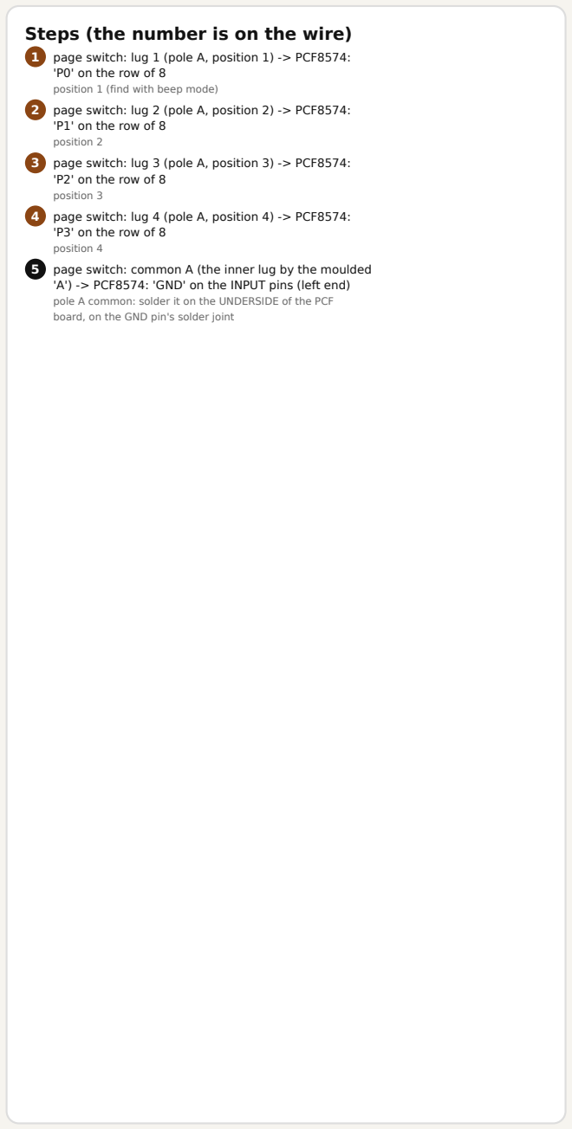
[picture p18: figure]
Steps (the number is on the wire); 'P0' on the row of 8 position 1 (find with beep mode); 'P1' on the row of 8 position 2; 'P2' on the row of 8 position 3; 'P3' on the row of 8 position 4; board, on the GND pin's solder joint

### 1 page switch: lug 1 (pole A, position 1) -> PCF8574:

### 2 page switch: lug 2 (pole A, position 2) -> PCF8574:

### 3 page switch: lug 3 (pole A, position 3) -> PCF8574:

### 4 page switch: lug 4 (pole A, position 4) -> PCF8574:

### 5 page switch: common A (the inner lug by the moulded

'A') -> PCF8574: 'GND' on the INPUT pins (left end)
pole A common: solder it on the UNDERSIDE of the PCF

# PG-1 wiring 10/10: Level lights + 330 ohm resistors -> PCF8574 board

Each light's 2 legs go to 2 P pins, either way round (red with signal? swap that light's 2 wires). P4-P7 each also get a 330 ohm to VCC,
soldered on the PCF board's UNDERSIDE; the 4 resistors' bottom legs are joined and go to a VCC pin.

## Steps (the number is on the wire)

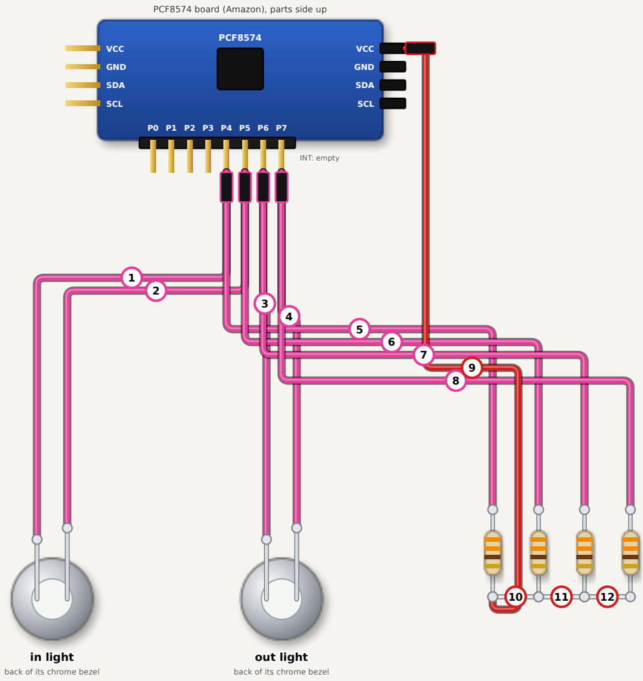
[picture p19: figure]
PCF8574; PCF8574 board (Amazon), parts side up; VCC; GND; SDA; SCL; INT: empty; in light; back of its chrome bezel; out light

### 1 in light: the LEFT leg (either way round) -> PCF8574:

'P4' on the row of 8
in light (swap its 2 legs, or set kSwapLightColours, if
the colours are backwards)

### 2 in light: the RIGHT leg (either way round) ->

PCF8574: 'P5' on the row of 8
in light

### 3 out light: the LEFT leg (either way round) ->

PCF8574: 'P6' on the row of 8
out light

### 4 out light: the RIGHT leg (either way round) ->

PCF8574: 'P7' on the row of 8
out light
5 330 ohm resistor 1: its TOP leg -> PCF8574: 'P4' on the row of 8
330 ohm pull-up: solder its leg on the PCF board's underside, on P4's joint
6 330 ohm resistor 2: its TOP leg -> PCF8574: 'P5' on the row of 8
330 ohm pull-up
7 330 ohm resistor 3: its TOP leg -> PCF8574: 'P6' on the row of 8
330 ohm pull-up
8 330 ohm resistor 4: its TOP leg -> PCF8574: 'P7' on the row of 8
330 ohm pull-up
9 330 ohm resistor 1: its BOTTOM leg -> PCF8574: 'VCC' on the PASS-THROUGH pins (right end)
the 4 resistors' other ends joined -> underside of a
VCC pin's joint
10 330 ohm resistor 1: its BOTTOM leg -> 330 ohm resistor 2: its BOTTOM leg
join
11 330 ohm resistor 2: its BOTTOM leg -> 330 ohm resistor 3: its BOTTOM leg
join
12 330 ohm resistor 3: its BOTTOM leg -> 330 ohm resistor 4: its BOTTOM leg
join

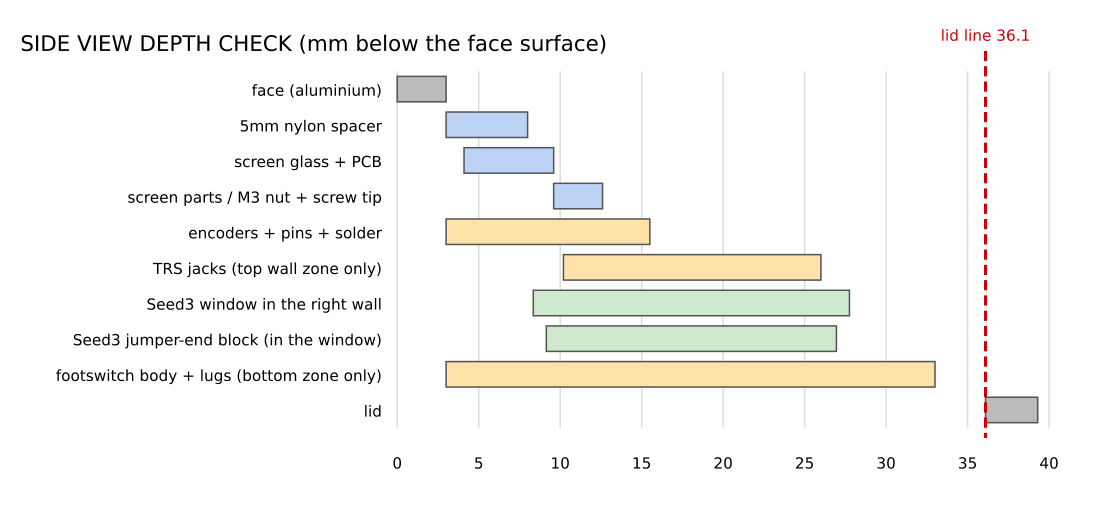
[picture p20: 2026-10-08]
PG-Pedal-1/05-Wiring-and-Schematics/depth-check.png

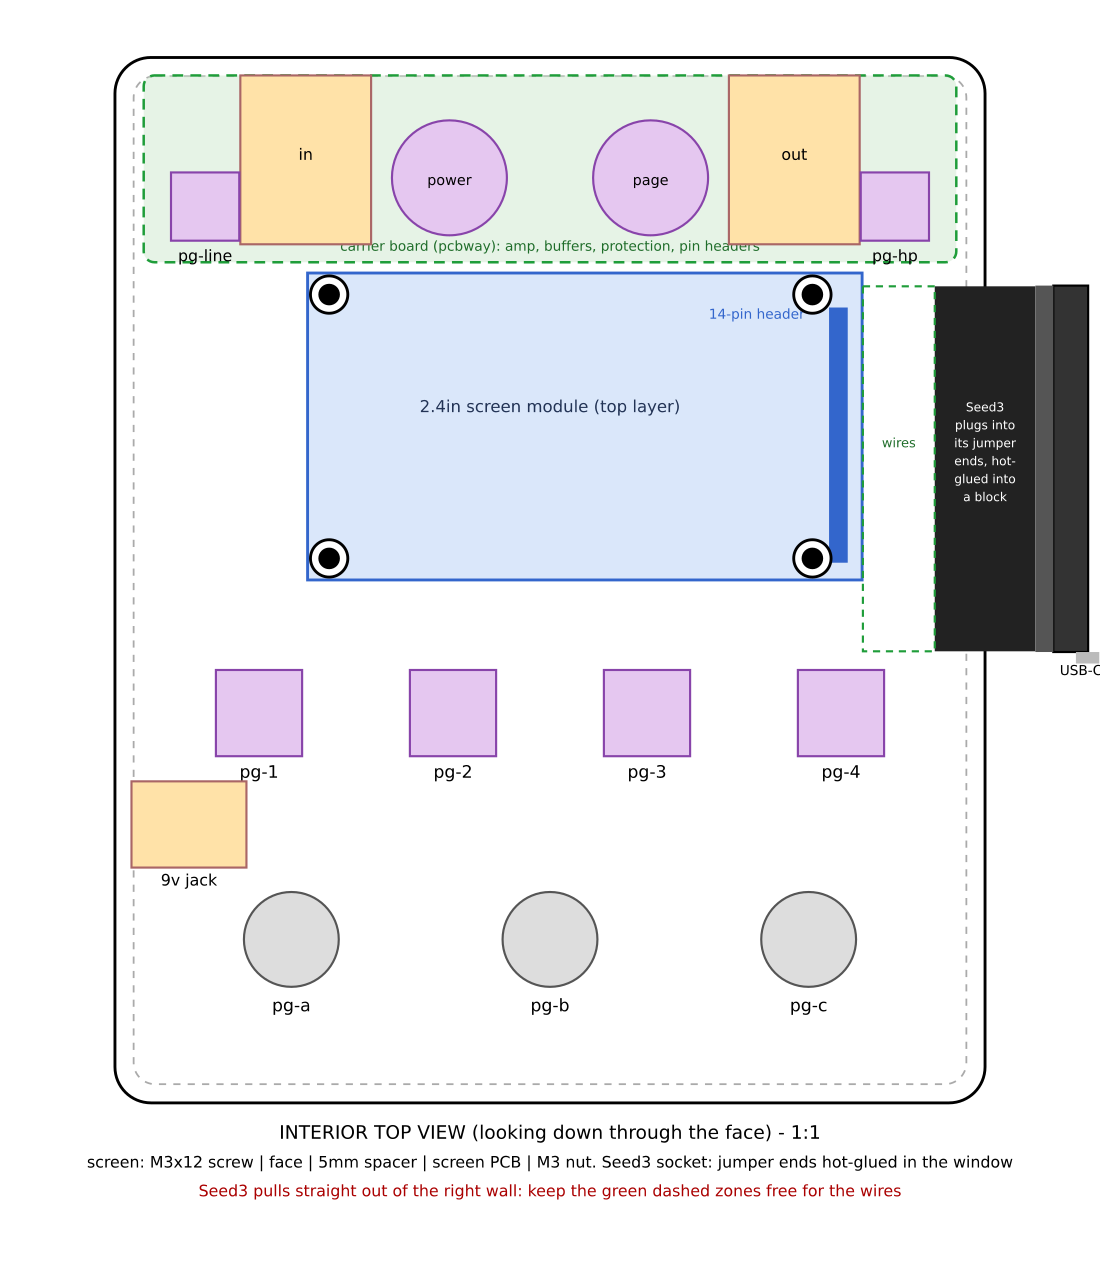
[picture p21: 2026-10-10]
PG-Pedal-1/05-Wiring-and-Schematics/interior-layout.png

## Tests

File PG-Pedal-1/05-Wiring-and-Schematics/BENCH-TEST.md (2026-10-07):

# Breadboard test (no box, no soldering)

Run the whole pedal on your desk first: Seed3, screen, 4 knobs, 3 footswitches, IN and OUT jacks. Same pin numbers as `WIRING.md`,
so the firmware is exactly the one the finished pedal uses. Nothing is soldered, so every part can go in the box later.

Extra parts (Tayda, `02-Parts-and-Cart/tayda-cart-benchtest.csv`): breadboard, female/male jumpers, male/male jumpers, 2 packs of alligator-clip jumpers.
Power comes from your computer's USB-C cable; the 9V jack isn't used on the bench. **Never plug in 9 V on the bench.**

## Layout
```
 breadboard rows 1-20                       the 2 long rails on each edge
   a b c [d] e  | gap |  f g [h] i j
          Seed3 pins 1-20 in column d (pin 1 at row 1),  pins 40-21 in column h (pin 40 at row 1)
          → USB-C end at row 1, hanging off the end of the board
```
- The Seed3 sits across the middle gap: one pin row in column **d**, the other in column **h**. Press it in evenly; it's stiff the first time.
- Every Seed3 pin then has free holes beside it in its own breadboard row (a, b, c on one side; i, j on the other). That's where its wire goes.
- **Rails:** one M/M jumper from pin 40's row to the left **–** rail = main ground. One from pin 20's row to the right **–** rail = audio ground.
  Keep the two grounds apart, like the two chains in the pedal.

## Wiring (wire list in `WIRING.md`)
- **Screen:** female/male jumpers, female end on the screen's pin, male end into the Seed3 pin's row. GND → left rail.
- **Encoders:** push each into its own spot lower on the breadboard (rows 30 and up). If the 2 push-switch legs don't line up, bend them gently.
  Male/male jumpers: A, B, push → their Seed3 rows. Middle pin C and the 2nd push leg → left rail.
- **Footswitches:** alligator clip on one lug → its Seed3 row (male end in the breadboard), clip on the other lug → left rail.
- **IN / OUT jacks:** clips on tip, ring and sleeve. Tip/ring → their Seed3 rows, sleeve → **right** rail (audio ground).
  Make sure no two clips touch each other. A bit of tape over a clip's jaws helps.

## Then
1. USB-C from the computer to the Seed3, flash the firmware (`06-Firmware-DaisySeed/README.md`).
2. The splash and tour should play. Turn and push every knob, press every footswitch, tap the screen.
3. Open the **health** tab: it says what it thinks is wrong (a knob that never moves = check that knob's 3 wires).
4. Sound: SC3 line out → ground loop isolator → IN jack, OUT jack → your headset, **volume low** at first.

When it all works, unclip one part at a time and build it into the box.

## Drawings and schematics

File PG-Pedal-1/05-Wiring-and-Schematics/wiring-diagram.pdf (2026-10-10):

# PG-1 COMPLETE WIRING: every part, every lug, every wire

Each wire has its own lane. At each end it says in words where its OTHER end goes. Black = ground. Grey lugs = leave empty. wiring-3d.pdf shows the same wires inside the box; WIRE-LIST.md is the tick list.

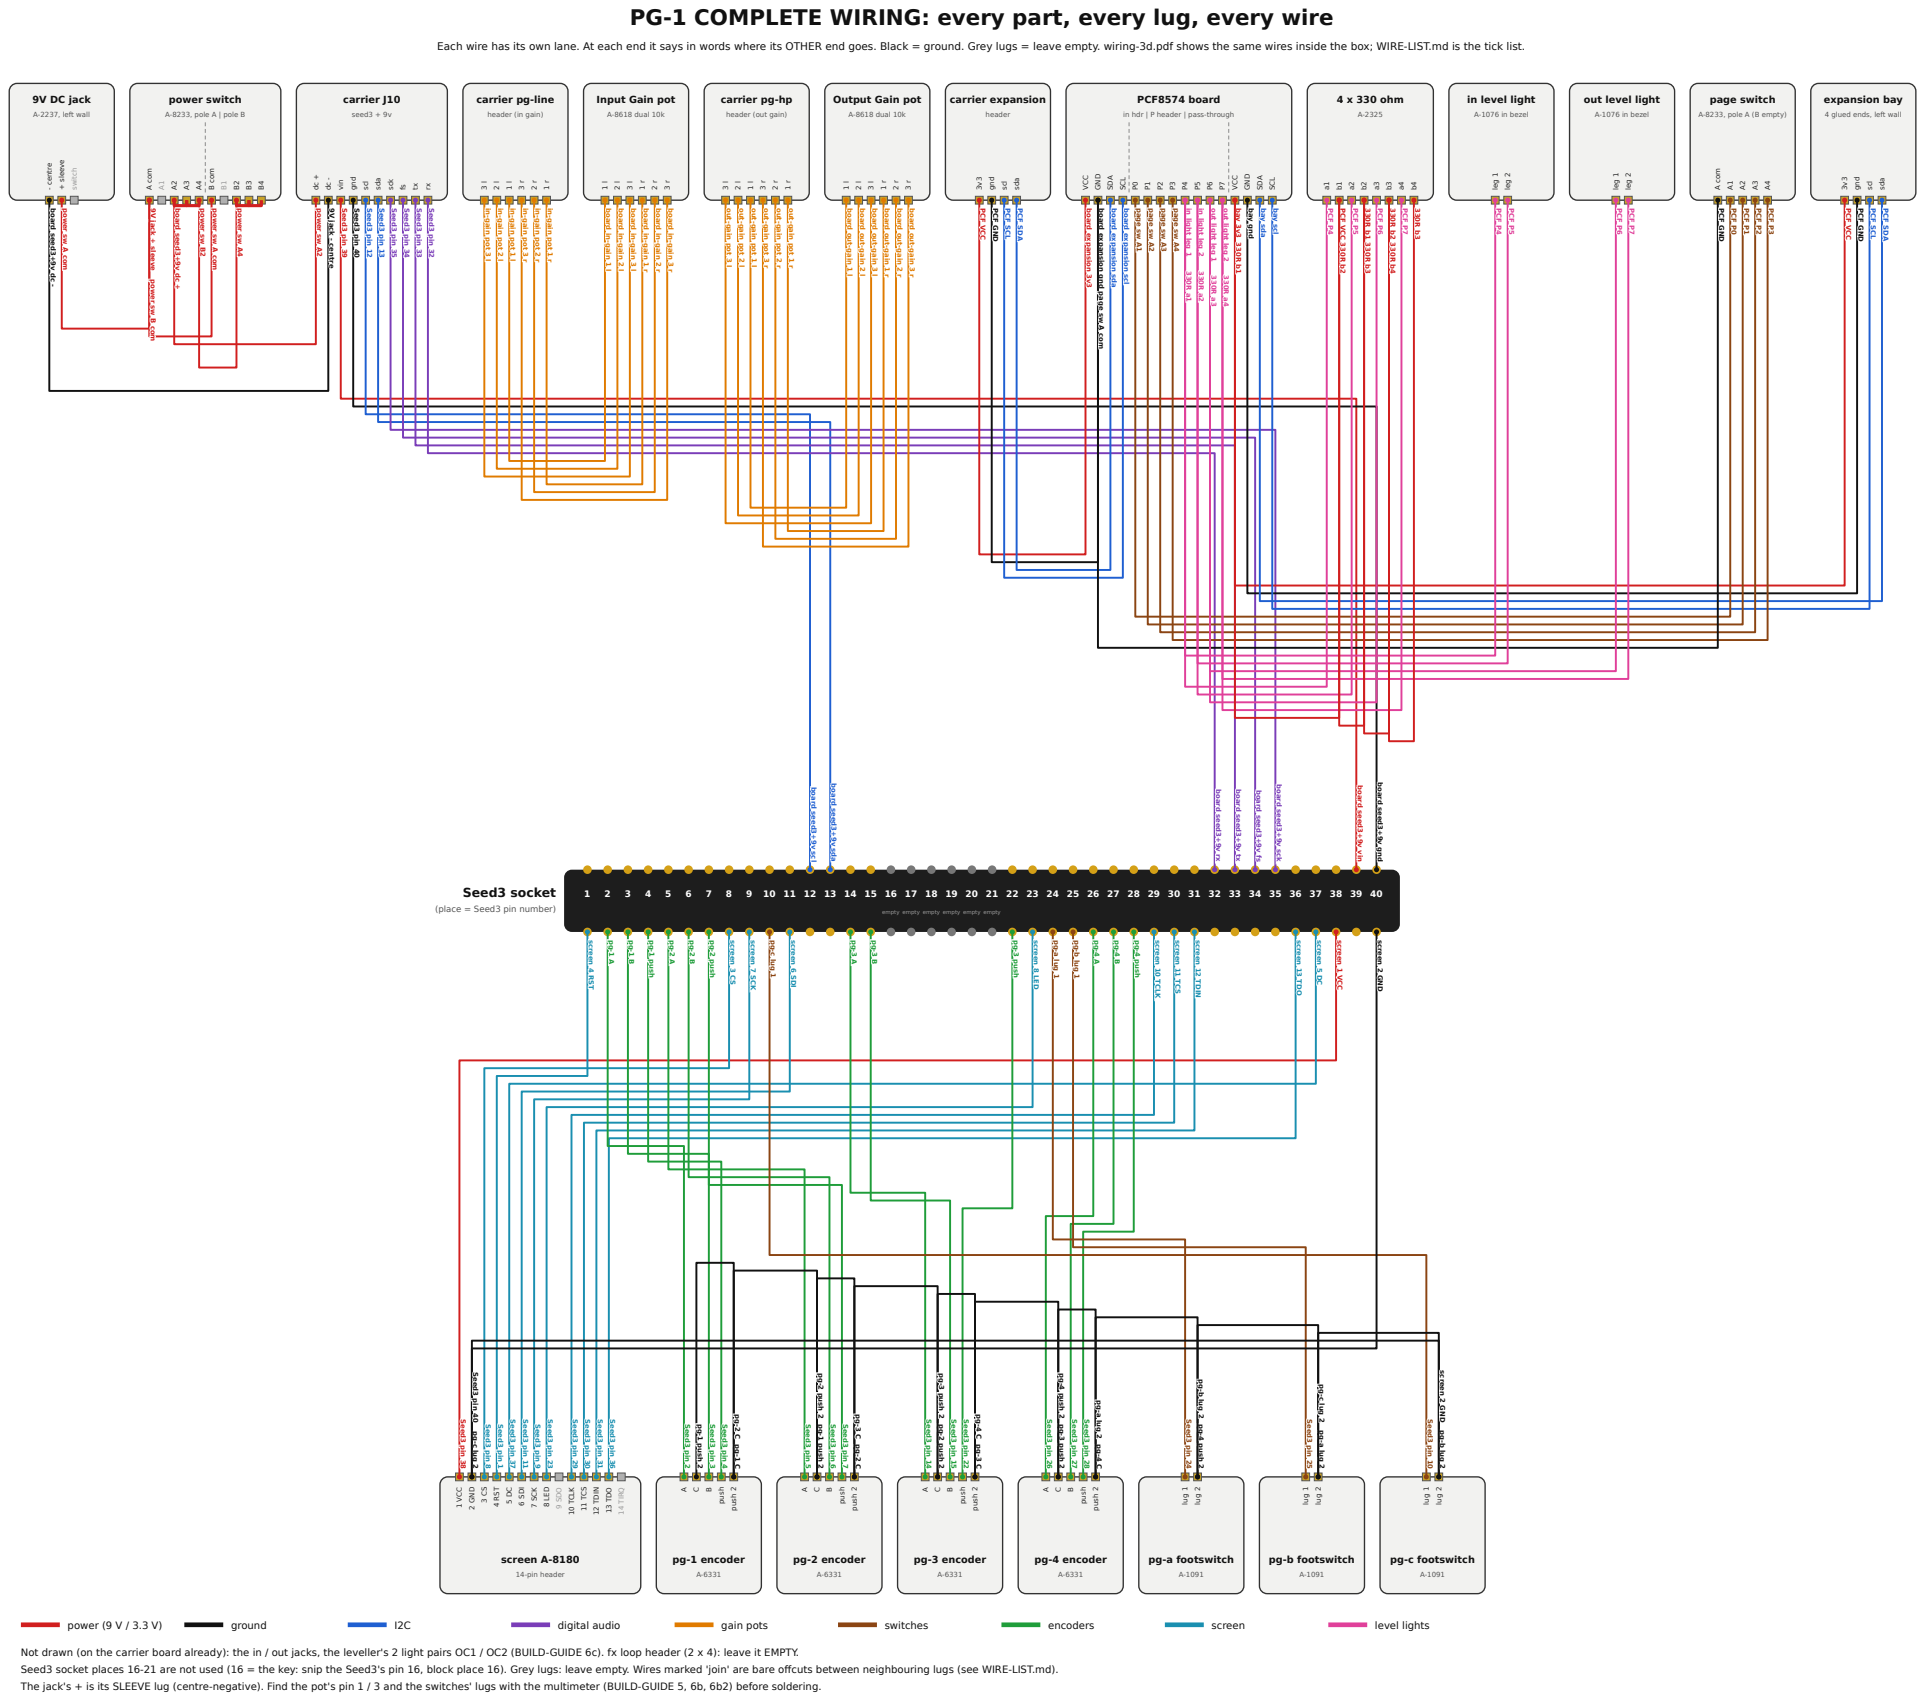
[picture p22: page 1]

in hdr | P header | pass-through

4 glued ends, left wall

9V jack + sleeve power sw B com

pg-1 push 2 pg-2 push 2

pg-2 push 2 pg-3 push 2

pg-3 push 2 pg-4 push 2

pg-4 push 2 pg-b lug 2

pg-b lug 2 screen 2 GND

pg-a lug 2 pg-c lug 2

Not drawn (on the carrier board already): the in / out jacks, the leveller's 2 light pairs OC1 / OC2 (BUILD-GUIDE 6c). fx loop header (2 x 4): leave it EMPTY.
Seed3 socket places 16-21 are not used (16 = the key: snip the Seed3's pin 16, block place 16). Grey lugs: leave empty. Wires marked 'join' are bare offcuts between neighbouring lugs (see WIRE-LIST.md).
The jack's + is its SLEEVE lug (centre-negative). Find the pot's pin 1 / 3 and the switches' lugs with the multimeter (BUILD-GUIDE 5, 6b, 6b2) before soldering.

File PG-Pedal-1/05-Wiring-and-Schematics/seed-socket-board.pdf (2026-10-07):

SEED3 SOCKET PLACES, seen from INSIDE the box (way 1 jumper block: same places; drawn: way 2 board). 4:1

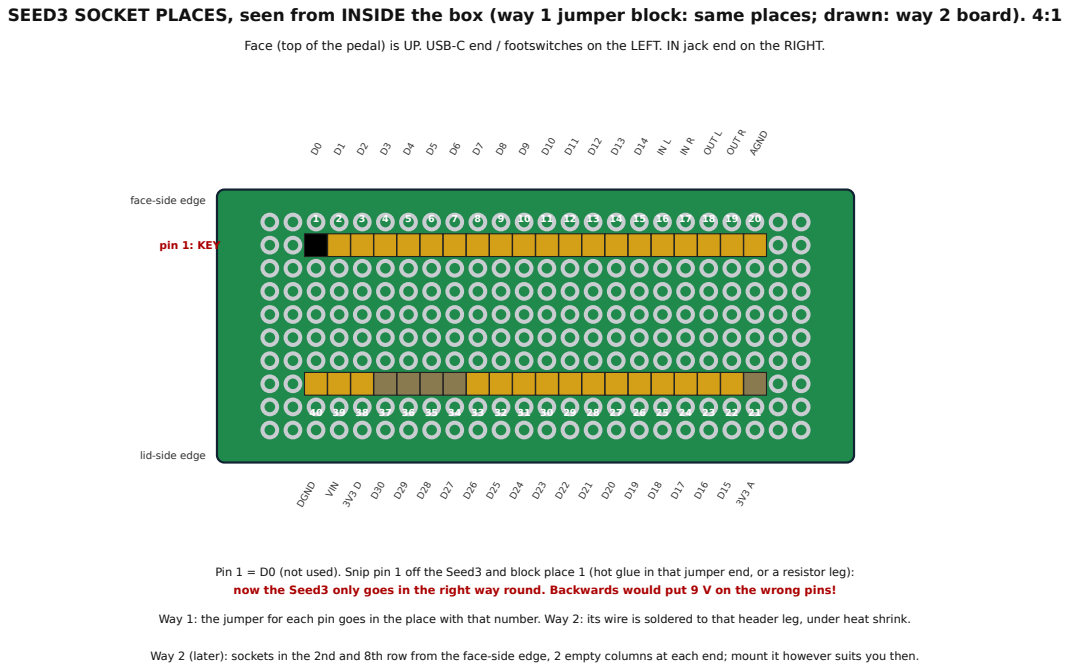
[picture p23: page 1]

Face (top of the pedal) is UP. USB-C end / footswitches on the LEFT. IN jack end on the RIGHT.

Pin 1 = D0 (not used). Snip pin 1 off the Seed3 and block place 1 (hot glue in that jumper end, or a resistor leg):
now the Seed3 only goes in the right way round. Backwards would put 9 V on the wrong pins!

Way 1: the jumper for each pin goes in the place with that number. Way 2: its wire is soldered to that header leg, under heat shrink.

Way 2 (later): sockets in the 2nd and 8th row from the face-side edge, 2 empty columns at each end; mount it however suits you then.

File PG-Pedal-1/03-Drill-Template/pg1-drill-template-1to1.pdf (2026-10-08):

## SIDE B (top edge, jacks) - centre = its own (0,0)

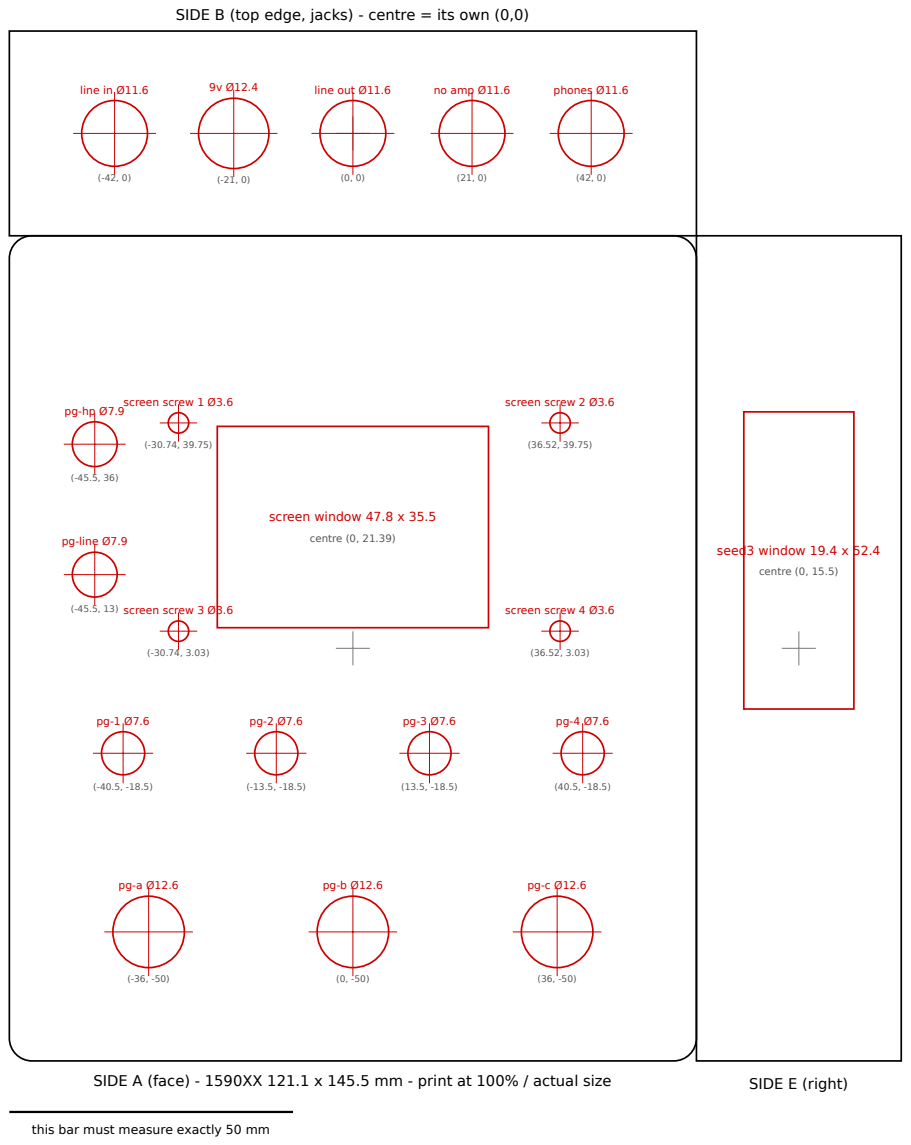
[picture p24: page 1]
SIDE A (face) - 1590XX 121.1 x 145.5 mm - print at 100% / actual size; SIDE E (right); pg-line Ø7.9; screen screw 1 Ø3.6; screen screw 2 Ø3.6; screen screw 3 Ø3.6; screen screw 4 Ø3.6; screen window 47.8 x 35.5; centre (0, 21.39); line in Ø11.6; line out Ø11.6; no amp Ø11.6; phones Ø11.6; seed3 window 19.4 x 52.4; centre (0, 15.5)

this bar must measure exactly 50 mm

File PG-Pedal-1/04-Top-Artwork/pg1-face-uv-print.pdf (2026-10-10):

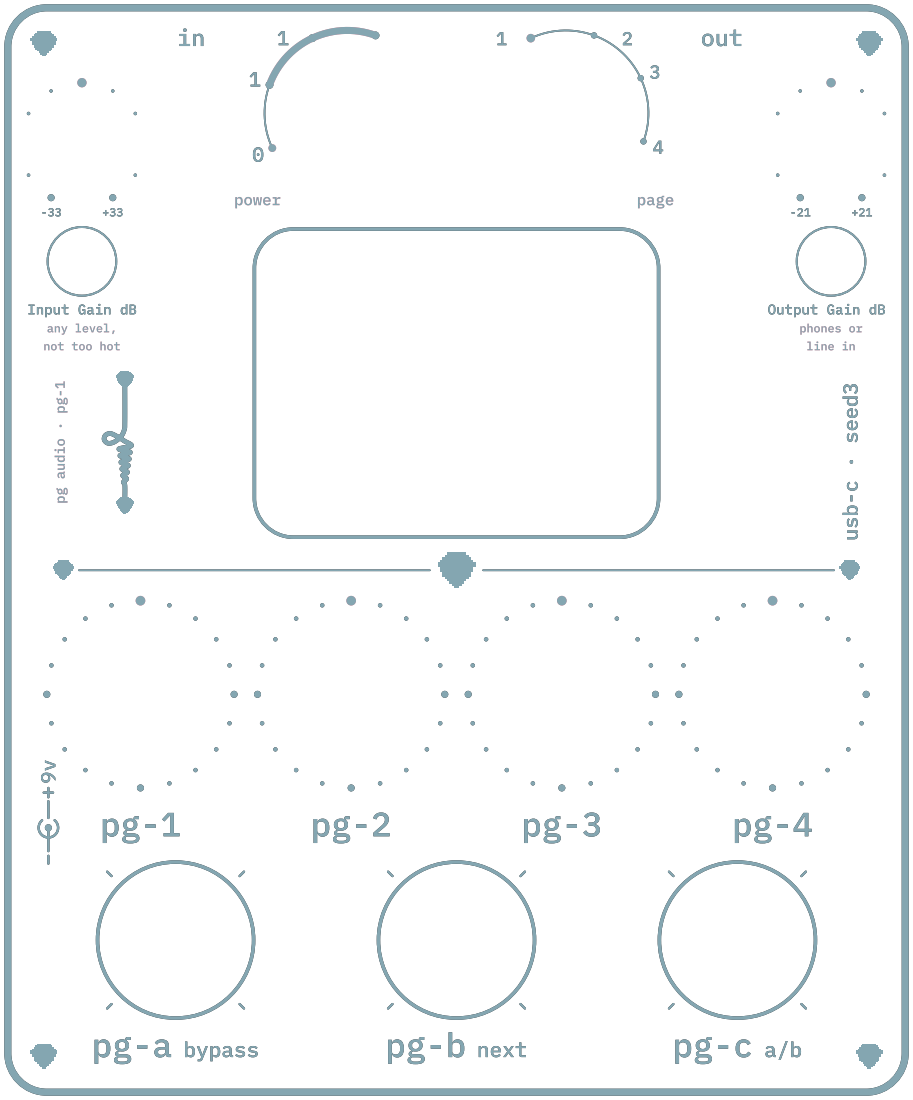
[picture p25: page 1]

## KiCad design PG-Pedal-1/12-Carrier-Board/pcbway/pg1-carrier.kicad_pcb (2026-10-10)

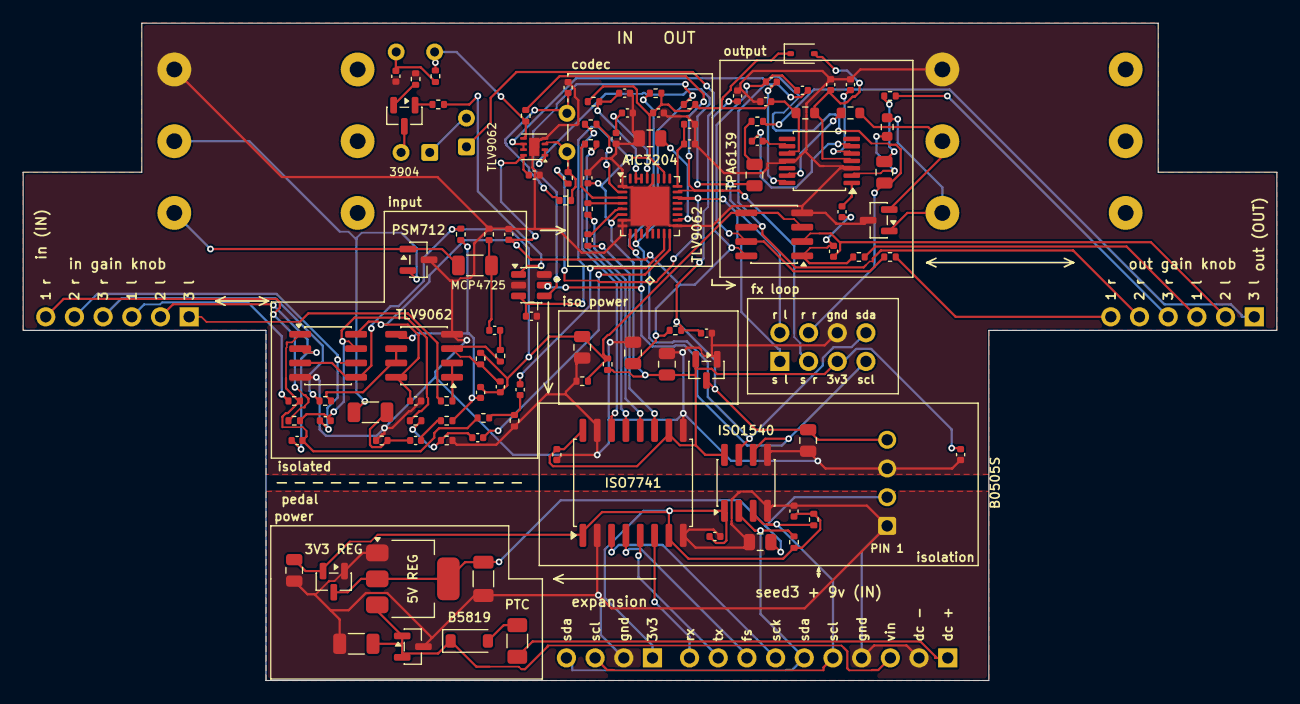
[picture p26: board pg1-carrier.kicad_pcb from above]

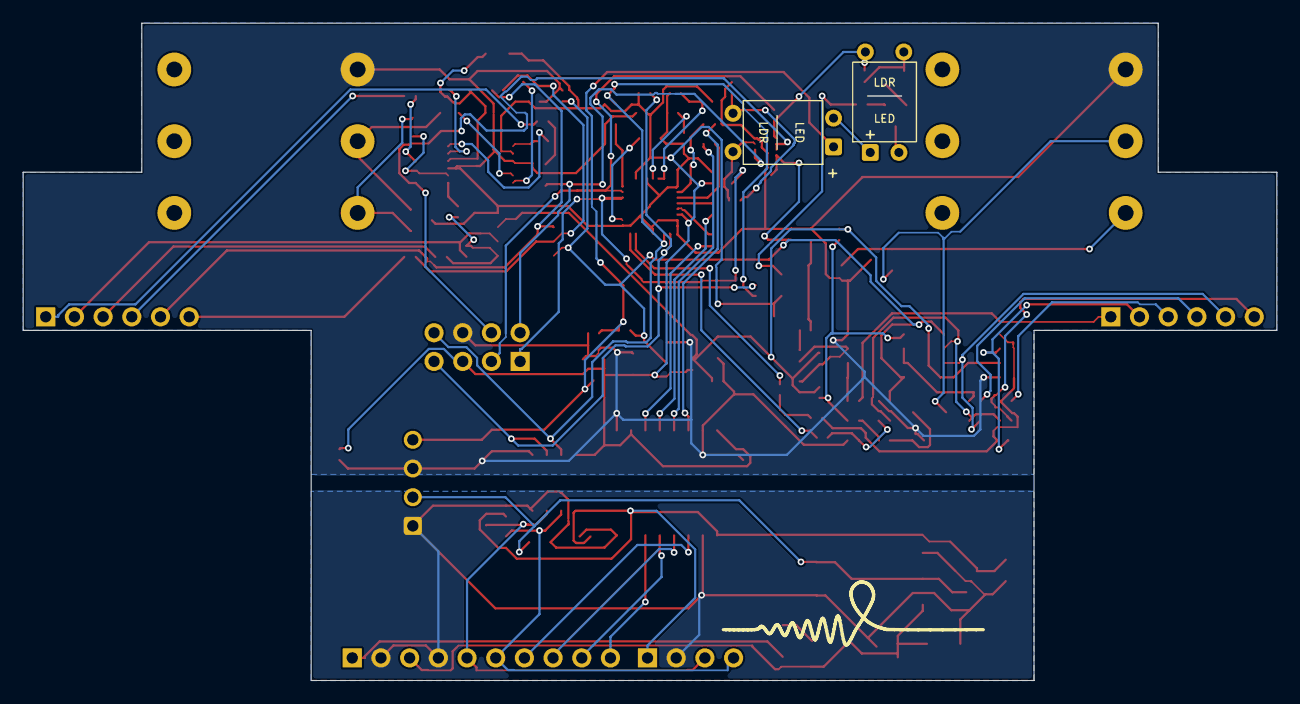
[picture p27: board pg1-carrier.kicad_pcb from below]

Board: 2 copper layers, 111.0 x 58.2 mm, 116 parts (2 on the bottom side), 86 nets.

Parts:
C1, C2: 22uF 25V; C_1206_3216Metric
C3, C14, C50, C60: 4.7uF; C_0805_2012Metric
C7, C8, C16, C17, C18: 10uF 25V; C_0805_2012Metric
C9, C10, C11, C12, C20, C22, C24, C25, C26, C27, C28, C30, C40, C82, C83: 100nF; C_0402_1005Metric
C15, C19, C21, C23, C32, C42, C51, C61, C70, C71, C72, C73: 1uF; C_0402_1005Metric
C31, C33, C41, C43, C52, C62: 100pF C0G; C_0402_1005Metric
C80, C85: 10uF; C_0402_1005Metric
D1: B5819W; D_SOD-123
D2, D61, D62: PSM712; SOT-23
D63: 1N4148WS; D_SOD-323
F1: PTC 300mA; Fuse_1206_3216Metric
J1: in; Jack_6.35mm_Neutrik_NMJ6HFD2_Horizontal
J2: out; Jack_6.35mm_Neutrik_NMJ6HFD2_Horizontal
J10: seed3 + 9v; PinHeader_1x10_P2.54mm_Horizontal
J19: pg-hp; PinHeader_1x06_P2.54mm_Horizontal
J20: pg-line; PinHeader_1x06_P2.54mm_Horizontal
J21: expansion; PinHeader_1x04_P2.54mm_Horizontal
J22: fx loop; PinHeader_2x04_P2.54mm_Vertical
OC1, OC2: LED+LDR; OPTO_PAIR_LED3_LDR5
Q1: MMBT3904; SOT-23
R3, R4, R9, R10, R80, R85: 4.7k; R_0402_1005Metric
R5: 10; R_0402_1005Metric
R6: 3.3k; R_0402_1005Metric
R7, R8, R35, R45: 10k; R_0402_1005Metric
R11, R12, R13, R14: 33; R_0402_1005Metric
R30, R40: 1k; R_1206_3216Metric
R31, R32, R41, R42: 1M; R_0402_1005Metric
R33, R43: 470k; R_0402_1005Metric
R34, R44: 20k; R_0402_1005Metric
R36, R37, R46, R47: 220; R_0402_1005Metric
R50, R60: 47; R_0603_1608Metric
R51, R52, R61, R62, R82: 1k; R_0402_1005Metric
R70: 1M; R_0603_1608Metric
R81, R86: 100k; R_0402_1005Metric
R83: 100; R_0402_1005Metric
U1: AMS1117-5.0; SOT-223-3_TabPin2
U2, U7: XC6206P332MR; SOT-23
U3: B0505S-1WR3; DCDC_SIP4_B0505S
U4: ISO7741; SOIC-16W_7.5x10.3mm_P1.27mm
U5: ISO1540; SOIC-8_3.9x4.9mm_P1.27mm
U8, U11, U12: TLV9062; SOIC-8_3.9x4.9mm_P1.27mm
U9: TLV320AIC3204; Texas_RHB0032E_VQFN-32-1EP_5x5mm_P0.5mm_EP3.45x3.45mm
U10: TPA6139A2; TSSOP-14_4.4x5mm_P0.65mm
U15: MCP4725; SOT-23-6
U16: TLV9062; Texas_DSG0008A_WSON-8-1EP_2x2mm_P0.5mm_EP0.9x1.6mm

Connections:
+3V3: C3.1, C9.1, C11.1, J21.1, R3.1, R4.1, U2.2, U4.1, U4.7, U5.1
+5V: C2.1, C7.1, U1.2, U2.3, U3.2
+9V: C1.1, D1.1, D2.1, D2.2, J10.3, U1.3
+9V_F: D1.2, F1.2
+9V_RAW: F1.1, J10.1
AVDD: C19.1, C20.1, U9.24
BCLK: R11.2, U9.2
BCLK_X: R11.1, U4.14
CIN2_L: C32.2, U9.15
CIN2_R: C42.2, U9.16
CRESET: C25.1, R8.2, U9.30, U9.31
DIN: R13.2, U9.4
DIN_X: R13.1, U4.12
DOUT: R14.1, U9.5
DOUT_X: R14.2, U4.11
DVDD: C21.1, C22.1, U9.29
FXR_L: C50.1, J22.2, U16.1, U16.2
FXR_R: C60.1, J22.4, U16.6, U16.7
GIN_A_L: J20.1, R36.2
GIN_A_R: J20.4, R46.2
GIN_B_L: J20.3, R37.1
GIN_B_R: J20.6, R47.1
GIN_W_L: C33.1, J20.2, U11.2
GIN_W_R: C43.1, J20.5, U11.6
GND: C1.2, C2.2, C3.2, C7.2, C9.2, C11.2, D2.3, J10.2, J10.4, J21.2, U1.1, U2.1, U3.1, U4.2, U4.8, U5.4
GOUT_A_L: J19.1, R51.2
GOUT_A_R: J19.4, R61.2
GOUT_B_L: J19.3, R52.1
GOUT_B_R: J19.6, R62.1
GOUT_W_L: C52.1, J19.2, U12.2
GOUT_W_R: C62.1, J19.5, U12.6
HPIN_L: C51.2, U10.1
HPIN_R: C61.2, U10.14
HPO_L: R50.1, U10.2
HPO_R: R60.1, U10.13
HP_CN: C70.2, U10.6
HP_CP: C70.1, U10.9
HP_ON: C73.1, D63.2, R70.2, U10.4
HP_VSS: C71.2, U10.5
IBIAS: C17.1, C31.2, C41.2, R6.2, R7.1, R33.2, R43.2, U11.3, U11.5, U12.3, U12.5
IGND: C8.2, C10.2, C12.2, C14.2, C15.2, C16.2, C17.2, C18.2, C19.2, C20.2, C21.2, C22.2, C23.2, C24.2, C25.2, C26.2, C27.2, C28.2, C71.1, C72.2, C73.2, C80.2, C82.2, C83.2, C85.2, D61.3, D62.3, J1.S, J2.S, J22.6, R7.2, R31.2, R35.2, R41.2, R45.2, R83.2, U3.3, U4.9, U4.15, U5.5, U7.1, U8.4, U9.1, U9.7, U9.8, U9.12, U9.17, U9.28, U9.33, U10.3, U10.11, U11.4, U12.4, U15.2, U15.6, U16.4, U16.9
IN_A_L: C30.1, R30.2, R31.1
IN_A_R: C40.1, R40.2, R41.1
IN_B_L: C30.2, R32.1
IN_B_R: C40.2, R42.1
IN_C_L: C31.1, R32.2, R33.1, U8.3
IN_C_R: C41.1, R42.2, R43.1, U8.5
IN_D_L: R36.1, U8.1, U8.2
IN_D_R: R46.1, U8.6, U8.7
IN_E_L: C32.1, R34.2, R35.1
IN_E_R: C42.1, R44.2, R45.1
IN_G_L: C33.2, R34.1, R37.2, U11.1
IN_G_R: C43.2, R44.1, R47.2, U11.7
ISCL: J22.7, R9.2, U5.6, U9.9, U15.5
ISDA: J22.8, R10.2, U5.7, U9.10, U15.4
ISO3V3: C10.1, C12.1, C14.1, C23.1, C24.1, C72.1, C82.1, D63.1, J22.5, R6.1, R8.1, R9.1, R10.1, R70.1, U4.10, U4.16, U5.8, U7.2, U9.6, U9.26, U10.10, U15.3
ISO5V: C16.1, C26.1, C27.1, C28.1, C83.1, R5.2, U8.8, U11.8, U12.8, U16.8
ISO5V_RAW: C8.1, C15.1, OC1.1, R5.1, U3.4, U7.3
JIN_L: D61.1, J1.T, R30.1
JIN_R: D61.2, J1.R, R40.1
JOUT_L: D62.1, J2.T, R50.2
JOUT_R: D62.2, J2.R, R60.2
LED_B: Q1.1, R82.2
LED_C: OC2.2, Q1.3
LED_DAC: R82.1, U15.1
LED_E: Q1.2, R83.1
LED_M: OC1.2, OC2.1
LO_L: J22.1, R80.1, U9.22
LO_R: J22.3, R85.1, U9.23
LVA_L: OC1.3, R80.2, R81.1, U16.3
LVA_R: OC2.3, R85.2, R86.1, U16.5
LVC_L: C80.1, OC1.4, R81.2
LVC_R: C85.1, OC2.4, R86.2
OUT_A_L: C50.2, R51.1
OUT_A_R: C60.2, R61.1
OUT_G_L: C51.1, C52.2, R52.2, U12.1
OUT_G_R: C61.1, C62.2, R62.2, U12.7
REF: C18.1, U9.18
SEED_FS: J10.8, U4.4
SEED_RX: J10.10, U4.6
SEED_SCK: J10.7, U4.3
SEED_SCL: J10.5, J21.3, R3.2, U5.3
SEED_SDA: J10.6, J21.4, R4.2, U5.2
SEED_TX: J10.9, U4.5
WCLK: R12.2, U9.3
WCLK_X: R12.1, U4.13

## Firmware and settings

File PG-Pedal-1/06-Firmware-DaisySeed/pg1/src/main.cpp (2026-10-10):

// PG-1 firmware for the pg audio PG pedal (Daisy Seed3, libDaisy v9+).
//
// This file is only the hardware: it reads the knobs, footswitches and touchscreen, feeds the
// audio, and draws on the ILI9341. Everything the pedal *does* (parameters, pages, pop-ups,
// gestures, DSP) is in core/PgCore - the same code the Carla plugin (10-Carla-Plugin) runs.
//
// Controls (details in ../README.md):
//   home: 8 tabs (hum, dyn eq, comp, clarity, saturate, de-harsh, safety, visual). turn = move, push / tap = open
//   page: the 4 knobs = the 4 boxes; double-push = default; long-push = home; push = what does it do
//   fs-1 = bypass (safety stays on); fs-2 = next band (eq) / next page; hold fs-2 = this stage on / off
//   fs-3 = fair A/B: the untouched input at the same loudness (tap again to come back)
//   fs-1 + fs-2 held 2 s = USB flash mode
//
// Pin map matches 05-Wiring-and-Schematics/WIRING.md. Change it in ONE place: the pins block.
#include "daisy_seed.h"
#include "ili9341.h"
#include "isoaudio.h"
#include "../core/PgCore.h"
#include "util/PersistentStorage.h"
#include <cmath>
#include <cstring>

using namespace daisy;

extern "C" uint32_t HAL_GetUIDw0(void), HAL_GetUIDw1(void), HAL_GetUIDw2(void); // the chip's unique serial

// ------------------------------------------------------------------ pins
namespace pins
{
constexpr Pin kPg1A = seed::D1, kPg1B = seed::D2, kPg1Sw = seed::D3;
constexpr Pin kPg2A = seed::D4, kPg2B = seed::D5, kPg2Sw = seed::D6;
constexpr Pin kPg3A = seed::D13, kPg3B = seed::D14, kPg3Sw = seed::D15;
constexpr Pin kPg4A = seed::D19, kPg4B = seed::D20, kPg4Sw = seed::D21;
constexpr Pin kFs1 = seed::D17, kFs2 = seed::D18, kFs3 = seed::D9;
constexpr Pin kLcdCs = seed::D7, kLcdSck = seed::D8, kLcdMosi = seed::D10;
constexpr Pin kLcdDc = seed::D30, kLcdRst = seed::D0, kLcdLed = seed::D16;
// XPT2046 touch (screen pins 10-13), bit-banged so it never fights the screen's SPI; polled (no IRQ wire)
constexpr Pin kTClk = seed::D22, kTCs = seed::D23, kTDin = seed::D24, kTDout = seed::D29;
// v3 carrier board: I2C1 (codec through the ISO1540 + the knob ADC) and SAI2 (I2S through the ISO7741)
constexpr Pin kScl = seed::D11, kSda = seed::D12;
constexpr Pin kSaiFs = seed::D27, kSaiSck = seed::D28, kSaiTx = seed::D26, kSaiRx = seed::D25, kSaiMclk = seed::D24;
} // namespace pins

constexpr bool kFlipScreen     = false; // set true if the picture is upside down
constexpr bool kSwapLightColours = false; // set true if the level lights show red for signal and green when hot
constexpr bool kReverseEncoder = false; // set true if turning right makes values go down
// Touch calibration: raw 0-4095 readings at the screen edges. If taps land in the wrong place,
// flip these (swap first, then the flips) until the bar follows your finger.
constexpr bool kTouchSwapXY = true, kTouchFlipX = false, kTouchFlipY = false;
constexpr int  kTouchRawMin = 300, kTouchRawMax = 3800;
constexpr int  kTouchZMin   = 150; // pressure (Z1) above this = a finger is down

// ------------------------------------------------------------------ levels (v3 isolated carrier board)
// The core works in "pedal units": 1.0 = 2.0 V peak at a jack, in and out. Path sensitivity from the board:
//   in:  jack x0.5 (1M / 1M) -> buffer -> pg-line stage (x1 at its centre click, and it inverts) -> x1/3 (20k / 10k)
//        -> codec IN2 through 20k (-6 dB) -> ADC (0 dBFS = 0.707 V peak at 10k): ADC = -V_jack * 0.118
//   out: DAC 0 dBFS -> about 1.41 V peak on the line outputs -> pg-hp stage (x1 at its centre click, inverting) ->
//        TPA6139A2 x-2: out jack = DAC * 2.82 V peak
// So with both knobs on their centre clicks, what comes out is as loud as what went in, processed. The firmware's two
// gains below are FIXED (no auto-ranging): measure once on the real board and correct them here if needed.
// ADC -> pedal units (1.0 = 2 V peak at the jack); the minus undoes the inversion. 0.0807 = codec volts per jack volt
// at pg-line's centre click, from the board simulation (10-Carla-Plugin/Source/sim): bias 2.48 V (R6 3.3k), input divider
// 1M / 470k, 20k / 10k to the codec (the input clamp: the codec pin stays inside its safe window, ngspice-checked).
constexpr float kInGain  = -1.f / (2.0f * 0.0807f);
// pedal units -> DAC, for unity through pg-hp (x1) and the TPA (x2); x1.046 = +0.39 dB for the analog leveller's
// 4.7k into the 100k across each LDR (simulated on the routed board)
constexpr float kOutGain = 2.0f / (2.0f * 1.41f) * 1.046f;

DaisySeed hw;
Encoder   enc[pg::kKnobs];
Switch    fs[3];
Ili9341   lcd;
pg::Core  core;
I2CHandle    i2c;
pg::IsoCodec codec;
pg::AnalogFx afx; // the board's analog level + filter (unity / open unless the DSP asks)

// The page selector + the face's 4 level lights, on a PCF8574 I/O board on the expansion header (Seed3 I2C, 12/13).
// Switch position k (1..4) -> PCF8574 pin P(k-1), the switch's common -> GND; the PCF8574's own pull-ups hold the
// others high, so the selected position reads low. P4..P7 drive the 2 level lights: each is a 2-leg red/green LED
// between 2 pins (in: P4-P5, out: P6-P7), each pin pulled up to 3.3 V by 330 ohm. Pulling one pin low lights one
// colour, the other pin the other colour; both high = off. Any of its 16 addresses is found by itself.
struct PageSelectorIn
{
    uint8_t addr = 0, last = 0xFF, sent = 0xFF;
    int     pos  = 0;
    // the lights (bits: 0 in signal, 1 in hot, 2 out signal, 3 out hot): off / green / red per side.
    // P0..P3 are always written 1 so they stay inputs
    void Lights(I2CHandle& bus, uint8_t on)
    {
        uint8_t b = 0xFF;
        for(int side = 0; side < 2; side++)
        {
            const bool sig = on & (1u << (2 * side)), hot = on & (2u << (2 * side));
            if(hot || sig) // pull one leg low: green on the first pin, red on the second (kSwapLightColours flips)
                b &= uint8_t(~(1u << (4 + 2 * side + ((hot != kSwapLightColours) ? 1 : 0))));
        }
        if(addr && b != sent && bus.TransmitBlocking(addr, const_cast<uint8_t*>(&b), 1, 2) == I2CHandle::Result::OK)
            sent = b;
    }
    void    Find(I2CHandle& bus)
    {
        for(uint8_t a : {0x20, 0x21, 0x22, 0x23, 0x24, 0x25, 0x26, 0x27, 0x38, 0x39, 0x3A, 0x3B, 0x3C, 0x3D, 0x3E, 0x3F})
        {
            uint8_t all_in = 0xFF; // writing 1s makes every pin an input (with its weak pull-up)
            if(bus.TransmitBlocking(a, &all_in, 1, 2) == I2CHandle::Result::OK)
            {
                addr = a;
                return;
            }
        }
    }
    // the switch position 1..4, 0 while between positions / nothing fitted
    int Read(I2CHandle& bus)
    {
        if(!addr)
            return 0;
        uint8_t v = 0xFF;
        if(bus.ReceiveBlocking(addr, &v, 1, 2) != I2CHandle::Result::OK)
            return pos;
        const uint8_t low = uint8_t(~v) & 0x0F; // (P4..P7 are the lights)
        if(v == last && low && !(low & (low - 1))) // exactly one pin low, the same twice in a row: settled
        {
            int k = 0;
            while(!(low & (1u << k)))
                k++;
            pos = k + 1;
        }
        last = v;
        return pos;
    }
};
PageSelectorIn page_sel;
pg::AnalogLeveller leveller;          // the analog leveller on the carrier board (U15 DAC -> LEDs -> LDRs)
static volatile float out_ms = 0.f, out_peak = 0.f; // what's leaving (DAC units): mean square, for the leveller; peak
// set by the main loop, used by the audio callback
static volatile float g_in = kInGain, g_out = 0.f, in_peak = 0.f; // g_out stays 0 (silent) until the codec is up
// the screen picture the core draws into: 150 KB, in the Seed3's 64 MB SDRAM (plain array, no
// constructor, so it is safe to place there; SDRAM is ready after hw.Init())
static uint16_t DSY_SDRAM_BSS framebuffer[pg::Canvas::kW * pg::Canvas::kH];

// Everything the pedal remembers over power-off (settings, the 8 configs, the learned hum / hiss), as one
// block in the QSPI flash at 7 MB - well clear of the program, which the bootloader keeps near the start.
struct StateBlob
{
    uint8_t data[pg::Core::kStateBytes];
    bool    operator!=(const StateBlob& o) const { return memcmp(data, o.data, sizeof(data)) != 0; }
    bool    operator==(const StateBlob& o) const { return !(*this != o); }
};
constexpr uint32_t                 kStateOffset = 0x700000;
static PersistentStorage<StateBlob> storage(hw.qspi);
static StateBlob                    blob;

// Runs at 1 kHz (48 samples per block at 48 kHz): controls + audio.
void AudioCallback(AudioHandle::InputBuffer in, AudioHandle::OutputBuffer out, size_t size)
{
    const uint32_t now = System::GetNow(), t0 = System::GetUs();
    for(int i = 0; i < pg::kKnobs; i++)
    {
        enc[i].Debounce();
        if(enc[i].RisingEdge())
            core.KnobPress(i, true, now);
        const int inc = enc[i].Increment();
        core.KnobTurn(i, kReverseEncoder ? -inc : inc, now);
        if(enc[i].FallingEdge())
            core.KnobPress(i, false, now);
    }
    for(int i = 0; i < 3; i++)
    {
        fs[i].Debounce();
        if(fs[i].RisingEdge())
            core.Footswitch(i, true, now);
        if(fs[i].FallingEdge())
            core.Footswitch(i, false, now);
    }
    // in: the codec's raw samples -> pedal units (the range and the input-gain knob are undone / applied here)
    static float  ibuf[2][48];
    const float   gi = g_in;
    float         pk = 0.f;
    const size_t  n  = size > 48 ? 48 : size;
    for(size_t c = 0; c < 2; c++)
        for(size_t i = 0; i < n; i++)
        {
            const float x = in[c][i];
            pk            = fabsf(x) > pk ? fabsf(x) : pk;
            ibuf[c][i]    = x * gi;
        }
    if(pk > in_peak)
        in_peak = pk;
    const float* ip[2] = {ibuf[0], ibuf[1]};
    core.Process(ip, out, n, now);
    // out: pedal units -> DAC, with the output-level knob; glided per block (no zipper), never past full scale
    static float go = 0.f;
    const float  gt = g_out, g0 = go;
    go += (gt - go) * 0.2f;
    for(size_t c = 0; c < 2; c++)
        for(size_t i = 0; i < n; i++)
        {
            const float y = out[c][i] * (g0 + (go - g0) * float(i) / float(n));
            out[c][i]     = y > 1.f ? 1.f : (y < -1.f ? -1.f : y);
        }
    float ms = 0.f; // what's leaving, for the analog leveller (one cheap pass)
    for(size_t i = 0; i < n; i++)
        ms += 0.5f * (out[0][i] * out[0][i] + out[1][i] * out[1][i]);
    out_ms = out_ms + (ms / float(n) - out_ms) * 0.05f;
    float op = 0.f;
    for(size_t c = 0; c < 2; c++)
        for(size_t i = 0; i < n; i++)
            op = fabsf(out[c][i]) > op ? fabsf(out[c][i]) : op;
    if(op > out_peak)
        out_peak = op;
    // health: how much of the block's time the work took (1.0 = none left)
    core.ReportLoad(float(System::GetUs() - t0) * hw.AudioSampleRate() / (1e6f * float(size)));
}

// ------------------------------------------------------------------ watchdog
// The STM32's independent watchdog runs on its own clock: if the firmware ever hangs, it resets the Seed3 in ~2 s.
// (The output is safe meanwhile: the codec mutes itself when the digital audio stops, and pg-hp is analog.)
static void WatchdogStart()
{
    IWDG1->KR  = 0xCCCC; // start
    IWDG1->KR  = 0x5555; // unlock the settings
    IWDG1->PR  = 4;      // 32 kHz / 64 = 2 ms per count
    IWDG1->RLR = 1000;   // 2 s
    while(IWDG1->SR) {}
    IWDG1->KR = 0xAAAA;
}
static inline void WatchdogKick() { IWDG1->KR = 0xAAAA; }

// ------------------------------------------------------------------ touch (XPT2046)
GPIO t_clk, t_cs, t_din, t_dout;

void TouchInit()
{
    t_clk.Init(pins::kTClk, GPIO::Mode::OUTPUT);
    t_cs.Init(pins::kTCs, GPIO::Mode::OUTPUT);
    t_din.Init(pins::kTDin, GPIO::Mode::OUTPUT);
    t_dout.Init(pins::kTDout, GPIO::Mode::INPUT);
    t_cs.Write(true);
    t_clk.Write(false);
}

uint8_t TouchXfer(uint8_t out)
{
    uint8_t in = 0;
    for(int b = 7; b >= 0; b--)
    {
        t_din.Write((out >> b) & 1);
        System::DelayUs(1);
        t_clk.Write(true); // controller max ~2.5 MHz; ~500 kHz here
        System::DelayUs(1);
        in = uint8_t((in << 1) | (t_dout.Read() ? 1 : 0));
        t_clk.Write(false);
    }
    return in;
}

int TouchRaw(uint8_t cmd)
{
    int sum = 0;
    for(int i = 0; i < 4; i++)
    {
        t_cs.Write(false);
        TouchXfer(cmd);
        const int hi = TouchXfer(0), lo = TouchXfer(0);
        t_cs.Write(true);
        sum += ((hi << 8) | lo) >> 3;
    }
    return sum / 4;
}

// Returns true while touched, with screen pixel coordinates.
bool TouchRead(int& x, int& y)
{
    if(TouchRaw(0xB0) < kTouchZMin) // pressure (Z1): no finger
        return false;
    int a = TouchRaw(0xD0), b = TouchRaw(0x90); // 12-bit X and Y channels
    if(TouchRaw(0xB0) < kTouchZMin)
        return false; // released while reading
    if(kTouchSwapXY)
    {
        const int t = a;
        a           = b;
        b           = t;
    }
    auto map = [](int raw, int size, bool flip) {
        int v = (raw - kTouchRawMin) * size / (kTouchRawMax - kTouchRawMin);
        v     = v < 0 ? 0 : (v >= size ? size - 1 : v);
        return flip ? size - 1 - v : v;
    };
    x = map(a, pg::Canvas::kW, kTouchFlipX);
    y = map(b, pg::Canvas::kH, kTouchFlipY);
    return true;
}

int main(void)
{
    hw.Init(true); // 480 MHz: more room for the DSP, and a 192 MHz PLL1Q for the screen link
    {   // the screen's SPI from PLL1Q (192 MHz) instead of libDaisy's 25 MHz PLL2P, so it can run at 48 MHz
        RCC_PeriphCLKInitTypeDef pc = {};
        pc.PeriphClockSelection     = RCC_PERIPHCLK_SPI123;
        pc.Spi123ClockSelection     = RCC_SPI123CLKSOURCE_PLL;
        HAL_RCCEx_PeriphCLKConfig(&pc);
    }
    // audio: SAI2 (I2S to the isolated codec), 48 kHz, 48-sample blocks. The Seed3's own codec (SAI1) isn't used.
    {
        SaiHandle::Config sc;
        sc.periph          = SaiHandle::Config::Peripheral::SAI_2;
        sc.sr              = SaiHandle::Config::SampleRate::SAI_48KHZ;
        sc.bit_depth       = SaiHandle::Config::BitDepth::SAI_24BIT;
        sc.a_sync          = SaiHandle::Config::Sync::MASTER;
        sc.b_sync          = SaiHandle::Config::Sync::SLAVE;
        sc.a_dir           = SaiHandle::Config::Direction::TRANSMIT;
        sc.b_dir           = SaiHandle::Config::Direction::RECEIVE;
        sc.pin_config.fs   = pins::kSaiFs;
        sc.pin_config.sck  = pins::kSaiSck;
        sc.pin_config.sa   = pins::kSaiTx;
        sc.pin_config.sb   = pins::kSaiRx;
        sc.pin_config.mclk = pins::kSaiMclk; // not wired (the codec makes its clock from BCLK); TouchInit takes the pin back
        SaiHandle sai2;
        sai2.Init(sc);
        AudioHandle::Config ac;
        ac.blocksize  = 48;
        ac.samplerate = SaiHandle::Config::SampleRate::SAI_48KHZ;
        ac.postgain   = 1.f;
        hw.audio_handle.Init(ac, sai2);
        I2CHandle::Config ic;
        ic.periph         = I2CHandle::Config::Peripheral::I2C_1;
        ic.speed          = I2CHandle::Config::Speed::I2C_400KHZ;
        ic.mode           = I2CHandle::Config::Mode::I2C_MASTER;
        ic.pin_config.scl = pins::kScl;
        ic.pin_config.sda = pins::kSda;
        i2c.Init(ic);
    }

    enc[0].Init(pins::kPg1A, pins::kPg1B, pins::kPg1Sw);
    enc[1].Init(pins::kPg2A, pins::kPg2B, pins::kPg2Sw);
    enc[2].Init(pins::kPg3A, pins::kPg3B, pins::kPg3Sw);
    enc[3].Init(pins::kPg4A, pins::kPg4B, pins::kPg4Sw);
    fs[0].Init(pins::kFs1);
    fs[1].Init(pins::kFs2);
    fs[2].Init(pins::kFs3);
    core.Init(hw.AudioSampleRate(), framebuffer);
    core.SetDeviceId(HAL_GetUIDw0() ^ HAL_GetUIDw1() ^ HAL_GetUIDw2()); // this pedal's id (config: about)
    memset(&blob, 0, sizeof(blob));
    storage.Init(blob, kStateOffset);
    if(storage.GetState() == PersistentStorage<StateBlob>::State::USER) // something was saved: bring it back
        core.LoadState(storage.GetSettings().data, pg::Core::kStateBytes);

    TouchInit();
    lcd.Init({pins::kLcdCs, pins::kLcdDc, pins::kLcdRst, pins::kLcdLed, pins::kLcdSck, pins::kLcdMosi}, kFlipScreen, core.ScreenFast());
    lcd.Backlight(false); // dark until the first real frame is on the glass (no flash of garbage)

    hw.StartAudio(AudioCallback); // the bit clock is running now: the codec's PLL can lock on it
    bool codec_ok = codec.Init(&i2c);
    if(!codec_ok)
        core.ReportCodecFault();
    afx.Init(&i2c); // only answers if an add-on board with an MCP4461 sits in the fx loop (J22); harmless if not
    page_sel.Find(i2c);   // the page selector's PCF8574 (if it's plugged in)
    leveller.Init(&i2c);  // the analog leveller (its DAC powers up at 0 V: LEDs dark, sound untouched)
    uint32_t last_sel = 0;
    const uint32_t audio_t0 = System::GetNow();
    WatchdogStart();

    const Ili9341::Pins lcd_pins = {pins::kLcdCs, pins::kLcdDc, pins::kLcdRst, pins::kLcdLed, pins::kLcdSck, pins::kLcdMosi};
    uint32_t            last_touch = 0, last_refresh = 0, last_repush = 0;
    bool                backlight = true, screen_fast = core.ScreenFast();
    while(1)
    {
        if(core.WantsFlashMode())
        {
            hw.StopAudio();
            lcd.Fill(0, 0, pg::Canvas::kW, pg::Canvas::kH, pg::Canvas::Rgb(0, 0, 170));
            lcd.Text(12, 100, "usb flash mode", Font_11x18, pg::Canvas::Rgb(255, 255, 85), pg::Canvas::Rgb(0, 0, 170));
            System::Delay(800);
            lcd.Sleep(); // panel off cleanly before the reset
#ifdef BOOT_APP
            System::ResetToBootloader(System::DAISY_INFINITE_TIMEOUT); // Daisy bootloader: `make program-dfu`
#else
            System::ResetToBootloader(); // STM32 DFU
#endif
        }
        WatchdogKick();
        if(System::GetNow() - last_sel >= 30) // the page selector, ~33 times a second
        {
            last_sel = System::GetNow();
            core.PageSelector(page_sel.Read(i2c), last_sel);
            // gentle 2:1 above -14 dBFS rms: the LDRs ride the level in the analog path. Dark for the first 10 s (its
            // 10 uF capacitors finish charging through the LDRs' 100k: a squeeze before that would thump)
            const float db  = 10.f * log10f(out_ms + 1e-12f);
            const float cut = core.LevellerOn() && last_sel > 10000 && db > -14.f ? (db + 14.f) * 0.5f : 0.f;
            if(leveller.Present())
                leveller.SetCut(cut > 20.f ? 20.f : cut);
            // the face lights: green = signal (above -45 dBFS peak), red = within 3 dB (in) / 1 dB (out) of clipping,
            // held 300 ms so a single hit is seen
            static uint32_t in_hot_t = 0, out_hot_t = 0;
            const float     ip = in_peak, opk = out_peak;
            in_peak = 0.f, out_peak = 0.f;
            if(ip > 0.708f)
                in_hot_t = last_sel;
            if(opk > 0.891f)
                out_hot_t = last_sel;
            uint8_t lights = 0;
            lights |= ip > 0.0056f ? 1 : 0;
            lights |= last_sel - in_hot_t < 300 && in_hot_t ? 2 : 0;
            lights |= opk > 0.0056f ? 4 : 0;
            lights |= last_sel - out_hot_t < 300 && out_hot_t ? 8 : 0;
            page_sel.Lights(i2c, core.LightsOn() ? lights : 0);
            core.ReportLeveller(leveller.Present(), cut > 20.f ? 20.f : cut, db, lights);
        }
        const uint32_t now = System::GetNow();
        // ---- display safety
        if(lcd.Faulted() || core.ScreenFast() != screen_fast) // SPI failing, or fast / safe changed: start over
        {
            const bool fault = lcd.Faulted();
            screen_fast      = core.ScreenFast();
            lcd.Init(lcd_pins, kFlipScreen, screen_fast);
            if(!fault)
            {
                core.RepushScreen();
                continue;
            }
            core.RepushScreen();
            core.ReportDisplayFault();
        }
        if(now - last_refresh >= 2000) // mode registers re-sent every 2 s
            last_refresh = now, lcd.Refresh();
        if(now - last_repush >= 60000) // every pixel re-sent once a minute
            last_repush = now, core.RepushScreen();
        if(core.BacklightOn() != backlight) // display rest: backlight off after 20 idle minutes
            backlight = core.BacklightOn(), lcd.Backlight(backlight);
        if(now - last_touch >= 20) // ~50 Hz touch scan
        {
            last_touch = now;
            int        x = 0, y = 0;
            const bool down = TouchRead(x, y);
            core.Touch(down, x, y, now);
        }
        // ---- isolated audio: nothing here sets a level. Both knobs are analog gain stages on the carrier board
        // (centre click = unity); the codec runs at one fixed gain. The firmware only unmutes once after power-up.
        static uint32_t last_alive = 0;
        static bool     unmuted    = false;
        if(!unmuted && codec_ok && now - audio_t0 > 600) // the headphone amp's own power-up mute is over
            unmuted = codec.SetMute(false), g_out = kOutGain;
        if(now - last_alive >= 1000) // the codec must keep answering; if it stops, set it up again
        {
            last_alive = now;
            if(!codec.Alive())
            {
                core.ReportCodecFault();
                codec_ok = codec.Init(&i2c), unmuted = false;
            }
            else if(!codec_ok)
                codec_ok = codec.Init(&i2c);
            else if(codec.Guard() > 0) // a gain inside the codec had changed: put back (and say so on the health tab)
                core.ReportCodecFault();
        }
        if(core.WantsSave(now)) // 4 s after the last change: write it to the flash (only if it differs)
        {
            memset(&blob, 0, sizeof(blob));
            if(core.SaveState(blob.data, pg::Core::kStateBytes) > 0)
            {
                storage.GetSettings() = blob;
                storage.Save();
            }
            core.SaveDone();
        }
        core.DrawUi(lcd, now);
        if(backlight && now > 300)
            lcd.Backlight(true);
    }
}

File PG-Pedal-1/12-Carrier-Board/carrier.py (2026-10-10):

#!/usr/bin/env python3
"""PG-1 carrier board, v3: ONE isolated stereo input + ONE isolated stereo output (chosen 2026-10-08).

Everything that touches a jack sits on the ISOLATED side, with its own power and ground (IGND): a TLV320AIC3204 audio
chip (mic / guitar / line / headphone-out levels in; headphones or line out), an input buffer, and protection. The
audio crosses to the pedal as digital data only: ISO7741 (I2S) + ISO1540 (I2C), powered across by a B0505S. Nothing
the jacks connect to has a wire path into the pedal, not even ground.

The pedal side: 9 V in (fuse, reverse-polarity, surge), 5 V + 3.3 V and the isolators' pedal halves.

BOTH LEVELS ARE ANALOG: pg-line (input gain) and pg-hp (output gain) are centre-detent dual linear pots that set the
gain of op-amp stages in the signal path, on the isolated side. Centre click = unity ("whatever comes in goes out,
processed"), left = less, right = more. No software sets a level, so a crash can't make it loud.

DESIGN.md explains it. make_board.py turns this into the board, make_jlc.py into JLCPCB's files.
Nets are plain strings. The old 4-jack analog board is carrier_v2.py."""

# Seed3 pin -> what it is (05-Wiring-and-Schematics/WIRING.md). v3: SAI2 on 32-35 + I2C1 on 12/13; the Seed3's own
# audio pins (16-19) are not used.
SEED = {1: "LCD_RESET", 2: "PG1_A", 3: "PG1_B", 4: "PG1_PUSH", 5: "PG2_A", 6: "PG2_B", 7: "PG2_PUSH", 8: "LCD_CS",
        9: "LCD_SCK", 10: "PGC", 11: "LCD_SDI", 12: "SEED_SCL", 13: "SEED_SDA", 14: "PG3_A", 15: "PG3_B",
        16: "NC_AUDIO_IN_1", 17: "NC_AUDIO_IN_2", 18: "NC_AUDIO_OUT_1", 19: "NC_AUDIO_OUT_2", 20: "AGND", 21: "3V3A",
        22: "PG3_PUSH", 23: "LCD_LED", 24: "PGA", 25: "PGB", 26: "PG4_A", 27: "PG4_B", 28: "PG4_PUSH",
        29: "T_CLK", 30: "T_CS", 31: "T_DIN", 32: "SEED_RX", 33: "SEED_TX", 34: "SEED_FS", 35: "SEED_SCK",
        36: "T_DO", 37: "LCD_DC", 38: "3V3D", 39: "VIN", 40: "DGND"}

parts = []   # (ref, value, footprint, mpn, {pin: net}, note)


def P(ref, value, fp, mpn, pins, note=""):
    parts.append((ref, value, fp, mpn, pins, note))


R0603, R1206 = "Resistor_SMD:R_0603_1608Metric", "Resistor_SMD:R_1206_3216Metric"
C0603, C0805, C1206 = "Capacitor_SMD:C_0603_1608Metric", "Capacitor_SMD:C_0805_2012Metric", "Capacitor_SMD:C_1206_3216Metric"
SOIC8 = "Package_SO:SOIC-8_3.9x4.9mm_P1.27mm"
HDR_RA = lambda n: f"Connector_PinHeader_2.54mm:PinHeader_1x{n:02d}_P2.54mm_Horizontal"
JACK = "Connector_Audio:Jack_6.35mm_Neutrik_NMJ6HFD2_Horizontal"   # plastic nose: the sleeve never touches the box

# ================================================================ PEDAL SIDE (ground: GND)
P("J10", "seed3 + 9v", HDR_RA(10), "",
  {1: "+9V_RAW", 2: "GND", 3: "+9V", 4: "GND", 5: "SEED_SCL", 6: "SEED_SDA", 7: "SEED_SCK", 8: "SEED_FS", 9: "SEED_TX", 10: "SEED_RX"},
  "2 wires from the panel DC jack (centre negative: centre -> pin 2), then 8 jumpers to the Seed3: 39 VIN, 40 DGND, "
  "12 SCL, 13 SDA, 35 SAI2 SCK, 34 SAI2 FS, 33 SAI2 SD A (Seed3 out), 32 SAI2 SD B (Seed3 in)")
P("J21", "expansion", HDR_RA(4), "", {1: "+3V3", 2: "GND", 3: "SEED_SCL", 4: "SEED_SDA"},
  "the module bay in the left wall: 3.3 V, ground and the Seed3's I2C (buttons / switches / faders on I2C chips)")
P("F1", "PTC 300mA", "Fuse:Fuse_1206_3216Metric", "1206L030/24NR", {1: "+9V_RAW", 2: "+9V_F"})
P("D1", "B5819W", "Diode_SMD:D_SOD-123", "B5819W", {1: "+9V", 2: "+9V_F"}, "reverse-polarity protection, 1 A (cathode = pin 1)")
P("D2", "PSM712", "Package_TO_SOT_SMD:SOT-23", "PSM712-LF-T7", {1: "+9V", 2: "+9V", 3: "GND"}, "surge clamp (12 V stand-off; D1 keeps reverse off it)")
P("C1", "22uF 25V", C1206, "CL31A226KAHNNNE", {1: "+9V", 2: "GND"})
SOT223 = "Package_TO_SOT_SMD:SOT-223-3_TabPin2"
P("U1", "AMS1117-5.0", SOT223, "AMS1117-5.0", {1: "GND", 2: "+5V", 3: "+9V"}, "5 V for the isolated supply")
P("C2", "22uF 25V", C1206, "CL31A226KAHNNNE", {1: "+5V", 2: "GND"})
P("U2", "XC6206P332MR", "Package_TO_SOT_SMD:SOT-23", "XC6206P332MR-G", {1: "GND", 2: "+3V3", 3: "+5V"},
  "3.3 V for the isolators' pedal halves (~10 mA)")
P("C3", "4.7uF", C0805, "CL21A475KAQNNNE", {1: "+3V3", 2: "GND"})
P("R3", "4.7k", R0603, "", {1: "+3V3", 2: "SEED_SCL"}, "I2C pull-ups, pedal side")
P("R4", "4.7k", R0603, "", {1: "+3V3", 2: "SEED_SDA"})

# ================================================================ THE BARRIER (each part has one half on each side)
P("U3", "B0505S-1WR3", "PG1:DCDC_SIP4_B0505S", "B0505S-1WR3", {1: "GND", 2: "+5V", 3: "IGND", 4: "ISO5V_RAW"},
  "isolated 5 V, 1 W, 1 kV")
P("C7", "10uF 25V", C0805, "CL21A106KAYNNNE", {1: "+5V", 2: "GND"})
P("C8", "10uF 25V", C0805, "CL21A106KAYNNNE", {1: "ISO5V_RAW", 2: "IGND"})
P("U4", "ISO7741", "Package_SO:SOIC-16W_7.5x10.3mm_P1.27mm", "ISO7741DWR",
  {1: "+3V3", 2: "GND", 3: "SEED_SCK", 4: "SEED_FS", 5: "SEED_TX", 6: "SEED_RX", 7: "+3V3", 8: "GND",
   9: "IGND", 10: "ISO3V3", 11: "DOUT_X", 12: "DIN_X", 13: "WCLK_X", 14: "BCLK_X", 15: "IGND", 16: "ISO3V3"},
  "digital audio across: A bit clock, B word clock, C data to the codec; D data back")
P("C9", "100nF", C0603, "", {1: "+3V3", 2: "GND"}, "ISO7741 side 1")
P("C10", "100nF", C0603, "", {1: "ISO3V3", 2: "IGND"}, "ISO7741 side 2")
P("U5", "ISO1540", SOIC8, "ISO1540DR",
  {1: "+3V3", 2: "SEED_SDA", 3: "SEED_SCL", 4: "GND", 5: "IGND", 6: "ISCL", 7: "ISDA", 8: "ISO3V3"}, "I2C across (codec control)")
P("C11", "100nF", C0603, "", {1: "+3V3", 2: "GND"}, "ISO1540 side 1")
P("C12", "100nF", C0603, "", {1: "ISO3V3", 2: "IGND"}, "ISO1540 side 2")
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

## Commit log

2026-10-07 PG-1 pedal: hardware, firmware, plugin and tools
    A DIY stereo audio pedal on a Daisy Seed3 in a 1590XX: drill + UV print files, wiring diagram and
    wiring bench, the firmware (shared core) with its 15 tabs, the Carla/VST3 plugin with a 3D model,
    and the generator / uploader tools.
    [tayda-cart-import.csv, tayda-cart.csv, tayda-drill-holes.csv]
2026-10-07 Seed3 cartridge, multiband, version-proof saves, faster screen
    - Seed3 is now a plug-in cartridge in the left wall: a 19 x 52 mm window,
    socket board with 2 female headers on 4 M3 screws, keyed by pin 1.
    USB-C panel cable and foam tape removed; new seed-socket-board drawing.
    - Multiband dynamics tab, touch d-pad option, config save format 2
    (settings stored by name, survive firmware updates).
    - Screen link 6 -> 48 MHz with a fast/safe option, 60 fps UI pacing.
    - Fixes: false infrasonic-out mute on loud bass, plugin state kept
    across reloads.
    - Cart: socket parts and a USB-C soldering iron.
    [tayda-cart-import.csv, tayda-cart.csv, tayda-drill-holes.csv]
2026-10-07 Seed3 socket: stackable headers with long legs + heat shrink
    [tayda-cart-import.csv, tayda-cart.csv]
2026-10-07 Seed3 socket board: A-1192 pad-per-hole board, used whole
    The A-5465 joins holes with copper strips, which would short Seed3 pins.
    [tayda-cart-import.csv, tayda-cart.csv, tayda-drill-holes.csv]
2026-10-07 Seed3 socket way 1: glued block of jumper ends, no soldering at the socket
    The soldered socket board stays as an optional upgrade (way 2).
    [tayda-cart-import.csv, tayda-cart.csv]
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2026-10-07 Fit a $150 budget: cheaper cart, Amazon kit instead of the USB-C iron
    [tayda-cart-import.csv, tayda-cart.csv]
2026-10-07 Breadboard bench test (no soldering), soldering kit removed from the list
    [tayda-cart-benchtest-import.csv, tayda-cart-benchtest.csv]
2026-10-07 Seed3 socket: jumper ends glued half out of the wall; side screw holes removed
    [tayda-cart-import.csv, tayda-cart.csv, tayda-drill-holes.csv]
2026-10-08 PID auto-adjust tab; visualizer scope, bars and history views
    PID listens to the processed sound and steers the chosen groups (eq, comp,
    multiband, clarity, de-harsh, width) on top of the user's settings, with
    user P / I / D (0.00 allowed), safe ranges and no wind-up or drift in silence.
    [PgCore.h, PgDsp.h]
2026-10-08 Clarity: up to 10 self-placing bands; anti-duck in every stage
    Clarity bands find bulges and dips themselves and glide their own frequency,
    width and gain (cut or lift). Anti-duck: bass-free detectors for every
    whole-sound gain, a bass-first safety limiter, the false infrasonic mute on
    sudden bass fixed, and a final guard that lifts the mids/highs back if they
    still dip in bass-heavy moments. Bass-drop dips went from 7-12 dB to <= 0.3 dB.
    [PgCore.h, PgDsp.h]
2026-10-08 Seed3 load check + optimisation; plugin runs at the Seed3's 48 kHz / 48-sample blocks
    An emulated Cortex-M7 (_Tools/seed3-bench) showed the worst case needed
    102-153 % of the Seed3's audio time. Fast exp/log, single-output filter
    runs, slower-rate detectors, a sliding-minimum limiter and skipping idle
    filters bring it to ~59 % (defaults ~51 %). The plugin now runs the core
    exactly like the pedal and its cpu health check reports the Seed3 load.
    [PgDsp.h]
2026-10-08 v2 (in progress): pg- names, settings pages with swipe, rounded UI; new face layout (pots, jacks, pink), Seed3 on the right wall
    [tayda-cart-import.csv, tayda-cart.csv, tayda-drill-holes.csv]
2026-10-08 v2 (in progress): carrier board circuit, netlist and BOM; M11 PCB jack holes
    [carrier-bom.csv, tayda-drill-holes.csv]
2026-10-08 Carrier board: budget version (NE5532 + TPA6139A2, one 9 V supply); full version kept
    [carrier-bom.csv]
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2026-10-08 Carrier board v2: KiCad layout (auto-placed, Freerouting-routed, 0 DRC errors) and PCBWay files
    [pg1-carrier-bom.csv, pg1-carrier.kicad_pcb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]
2026-10-08 Carrier board: JLCPCB files (basic parts where possible), ceramic caps instead of electrolytics
    [carrier-bom.csv, pg1-carrier-bom-jlc.csv, pg1-carrier-bom.csv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]
2026-10-08 Carrier board: all parts on one side, labels clear of pads, 0 DRC warnings
    [carrier-bom.csv, pg1-carrier-bom-jlc.csv, pg1-carrier-bom.csv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]
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2026-10-08 Carrier board: Neutrik NMJ6HCD2 jacks fitted by the assembler; jack holes 11.4 mm
    [carrier-bom.csv, pg1-carrier-bom-jlc.csv, pg1-carrier-bom.csv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]
2026-10-08 Carrier board: inputs left / outputs right with a diamond divider, (IN)/(OUT) labels, pg-1 artwork; face print IN/OUT tags
    [carrier-bom.csv, pg1-carrier-bom-jlc.csv, pg1-carrier.kicad_pcb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]
2026-10-08 Face print: pg- names and tagline in the mono font, small knobs centred between border and screen
    [tayda-drill-holes.csv]
2026-10-08 v3 isolated carrier board: one isolated stereo in + out (TLV320AIC3204 behind ISO7741 / ISO1540 / B0505S), analog centre-click gain knobs, firmware SAI2 + codec, face print and drill to match
    [carrier-bom.csv, pg1-carrier-bom-jlc.csv, pg1-carrier-bom.csv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]
2026-10-08 Carrier: analog fx (MCP4461 level + low-pass, TLV9062), expansion header + left-wall bay, re-route
    [carrier-bom.csv, jlc_rotations.csv, pg1-carrier-bom-jlc.csv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]
2026-10-08 Carrier: cheaper isolated board (fx loop header instead of analog fx, basic-part clamps), all parts fitted
    [carrier-bom.csv, jlc_rotations.csv, pg1-carrier-bom-jlc.csv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]
2026-10-09 Carrier: ~$50 build (TLV9062, XC6206 basic parts, through-hole parts hand-soldered)
    [carrier-bom.csv, pg1-carrier-bom-jlc.csv, pg1-carrier-bom.csv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]
2026-10-09 Cart: carrier headers from Tayda, second jumper pack; fx loop bridged with jumper wires
    [tayda-cart-import.csv, tayda-cart.csv]
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2026-10-09 Carrier: pot header labels fixed (right = more); UI: tab descriptions, pg-b next page; board exporter for the simulator
    [pg1-carrier.kicad_pcb]
2026-10-09 Carrier: press-fit (locking) header holes; board simulator work in progress
    [pg1-carrier.kicad_pcb]
2026-10-09 Carrier: simulation found the input 3.2 kHz low-pass (C31/C41 not fitted); part labels; firmware input gain; plugin face fixed
    [carrier-bom.csv, pg1-carrier-bom-jlc.csv, pg1-carrier-bom.csv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]
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2026-10-09 Page selector (8-way chicken head picks the settings page), gain knobs under the jacks, analog opto leveller add-on
    [tayda-cart-import.csv, tayda-cart.csv, tayda-drill-holes.csv]
2026-10-09 Analog leveller on the carrier board (LED/LDR vactrols, MCP4725, TLV9062), fx loop left open, simulated
    [carrier-bom.csv, pg1-carrier-bom-jlc.csv, pg1-carrier.kicad_pcb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]
2026-10-09 Power switch, re-centred header holes, input headroom + ADC range + power-on thump fixes found by scenario simulation
    [carrier-bom.csv, pg1-carrier-bom-jlc.csv, pg1-carrier.kicad_pcb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]
2026-10-10 Hard input clamp and output ceiling, guitar-friendly input, firmware codec guard; black chicken heads for power + page (measured sweeps), 9 V jack in the left wall
    [carrier-bom.csv, pg1-carrier-bom-jlc.csv, pg1-carrier.kicad_pcb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]
2026-10-10 No Mouser: JLCPCB fits the B0505S and jacks, gain pots from Tayda (A-8618)
    [pg1-carrier-bom-jlc.csv, tayda-cart-import.csv, tayda-cart.csv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]
2026-10-10 Pink chicken heads fitted (measured sweeps), JLC fits only the B0505S, jacks hand-soldered
    [pg1-carrier-bom-jlc.csv, tayda-cart-import.csv, tayda-cart.csv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]
2026-10-10 Level chicken heads with dial arcs, LDR A-7629, any PCF8574 board
    [tayda-cart-import.csv, tayda-cart.csv, tayda-drill-holes.csv]
2026-10-10 Border clear of the gain knobs, corner post audit, leveller light pairs optional
    [tayda-cart-import.csv, tayda-cart.csv]
2026-10-10 Level lights, leveller toggle + live view, full point-to-point wiring drawing
    [tayda-cart-import.csv, tayda-cart.csv, tayda-drill-holes.csv]
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2026-10-10 47 ohm headphone power cap, power dial ON zone, wiring pictures
    [pg1-carrier-bom-jlc.csv, pg1-carrier.kicad_pcb]
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
